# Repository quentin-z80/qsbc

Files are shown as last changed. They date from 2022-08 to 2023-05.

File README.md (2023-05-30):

# qsbc

## Specs

- i.MX8M Mini 4x 1.8GHz ARM Cortex-A53
- 4GB LPDDR4
- 4MB QSPI Flash
- 64GB eMMC
- M.2 2230 Slot
- MicroSD card slot
- 2x USB Type-C DRP
- USB Type-C Power in
- USB Type-C debug port
- 10/100/1000 Ethernet
- Displayport output





## Flashing u-boot

1. Get `u-boot`

    ```
    git clone https://gitlab.com/quentin-z80/u-boot.git
    ```

2. Build `TF-A`

    ```
    git clone https://git.trustedfirmware.org/TF-A/trusted-firmware-a.git
    cd trusted-firmware-a
    TF_LDFLAGS="--no-warn-rwx-segment" make plat=imx8mm bl31
    cp build/imx8mm/release/bl31.bin ../u-boot/
    ```

3. Get i.MX8MM DDR Firmware

    ```
    wget https://www.nxp.com/lgfiles/NMG/MAD/YOCTO/firmware-imx-8.9.bin
    chmod +x firmware-imx-8.9.bin
    ./firmware-imx-8.9.bin
    cp firmware-imx-8.9/firmware/ddr/synopsys/lpddr4*.bin u-boot/
    ```

4. Build `u-boot` for SD card boot

    ```
    cd u-boot
    export CROSS_COMPILE=aarch64-linux-gnu- ARCH=arm64
    make qsbc_imx8mm_defconfig
    make
    sudo dd if=flash.bin of=/dev/mmcblk0 bs=1024 seek=32 conv=notrunc
    ```

5. Flash and boot `u-boot` from sd card

    ```
    sudo dd if=flash.bin of=/dev/mmcblk0 bs=1024 seek=32 conv=notrunc
    sudo tio -b 115200 /dev/ttyACM0
    ```

6. Build `u-boot` for QSPI boot

    ```
    make qsbc_imx8mm_fspi_defconfig
    make
    ```

7. Flash `u-boot` to QSPI

    ```
    u-boot=> run dfuspi
    sudo dfu-util -D flash.bin
    ```

## TODO

- USB-UART ICs need to have VDDIO derived from USB VBUS so they do not reset
on board reset (or find a different ic)

- USB VBUS fault pins need to be connected to usb phy oc pads, not gpio pins

- UART1 TXO is connected to the wrong pad

- Test displayport out, waiting for better sn65dsi86 avalability

- optimize bom, replace 0201s with 0402s where there is space / no si limitations

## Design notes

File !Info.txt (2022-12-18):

/-----------------------------------------------------------------------------------------------------------------------------------\
|            |                  Single Ended                       |                        Differential                            |
|   Layer    |-----------------------------------------------------|----------------------------------------------------------------|
|            |  Width (mm)  |  Impedance (Ohms)  |    Ref Plane    |  Width (mm)  |  Space (mm)  |  Impedance (Ohms)  |  Ref Plane  |
|------------|--------------|--------------------|-----------------|--------------|--------------|--------------------|-------------|
|            |  0.11        |       50R          |     L2_IN1      |    0.08      |   0.15       |       100R         |   L2_IN1    |
|  L1_TOP    |              |                    |                 |    0.1       |   0.15       |        90R         |   L2_IN1    |
|            |              |                    |                 |    0.11      |   0.15       |        85R         |   L2_IN1    |
|------------|--------------|--------------------|-----------------|--------------|--------------|--------------------|-------------|
|  L3_IN2    |  0.08        |       50R          | L2_IN1 / L4_IN3 |              |              |                    |             |
|------------|--------------|--------------------|-----------------|--------------|--------------|--------------------|-------------|
|            |  0.11        |       50R          |     L7_IN6      |    0.08      |   0.15       |       100R         |   L7_IN6    |
|  L8_BOTTOM |              |                    |                 |    0.1       |   0.15       |        90R         |   L7_IN6    |
|            |              |                    |                 |    0.11      |   0.15       |        85R         |   L7_IN6    |
\-----------------------------------------------------------------------------------------------------------------------------------/

PCB Thickness - 1.2mm +/- 10%
Size: 80x80mm
Layers: 8
Min Trace Width / Space: 0.762mm
Min Via: 0.2mm drill, 0.4mm pad
Plating: ENIG
Soldermask: Green
Silkscreen: White, Top and Bottom

Stackup:

/--------------------------------------------------\
|         |            |        |           |      |
|  Layer  |  Material  |  Type  | Thickness |  Dk  |
|         |            |        |           |      |
|--------------------------------------------------|
|   L1    |   Copper   | Signal |  1oz      |      |
|---------|------------|--------|-----------|------|
| Prepreg |   370HR    |        |  0.07mm   | 4.04 |
|---------|------------|--------|-----------|------|
|   L2    |   Copper   |  GND   |  1oz      |      |
|---------|------------|--------|-----------|------|
|  Core   |   370HR    |        |  0.12mm   | 4.04 |
|---------|------------|--------|-----------|------|
|   L3    |   Copper   | Signal |  1oz      |      |
|---------|------------|--------|-----------|------|
| Prepreg |   370HR    |        |  0.16mm   | 4.04 |
|---------|------------|--------|-----------|------|
|   L4    |   Copper   |  GND   |  1oz      |      |
|---------|------------|--------|-----------|------|
|  Core   |   370HR    |        |  0.3mm    | 4.04 |
|---------|------------|--------|-----------|------|
|   L5    |   Copper   |  PWR   |  1oz      |      |
|---------|------------|--------|-----------|------|
| Prepreg |   370HR    |        |  0.16mm   | 4.04 |
|---------|------------|--------|-----------|------|
|   L6    |   Copper   |  PWR   |  1oz      |      |
|---------|------------|--------|-----------|------|
|  Core   |   370HR    |        |  0.12mm   | 4.04 |
|---------|------------|--------|-----------|------|
|   L7    |   Copper   |  GND   |  1oz      |      |
|---------|------------|--------|-----------|------|
| Prepreg |   370HR    |        |  0.07mm   | 4.04 |
|---------|------------|--------|-----------|------|
|   L8    |   Copper   | Signal |  1oz      |      |
\--------------------------------------------------/

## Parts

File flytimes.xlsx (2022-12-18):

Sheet: DDR_A
Group | Net | Vias | Layers | Track Length | Via Length | Total Length | Track Delay | Via Delay | Package Delay | Extra Delay | Total Delay | Notes
Clock | DRAM_CK_A_N | 2 | F.Cu, B.Cu | 19.58 | 2.4 | 21.98 | 109.55 | 31.84 | 41.2 | -2.81 | 179.78
Clock | DRAM_CK_A_P | 2 | F.Cu, B.Cu | 19.56 | 2.4 | 21.96 | 109.33 | 31.84 | 41.1 | -2.81 | 179.46
Byte Lane 1 – DQS | DRAM_DQS1_A_N | 2 | F.Cu, B.Cu | 11.87 | 2.4 | 14.27 | 66.39 | 31.84 | 47.2 | 0 | 145.43
Byte Lane 1 – DQS | DRAM_DQS1_A_P | 2 | F.Cu, B.Cu | 11.6 | 2.4 | 14 | 64.89 | 31.84 | 48.6 | 0 | 145.33
Byte Lane 1 | DRAM_D11_A | 0 | F.Cu | 17.59 | 0 | 17.59 | 98.22 | 0 | 47.2 | 0 | 145.42
Byte Lane 1 | DRAM_D12_A | 0 | F.Cu | 18.84 | 0 | 18.84 | 105.12 | 0 | 40.3 | 0 | 145.42
Byte Lane 1 | DRAM_DMI1_A | 0 | F.Cu | 15.53 | 0 | 15.53 | 86.75 | 0 | 58.6 | 0 | 145.35
Byte Lane 1 | DRAM_D15_A | 0 | F.Cu | 16.65 | 0 | 16.65 | 92.94 | 0 | 52.4 | 0 | 145.34
Byte Lane 1 | DRAM_D13_A | 0 | F.Cu | 17.28 | 0 | 17.28 | 96.54 | 0 | 48.8 | 0 | 145.34
Byte Lane 1 | DRAM_D08_A | 0 | F.Cu | 17.97 | 0 | 17.97 | 100.32 | 0 | 45 | 0 | 145.32
Byte Lane 1 | DRAM_D09_A | 0 | F.Cu | 17.05 | 0 | 17.05 | 95.19 | 0 | 50.1 | 0 | 145.29
Byte Lane 1 | DRAM_D10_A | 0 | F.Cu | 17.74 | 0 | 17.74 | 99.09 | 0 | 46.2 | 0 | 145.29
Byte Lane 1 | DRAM_D14_A | 0 | F.Cu | 15.55 | 0 | 15.55 | 86.87 | 0 | 58.4 | 0 | 145.27
Byte Lane 0 – DQS | DRAM_DQS0_A_P | 2 | F.Cu, B.Cu | 17.7 | 2.4 | 20.1 | 99.04 | 31.84 | 59 | 0 | 189.88
Byte Lane 0 – DQS | DRAM_DQS0_A_N | 2 | F.Cu, B.Cu | 17.7 | 2.4 | 20.1 | 98.94 | 31.84 | 58.9 | 0 | 189.68
Byte Lane 0 | DRAM_D03_A | 2 | F.Cu, In2.Cu | 20.48 | 0.4 | 20.88 | 134.13 | 4.01 | 51.7 | 0 | 189.84
Byte Lane 0 | DRAM_D07_A | 2 | F.Cu, In2.Cu | 20.76 | 0.4 | 21.16 | 134.4 | 4.01 | 51.4 | 0 | 189.81
Byte Lane 0 | DRAM_D05_A | 2 | F.Cu, In2.Cu | 19.49 | 0.4 | 19.89 | 127.69 | 4.01 | 58.1 | 0 | 189.8
Byte Lane 0 | DRAM_D04_A | 2 | F.Cu, In2.Cu | 19.15 | 0.4 | 19.55 | 125.88 | 4.01 | 59.9 | 0 | 189.79
Byte Lane 0 | DRAM_D02_A | 2 | F.Cu, In2.Cu | 20.02 | 0.4 | 20.42 | 131.15 | 4.01 | 54.6 | 0 | 189.76
Byte Lane 0 | DRAM_DMI0_A | 2 | F.Cu, In2.Cu | 19.49 | 0.4 | 19.89 | 128.39 | 4.01 | 57.2 | 0 | 189.6
Byte Lane 0 | DRAM_D00_A | 2 | F.Cu, In2.Cu | 21.85 | 0.4 | 22.25 | 143.01 | 4.01 | 42.7 | 0 | 189.72
Byte Lane 0 | DRAM_D01_A | 2 | F.Cu, In2.Cu | 22.23 | 0.4 | 22.63 | 142.7 | 4.01 | 43 | 0 | 189.71
Byte Lane 0 | DRAM_D06_A | 2 | F.Cu, In2.Cu | 18.73 | 0.4 | 19.13 | 121.06 | 4.01 | 64.6 | 0 | 189.67
Address, Command and Control | DRAM_CA3_A | 2 | F.Cu, In2.Cu | 18.49 | 0.4 | 18.89 | 122.87 | 4.01 | 59.7 | 0 | 186.58
Address, Command and Control | ~{DRAM_CS1_A} | 2 | F.Cu, In2.Cu | 20.79 | 0.4 | 21.19 | 138.35 | 4.01 | 44.2 | 0 | 186.56
Address, Command and Control | DRAM_CA1_A | 2 | F.Cu, In2.Cu | 23.05 | 0.4 | 23.45 | 153.43 | 4.01 | 29.1 | 0 | 186.54
Address, Command and Control | DRAM_CA4_A | 2 | F.Cu, In2.Cu | 22.35 | 0.4 | 22.75 | 148.72 | 4.01 | 33.8 | 0 | 186.53
Address, Command and Control | ~{DRAM_CS0_A} | 2 | F.Cu, In2.Cu | 22.03 | 0.4 | 22.43 | 146.6 | 4.01 | 35.9 | 0 | 186.51
Address, Command and Control | DRAM_CA2_A | 2 | F.Cu, In2.Cu | 19.2 | 0.4 | 19.6 | 127.66 | 4.01 | 54.8 | 0 | 186.47
Address, Command and Control | DRAM_CA5_A | 2 | F.Cu, In2.Cu | 22.59 | 0.4 | 22.99 | 150.45 | 4.01 | 32 | 0 | 186.46
Address, Command and Control | DRAM_CKE0_A | 2 | F.Cu, In2.Cu, B.Cu | 20.14 | 1.4 | 21.54 | 133.54 | 17.92 | 51.2 | -16.23 | 186.43
Address, Command and Control | DRAM_CA0_A | 2 | F.Cu, In2.Cu | 21.47 | 0.4 | 21.87 | 142.81 | 4.01 | 39.6 | 0 | 186.42
Address, Command and Control | DRAM_CKE1_A | 2 | F.Cu, In2.Cu, B.Cu | 21.82 | 1.4 | 23.22 | 144.79 | 17.92 | 39.9 | -16.23 | 186.38

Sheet: DDR_B
Group | Net | Vias | Layers | Track Length | Via Length | Total Length | Track Delay | Via Delay | Package Delay | Extra Delay | Total Delay | Notes
Clock | DRAM_CK_B_N | 2 | F.Cu, B.Cu | 19.43 | 2.4 | 21.83 | 108.71 | 31.84 | 42.2 | -2.81 | 179.94
Clock | DRAM_CK_B_P | 2 | F.Cu, B.Cu | 19.51 | 2.4 | 21.91 | 109.03 | 31.84 | 41.8 | -2.81 | 179.86
Byte Lane 1 – DQS | DRAM_DQS1_B_P | 2 | F.Cu, B.Cu | 18.75 | 2.4 | 21.15 | 104.86 | 31.84 | 55.5 | 0 | 192.2
Byte Lane 1 – DQS | DRAM_DQS1_B_N | 2 | F.Cu, B.Cu | 18.83 | 2.4 | 21.23 | 105.25 | 31.84 | 55 | 0 | 192.09
Byte Lane 1 | DRAM_D08_B | 2 | F.Cu, In2.Cu | 19.43 | 0.4 | 19.83 | 128.14 | 4.01 | 60.2 | 0 | 192.35
Byte Lane 1 | DRAM_D12_B | 2 | F.Cu, In2.Cu | 19.86 | 0.4 | 20.26 | 129.31 | 4.01 | 59.1 | 0 | 192.42
Byte Lane 1 | DRAM_D13_B | 2 | F.Cu, In2.Cu | 20.08 | 0.4 | 20.48 | 130.32 | 4.01 | 58.1 | 0 | 192.43
Byte Lane 1 | DRAM_D10_B | 2 | F.Cu, In2.Cu | 21.62 | 0.4 | 22.02 | 139.44 | 4.01 | 48.8 | 0 | 192.25
Byte Lane 1 | DRAM_D14_B | 2 | F.Cu, In2.Cu | 20.89 | 0.4 | 21.29 | 138.24 | 4.01 | 50 | 0 | 192.25
Byte Lane 1 | DRAM_D09_B | 2 | F.Cu, In2.Cu | 20.78 | 0.4 | 21.18 | 136.92 | 4.01 | 51.3 | 0 | 192.23
Byte Lane 1 | DRAM_D11_B | 2 | F.Cu, In2.Cu | 19.94 | 0.4 | 20.34 | 130.2 | 4.01 | 58 | 0 | 192.21
Byte Lane 1 | DRAM_DMI1_B | 2 | F.Cu, In2.Cu | 20.41 | 0.4 | 20.81 | 135.06 | 4.01 | 53.1 | 0 | 192.17
Byte Lane 1 | DRAM_D15_B | 2 | F.Cu, In2.Cu | 21.96 | 0.4 | 22.36 | 143.93 | 4.01 | 44.2 | 0 | 192.14
Byte Lane 0 – DQS | DRAM_DQS0_B_P | 2 | F.Cu, B.Cu | 10.73 | 2.4 | 13.13 | 60.01 | 31.84 | 48.6 | 0 | 140.45
Byte Lane 0 – DQS | DRAM_DQS0_B_N | 2 | F.Cu, B.Cu | 10.71 | 2.4 | 13.11 | 59.93 | 31.84 | 48.6 | 0 | 140.37
Byte Lane 0 | DRAM_D06_B | 0 | F.Cu | 15.35 | 0 | 15.35 | 85.72 | 0 | 54.7 | 0 | 140.42
Byte Lane 0 | DRAM_D05_B | 0 | F.Cu | 16.22 | 0 | 16.22 | 90.6 | 0 | 49.8 | 0 | 140.4
Byte Lane 0 | DRAM_D03_B | 0 | F.Cu | 17.63 | 0 | 17.63 | 98.4 | 0 | 42 | 0 | 140.4
Byte Lane 0 | DRAM_D04_B | 0 | F.Cu | 15.55 | 0 | 15.55 | 86.79 | 0 | 53.6 | 0 | 140.39
Byte Lane 0 | DRAM_D00_B | 0 | F.Cu | 15.92 | 0 | 15.92 | 88.85 | 0 | 51.5 | 0 | 140.35
Byte Lane 0 | DRAM_D02_B | 0 | F.Cu | 15.37 | 0 | 15.37 | 85.85 | 0 | 54.5 | 0 | 140.35
Byte Lane 0 | DRAM_D01_B | 0 | F.Cu | 16.2 | 0 | 16.2 | 90.44 | 0 | 49.9 | 0 | 140.34
Byte Lane 0 | DRAM_D07_B | 0 | F.Cu | 16.54 | 0 | 16.54 | 92.33 | 0 | 48 | 0 | 140.33
Byte Lane 0 | DRAM_DMI0_B | 0 | F.Cu | 15.66 | 0 | 15.66 | 87.47 | 0 | 52.8 | 0 | 140.27
Address, Command and Control | DRAM_CA2_B | 2 | F.Cu, In2.Cu | 17.71 | 0.4 | 18.11 | 117.61 | 4.01 | 59.5 | 0 | 181.12
Address, Command and Control | DRAM_CA3_B | 2 | F.Cu, In2.Cu | 18.16 | 0.4 | 18.56 | 120.61 | 4.01 | 56.5 | 0 | 181.12
Address, Command and Control | DRAM_CA0_B | 2 | F.Cu, In2.Cu | 21.82 | 0.4 | 22.22 | 145.15 | 4.01 | 31.9 | 0 | 181.06
Address, Command and Control | ~{DRAM_CS0_B} | 2 | F.Cu, In2.Cu | 20.6 | 0.4 | 21 | 137.04 | 4.01 | 40 | 0 | 181.05
Address, Command and Control | ~{DRAM_CS1_B} | 2 | F.Cu, In2.Cu | 19.46 | 0.4 | 19.86 | 129.33 | 4.01 | 47.7 | 0 | 181.04
Address, Command and Control | DRAM_CKE1_B | 2 | F.Cu, In2.Cu, B.Cu | 19.35 | 1.4 | 20.75 | 128.08 | 17.92 | 51.6 | -16.57 | 181.03
Address, Command and Control | DRAM_CA5_B | 2 | F.Cu, In2.Cu | 20.89 | 0.4 | 21.29 | 138.42 | 4.01 | 38.6 | 0 | 181.03
Address, Command and Control | DRAM_CKE0_B | 2 | F.Cu, In2.Cu, B.Cu | 19.35 | 1.4 | 20.75 | 128.08 | 17.92 | 51.6 | -16.57 | 181.03
Address, Command and Control | DRAM_CA1_B | 2 | F.Cu, In2.Cu | 21.44 | 0.4 | 21.84 | 142.61 | 4.01 | 34.4 | 0 | 181.02
Address, Command and Control | DRAM_CA4_B | 2 | F.Cu, In2.Cu | 21.45 | 0.4 | 21.85 | 142.71 | 4.01 | 34.3 | 0 | 181.02

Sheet: eMMC
Group | Net | Vias | Layers | Track Length | Via Length | Total Length | Track Delay | Via Delay | Package Delay | Extra Delay | Total Delay | Notes
eMMC | SD3_CMD | 0 | F.Cu | 27.49 | 0 | 27.49 | 153.61 | 0 | 0 | 0 | 153.61
eMMC | SD3_CLK | 0 | F.Cu | 23.96 | 0 | 23.96 | 133.66 | 0 | 0 | 19.98 | 153.64
eMMC | SD3_DATA3 | 0 | F.Cu | 26.32 | 0 | 26.32 | 147.01 | 0 | 0 | 0 | 147.01
eMMC | SD3_DATA7 | 0 | F.Cu | 27.4 | 0 | 27.4 | 153.19 | 0 | 0 | 0 | 153.19
eMMC | SD3_DATA1 | 0 | F.Cu | 27.28 | 0 | 27.28 | 152.53 | 0 | 0 | 0 | 152.53
eMMC | SD3_DATA4 | 0 | F.Cu | 27.28 | 0 | 27.28 | 152.5 | 0 | 0 | 0 | 152.5
eMMC | SD3_DATA0 | 0 | F.Cu | 27.18 | 0 | 27.18 | 151.92 | 0 | 0 | 0 | 151.92
eMMC | SD3_DATA6 | 0 | F.Cu | 27.05 | 0 | 27.05 | 151.21 | 0 | 0 | 0 | 151.21
eMMC | SD3_DATA2 | 0 | F.Cu | 27.03 | 0 | 27.03 | 151.12 | 0 | 0 | 0 | 151.12
eMMC | SD3_STROBE | 0 | F.Cu | 26.97 | 0 | 26.97 | 150.59 | 0 | 0 | 0 | 150.59
eMMC | SD3_DATA5 | 0 | F.Cu | 26.95 | 0 | 26.95 | 150.67 | 0 | 0 | 0 | 150.67

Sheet: ENET
Group | Net | Vias | Layers | Track Length | Via Length | Total Length | Track Delay | Via Delay | Package Delay | Extra Delay | Total Delay | Notes
RGMII – TX | ENET_TD3 | 2 | F.Cu, In2.Cu | 13.98 | 0.4 | 14.38 | 85.14 | 4.01 | 0 | 0 | 89.15
RGMII – TX | ENET_TXC | 2 | F.Cu, In2.Cu | 13 | 0.4 | 13.4 | 82.98 | 4.01 | 0 | 0 | 86.99
RGMII – TX | ENET_TD2 | 2 | F.Cu, In2.Cu | 13.37 | 0.4 | 13.77 | 83.73 | 4.01 | 0 | 0 | 87.74
RGMII – TX | ENET_TD0 | 2 | F.Cu, In2.Cu | 13.37 | 0.4 | 13.77 | 81.97 | 4.01 | 0 | 0 | 85.98
RGMII – TX | ENET_TD1 | 2 | F.Cu, In2.Cu | 13.48 | 0.4 | 13.88 | 81.55 | 4.01 | 0 | 0 | 85.56
RGMII – TX | ENET_TX_CTL | 2 | F.Cu, In2.Cu | 13.07 | 0.4 | 13.47 | 82.35 | 4.01 | 0 | 0 | 86.36
RGMII – RX | ENET_RX_CTL | 0 | F.Cu | 15.35 | 0 | 15.35 | 85.86 | 0 | 0 | 0 | 85.86
RGMII – RX | ENET_RXC | 2 | F.Cu, B.Cu | 13.5 | 2.4 | 15.9 | 75.54 | 31.84 | 0 | 0 | 107.38
RGMII – RX | ENET_RD3 | 0 | F.Cu | 16.41 | 0 | 16.41 | 91.7 | 0 | 0 | 0 | 91.7
RGMII – RX | ENET_RD2 | 0 | F.Cu | 15 | 0 | 15 | 83.79 | 0 | 0 | 0 | 83.79
RGMII – RX | ENET_RD0 | 0 | F.Cu | 14.94 | 0 | 14.94 | 83.57 | 0 | 0 | 0 | 83.57
RGMII – RX | ENET_RD1 | 2 | F.Cu, In2.Cu | 15.91 | 0.4 | 16.31 | 93.45 | 4.01 | 0 | 0 | 97.46
MDI3 | TRD3_P | 2 | F.Cu, B.Cu | 23.04 | 2.4 | 25.44 | 126.64 | 31.84 | 0 | 0 | 158.48
MDI3 | TRD3_N | 2 | F.Cu, B.Cu | 23.04 | 2.4 | 25.44 | 126.64 | 31.84 | 0 | 0 | 158.48
MDI2 | TRD2_P | 2 | F.Cu, B.Cu | 22.55 | 2.4 | 24.95 | 123.92 | 31.84 | 0 | 0 | 155.76
MDI2 | TRD2_N | 2 | F.Cu, B.Cu | 22.55 | 2.4 | 24.95 | 123.92 | 31.84 | 0 | 0 | 155.76
MDI1 | TRD1_P | 2 | F.Cu, B.Cu | 22.65 | 2.4 | 25.05 | 124.48 | 31.84 | 0 | 0 | 156.32
MDI1 | TRD1_N | 2 | F.Cu, B.Cu | 22.65 | 2.4 | 25.05 | 124.48 | 31.84 | 0 | 0 | 156.32
MDI0 | TRD0_P | 0 | F.Cu | 21.22 | 0 | 21.22 | 116.61 | 0 | 0 | 0 | 116.61
MDI0 | TRD0_N | 0 | F.Cu | 21.22 | 0 | 21.22 | 116.61 | 0 | 0 | 0 | 116.61

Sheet: SD
!# | Net | Vias | Layers | Track Length | Via Length | Total Length | Track Delay | Via Delay | Package Delay | Extra Delay | Total Delay | Notes
SD | SD2_CLK | 1 | F.Cu, B.Cu | 63.3 | 1.2 | 64.5 | 354.08 | 15.92 | 0 | 28.83 | 398.83
SD | SD2_CMD | 2 | F.Cu, B.Cu | 65.73 | 2.4 | 68.13 | 367.7 | 31.84 | 0 | 0 | 399.54
SD | SD2_DATA0 | 2 | F.Cu, B.Cu | 65.79 | 2.4 | 68.19 | 368 | 31.84 | 0 | 0 | 399.84
SD | SD2_DATA1 | 2 | F.Cu, B.Cu | 65.6 | 2.4 | 68 | 366.95 | 31.84 | 0 | 0 | 398.79
SD | SD2_DATA3 | 2 | F.Cu, B.Cu | 65.45 | 2.4 | 67.85 | 366.1 | 31.84 | 0 | 0 | 397.94
SD | SD2_DATA2 | 2 | F.Cu, B.Cu | 65.33 | 2.4 | 67.73 | 365.46 | 31.84 | 0 | 0 | 397.3

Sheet: QSPI
Group | Net | Vias | Layers | Track Length | Via Length | Total Length | Track Delay | Via Delay | Package Delay | Extra Delay | Total Delay | Notes
QSPI | ~{QSPI_CS0} | 2 | F.Cu, In2.Cu | 44.52 | 0.4 | 44.92 | 282.35 | 4.01 | 0 | 0 | 286.36
QSPI | QSPI_CLK | 2 | F.Cu, In2.Cu | 42.34 | 0.4 | 42.74 | 282.11 | 4.01 | 0 | 0 | 286.12
QSPI | QSPI_DATA0 | 2 | F.Cu, In2.Cu | 42.48 | 0.4 | 42.88 | 283.05 | 4.01 | 0 | 0 | 287.06
QSPI | QSPI_DATA1 | 2 | F.Cu, In2.Cu | 42.48 | 0.4 | 42.88 | 280.82 | 4.01 | 0 | 0 | 284.83
QSPI | QSPI_DATA2 | 2 | F.Cu, In2.Cu | 42.55 | 0.4 | 42.95 | 283.62 | 4.01 | 0 | 0 | 287.63
QSPI | QSPI_DATA3 | 2 | F.Cu, In2.Cu | 43.08 | 0.4 | 43.48 | 287.08 | 4.01 | 0 | 0 | 291.09

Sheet: USB
Group | Net | Vias | Layers | Track Length | Via Length | Total Length | Track Delay | Via Delay | Package Delay | Extra Delay | Total Delay | Notes
USB1 | USB1_DN | 2 | F.Cu, B.Cu | 96.57 | 2.4 | 98.97 | 537.15 | 31.84 | 0 | -16.36 | 552.63
USB1 | USB1_DP | 2 | F.Cu, B.Cu | 95.68 | 2.4 | 98.08 | 532.17 | 31.84 | 0 | -10.92 | 553.09
USB2 | USB2_DN | 2 | F.Cu, B.Cu | 81.17 | 2.4 | 83.57 | 451.5 | 31.84 | 0 | -16.36 | 466.98
USB2 | USB2_DP | 2 | F.Cu, B.Cu | 80.3 | 2.4 | 82.7 | 446.58 | 31.84 | 0 | -10.92 | 467.5
USB3 | USB3_DN | 0 | F.Cu, B.Cu | 17.55 | 0 | 17.55 | 97.62 | 0 | 0 | -20.04 | 77.58
USB3 | USB3_DP | 0 | F.Cu | 14.39 | 0 | 14.39 | 80.03 | 0 | 0 | -2.5 | 77.53
USB4 | USB4_DN | 2 | F.Cu, B.Cu | 42.03 | 2.4 | 44.43 | 233.8 | 31.84 | 0 | -15.58 | 250.06
USB4 | USB4_DP | 0 | F.Cu | 45.78 | 0 | 45.78 | 254.67 | 0 | 0 | -10.92 | 243.75

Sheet: Display
Group | Net | Vias | Layers | Track Length | Via Length | Total Length | Track Delay | Via Delay | Package Delay | Extra Delay | Total Delay | Notes
ML0 | ML0_N | 0 | F.Cu | 5.62 | 0 | 5.62 | 30.89 | 0 | 0 | 0 | 30.89
ML0 | ML0_P | 0 | F.Cu | 5.62 | 0 | 5.62 | 30.89 | 0 | 0 | 0 | 30.89
ML1 | ML1_N | 0 | F.Cu | 4.94 | 0 | 4.94 | 27.13 | 0 | 0 | 0 | 27.13
ML1 | ML1_P | 0 | F.Cu | 4.94 | 0 | 4.94 | 27.13 | 0 | 0 | 0 | 27.13
ML2 | ML2_N | 0 | F.Cu | 4.8 | 0 | 4.8 | 26.36 | 0 | 0 | 0 | 26.36
ML2 | ML2_P | 0 | F.Cu | 4.8 | 0 | 4.8 | 26.36 | 0 | 0 | 0 | 26.36
ML3 | ML3_N | 0 | F.Cu | 4.67 | 0 | 4.67 | 25.65 | 0 | 0 | 0 | 25.65
ML3 | ML3_P | 0 | F.Cu | 4.67 | 0 | 4.67 | 25.65 | 0 | 0 | 0 | 25.65
DSI0 | DSI_D0_N | 0 | F.Cu | 17.16 | 0 | 17.16 | 94.24 | 0 | 0 | 0 | 94.24
DSI0 | DSI_D0_P | 0 | F.Cu | 17.16 | 0 | 17.16 | 94.24 | 0 | 0 | 0 | 94.24
DSI1 | DSI_D1_N | 0 | F.Cu | 18.22 | 0 | 18.22 | 100.09 | 0 | 0 | 0 | 100.09
DSI1 | DSI_D1_P | 0 | F.Cu | 18.22 | 0 | 18.22 | 100.09 | 0 | 0 | 0 | 100.09
DSI2 | DSI_D2_N | 0 | F.Cu | 21.19 | 0 | 21.19 | 116.35 | 0 | 0 | 0 | 116.35
DSI2 | DSI_D2_P | 0 | F.Cu | 21.19 | 0 | 21.19 | 116.35 | 0 | 0 | 0 | 116.35
DSI3 | DSI_D3_N | 0 | F.Cu | 22.87 | 0 | 22.87 | 125.61 | 0 | 0 | 0 | 125.61
DSI3 | DSI_D3_P | 0 | F.Cu | 22.87 | 0 | 22.87 | 125.61 | 0 | 0 | 0 | 125.61
DSI_CK | DSI_CLK_N | 0 | F.Cu | 19.82 | 0 | 19.82 | 108.87 | 0 | 0 | 0 | 108.87
DSI_CK | DSI_CLK_P | 0 | F.Cu | 19.77 | 0 | 19.77 | 108.58 | 0 | 0 | 0 | 108.58

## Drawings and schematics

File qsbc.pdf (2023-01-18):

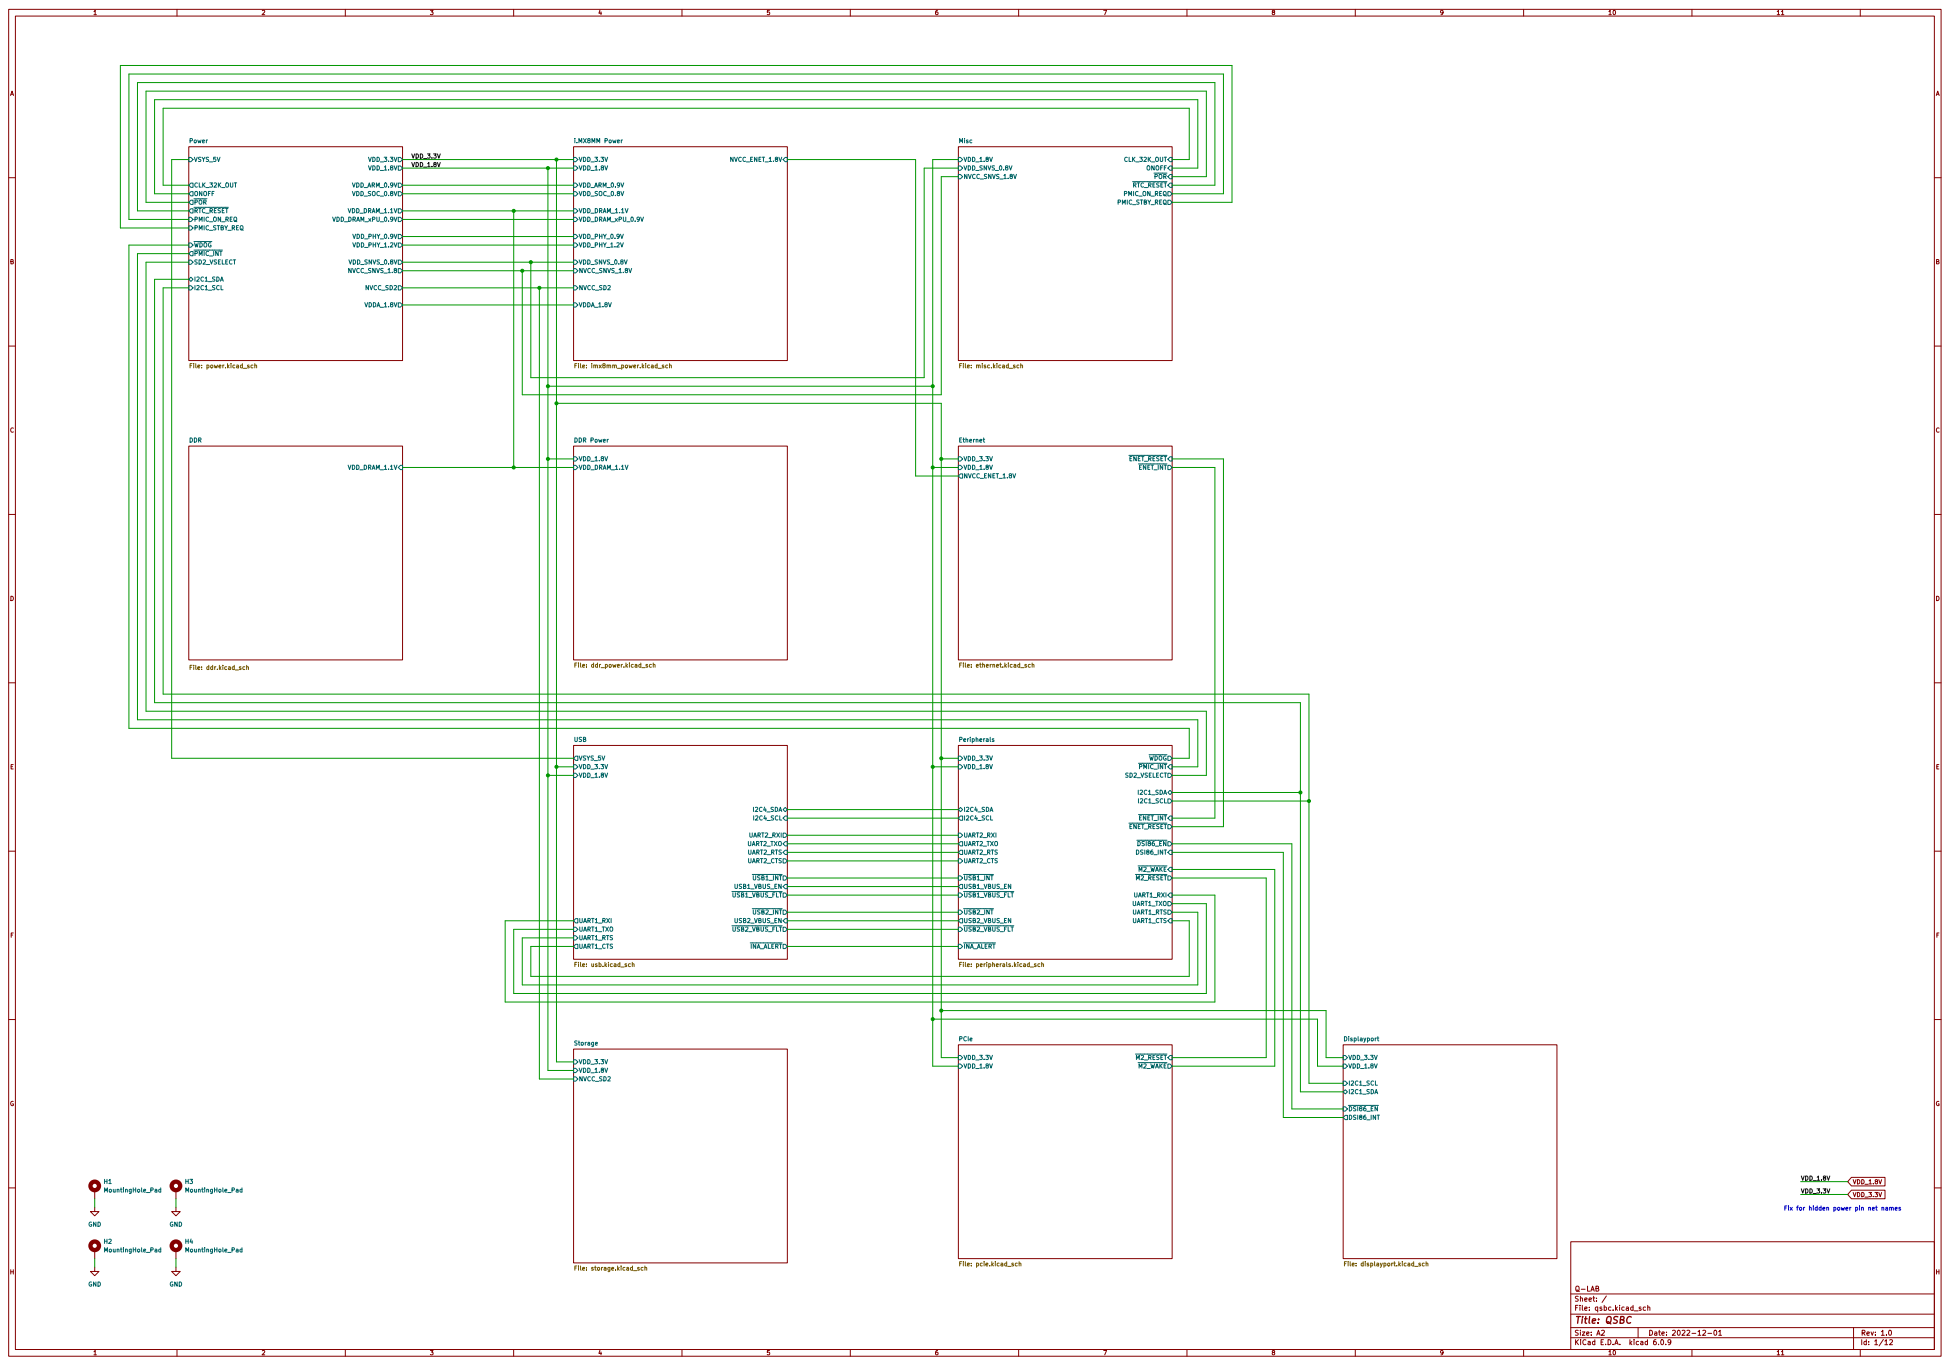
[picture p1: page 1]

~{POR} ~{RTC_RESET} ONOFF PMIC_STBY_REQ Misc File: misc.kicad_sch VDD_PHY_1.2V

Fix for hidden power pin net names

File: qsbc.kicad_sch Sheet: / Q-LAB

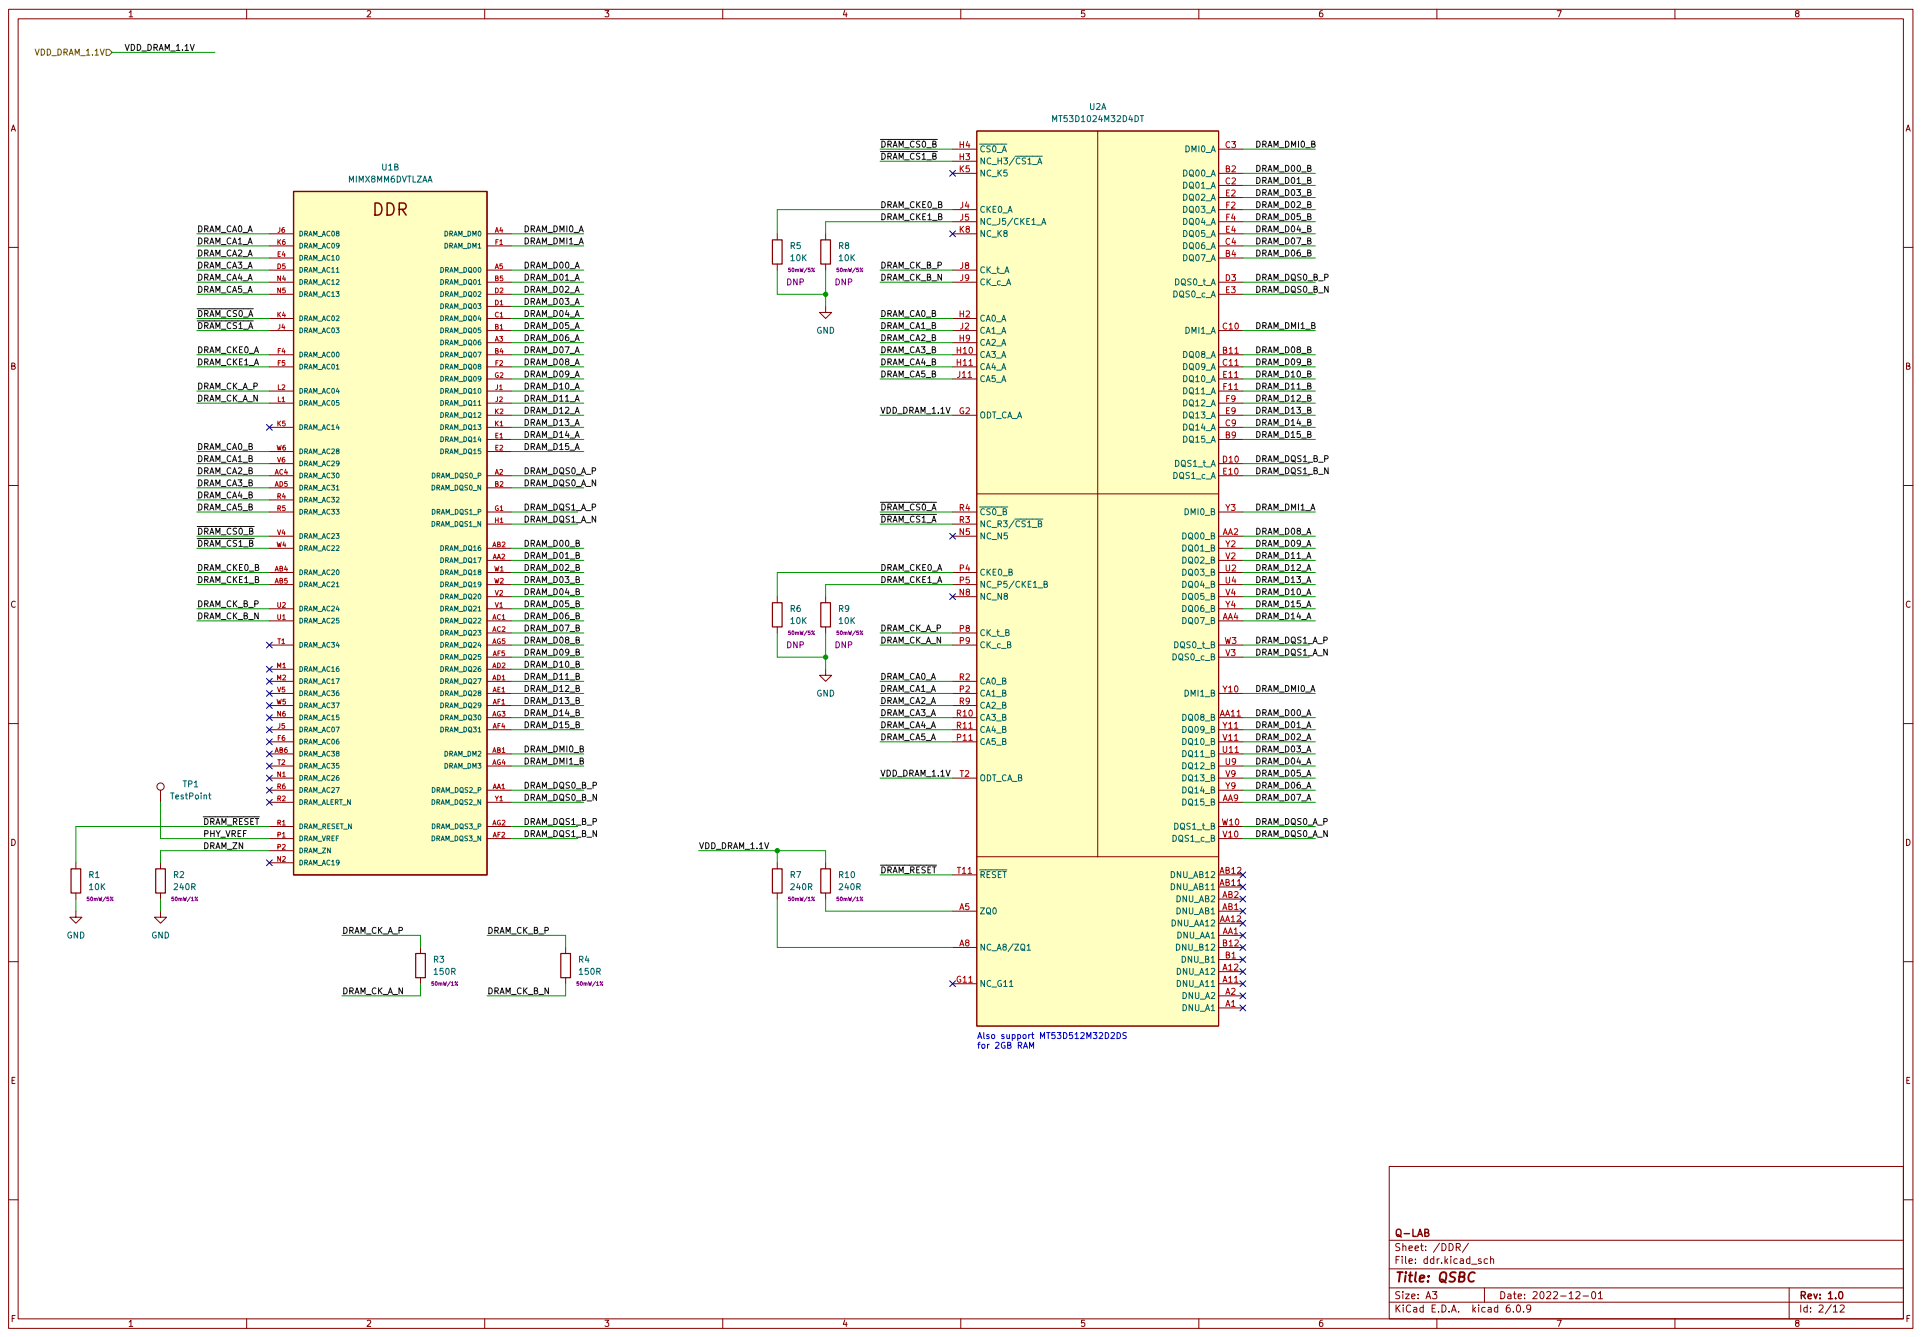
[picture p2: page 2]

File: ddr.kicad_sch Sheet: /DDR/ Q-LAB

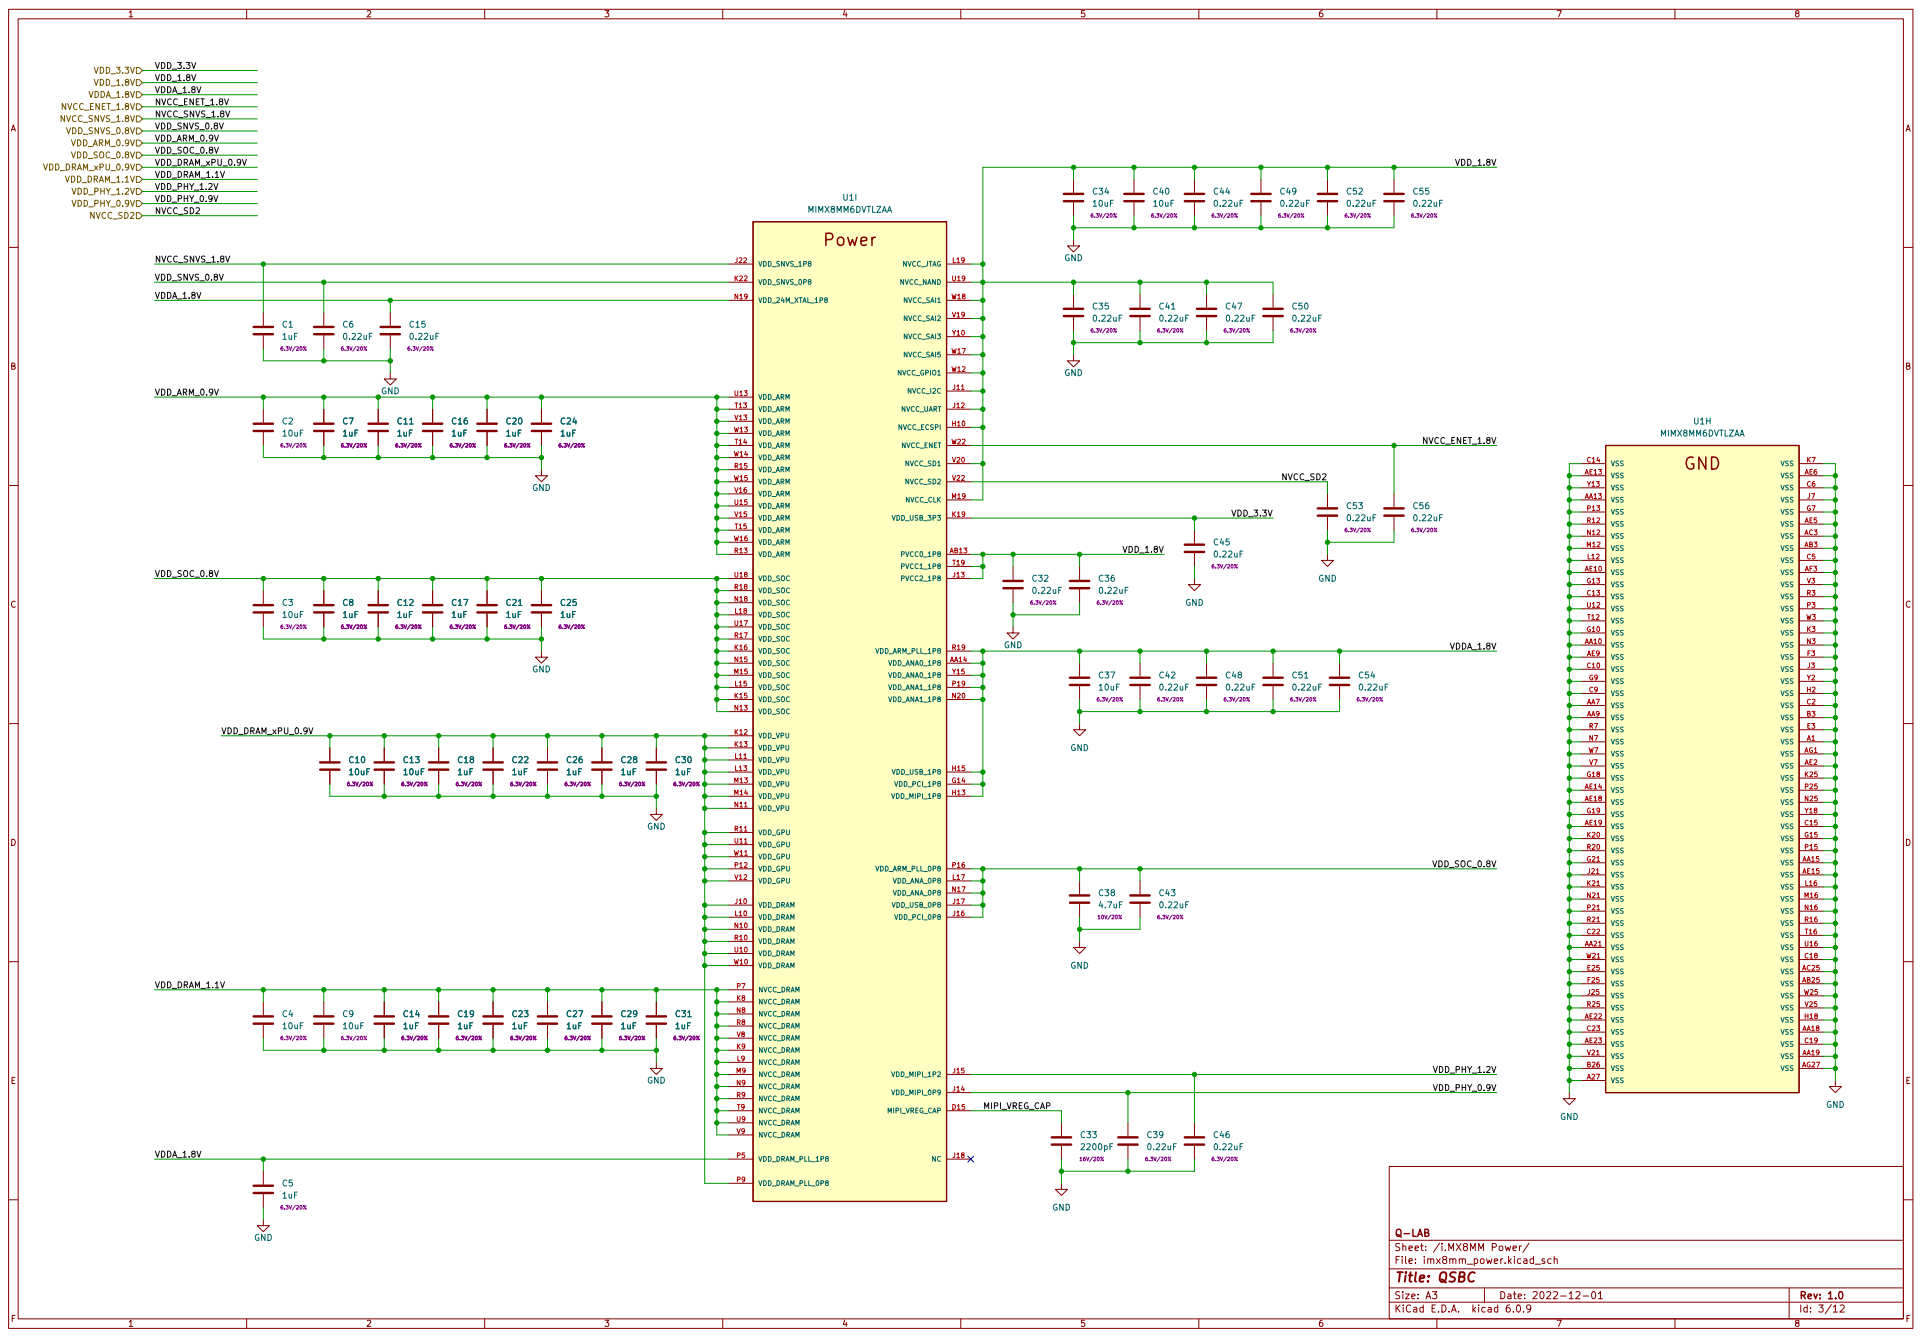
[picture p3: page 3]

NVCC_DRAM V8 NVCC_DRAM V9 VDD_DRAM W10 VDD_GPU W11
NVCC_DRAM U9 VDD_GPU V12

File: imx8mm_power.kicad_sch Sheet: /i.MX8MM Power/ Q-LAB

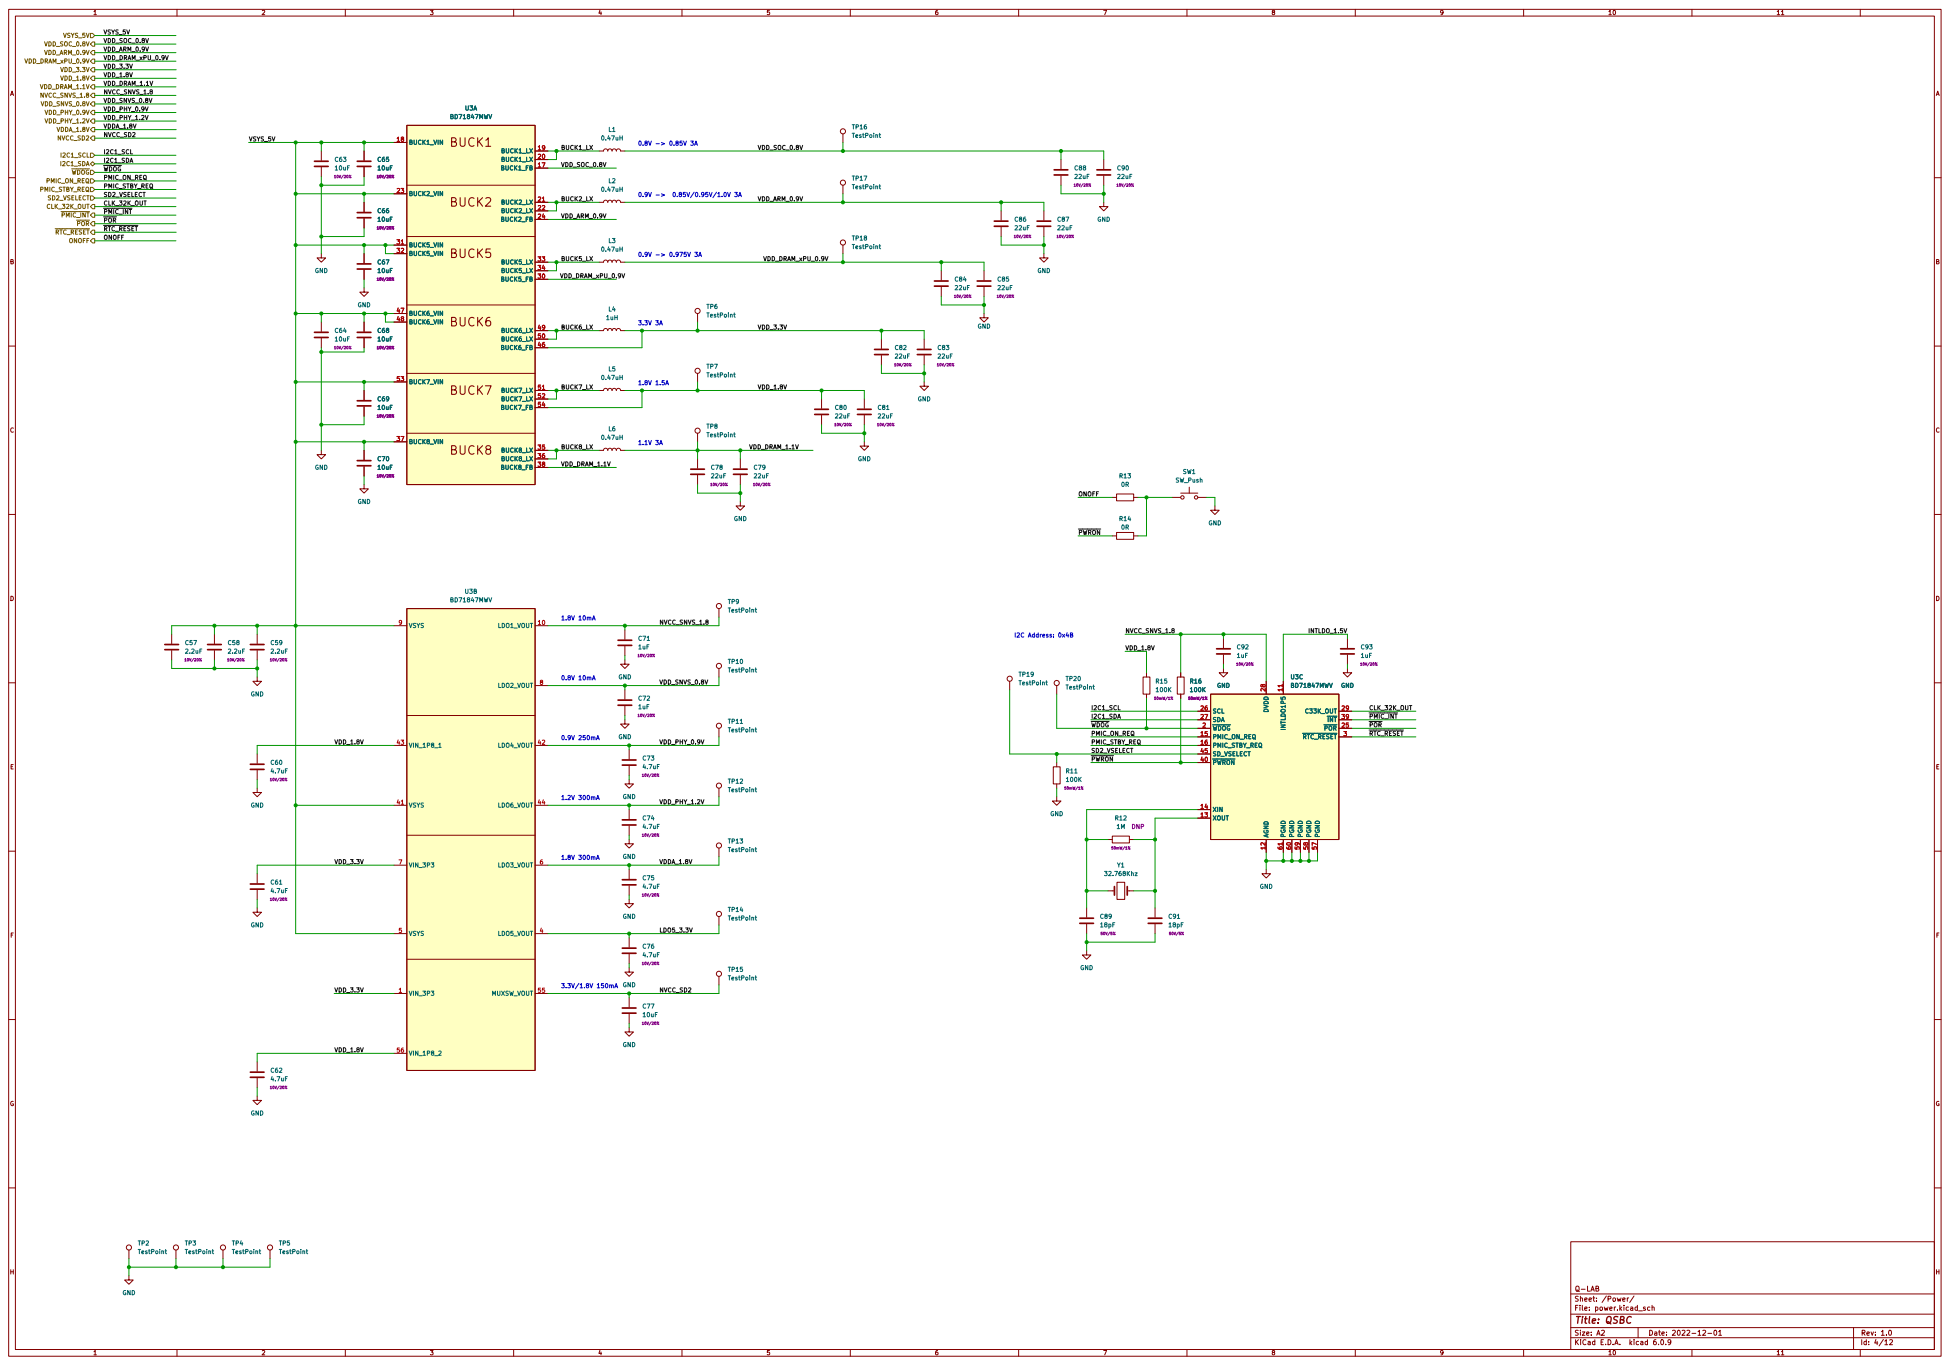
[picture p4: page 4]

VDD_ARM_0.9V CLK_32K_OUT PMIC_STBY_REQ
~{POR} ONOFF VDD_DRAM_xPU_0.9V
TP18 TestPoint TP16 TestPoint TP17 TestPoint GND

File: power.kicad_sch Sheet: /Power/ Q-LAB

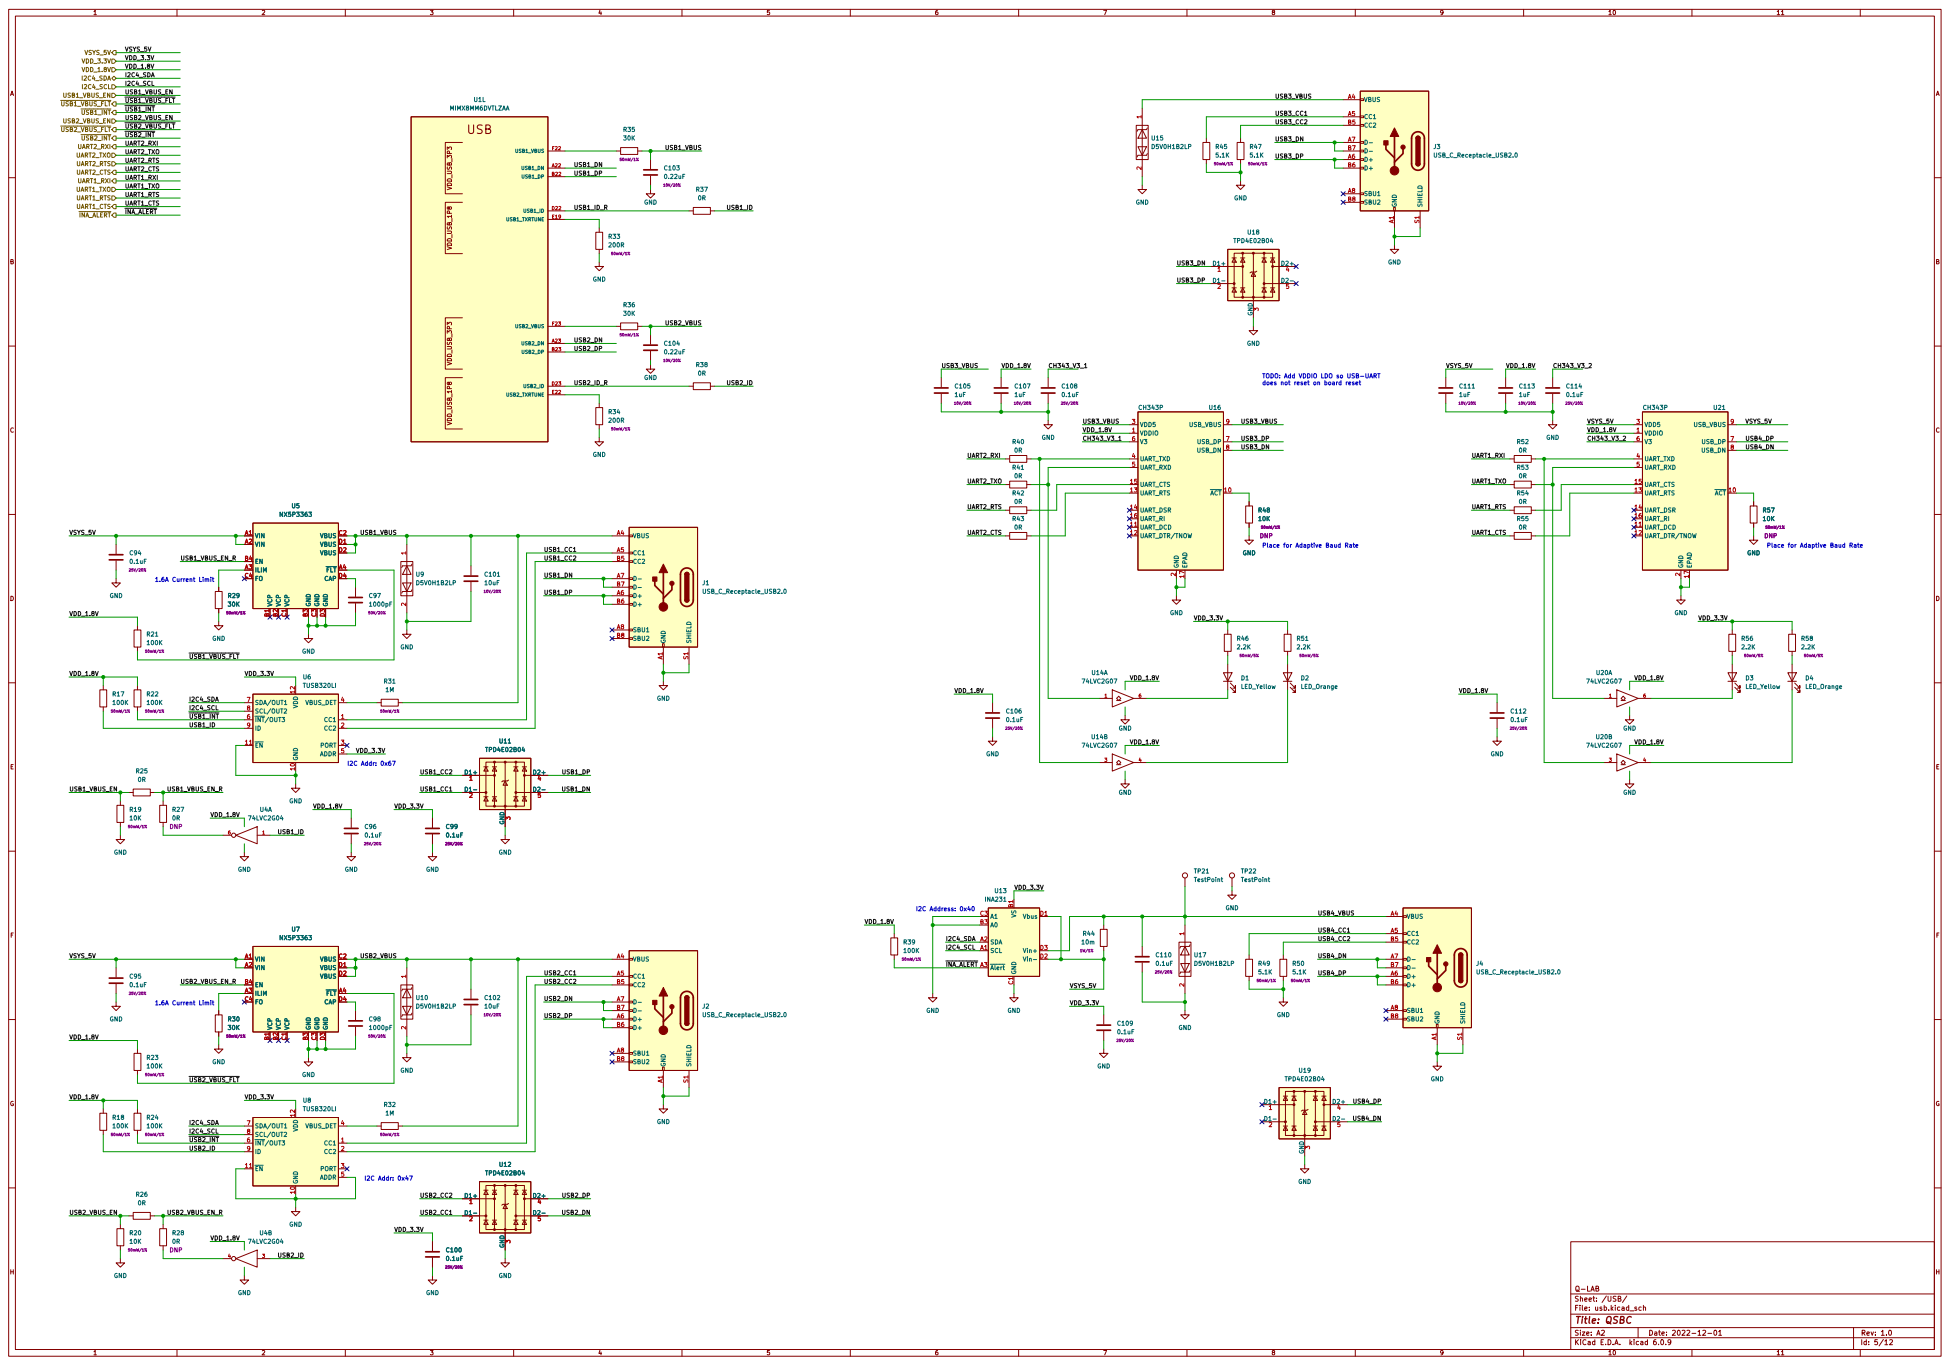
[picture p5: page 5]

does not reset on board reset

File: usb.kicad_sch Sheet: /USB/ Q-LAB

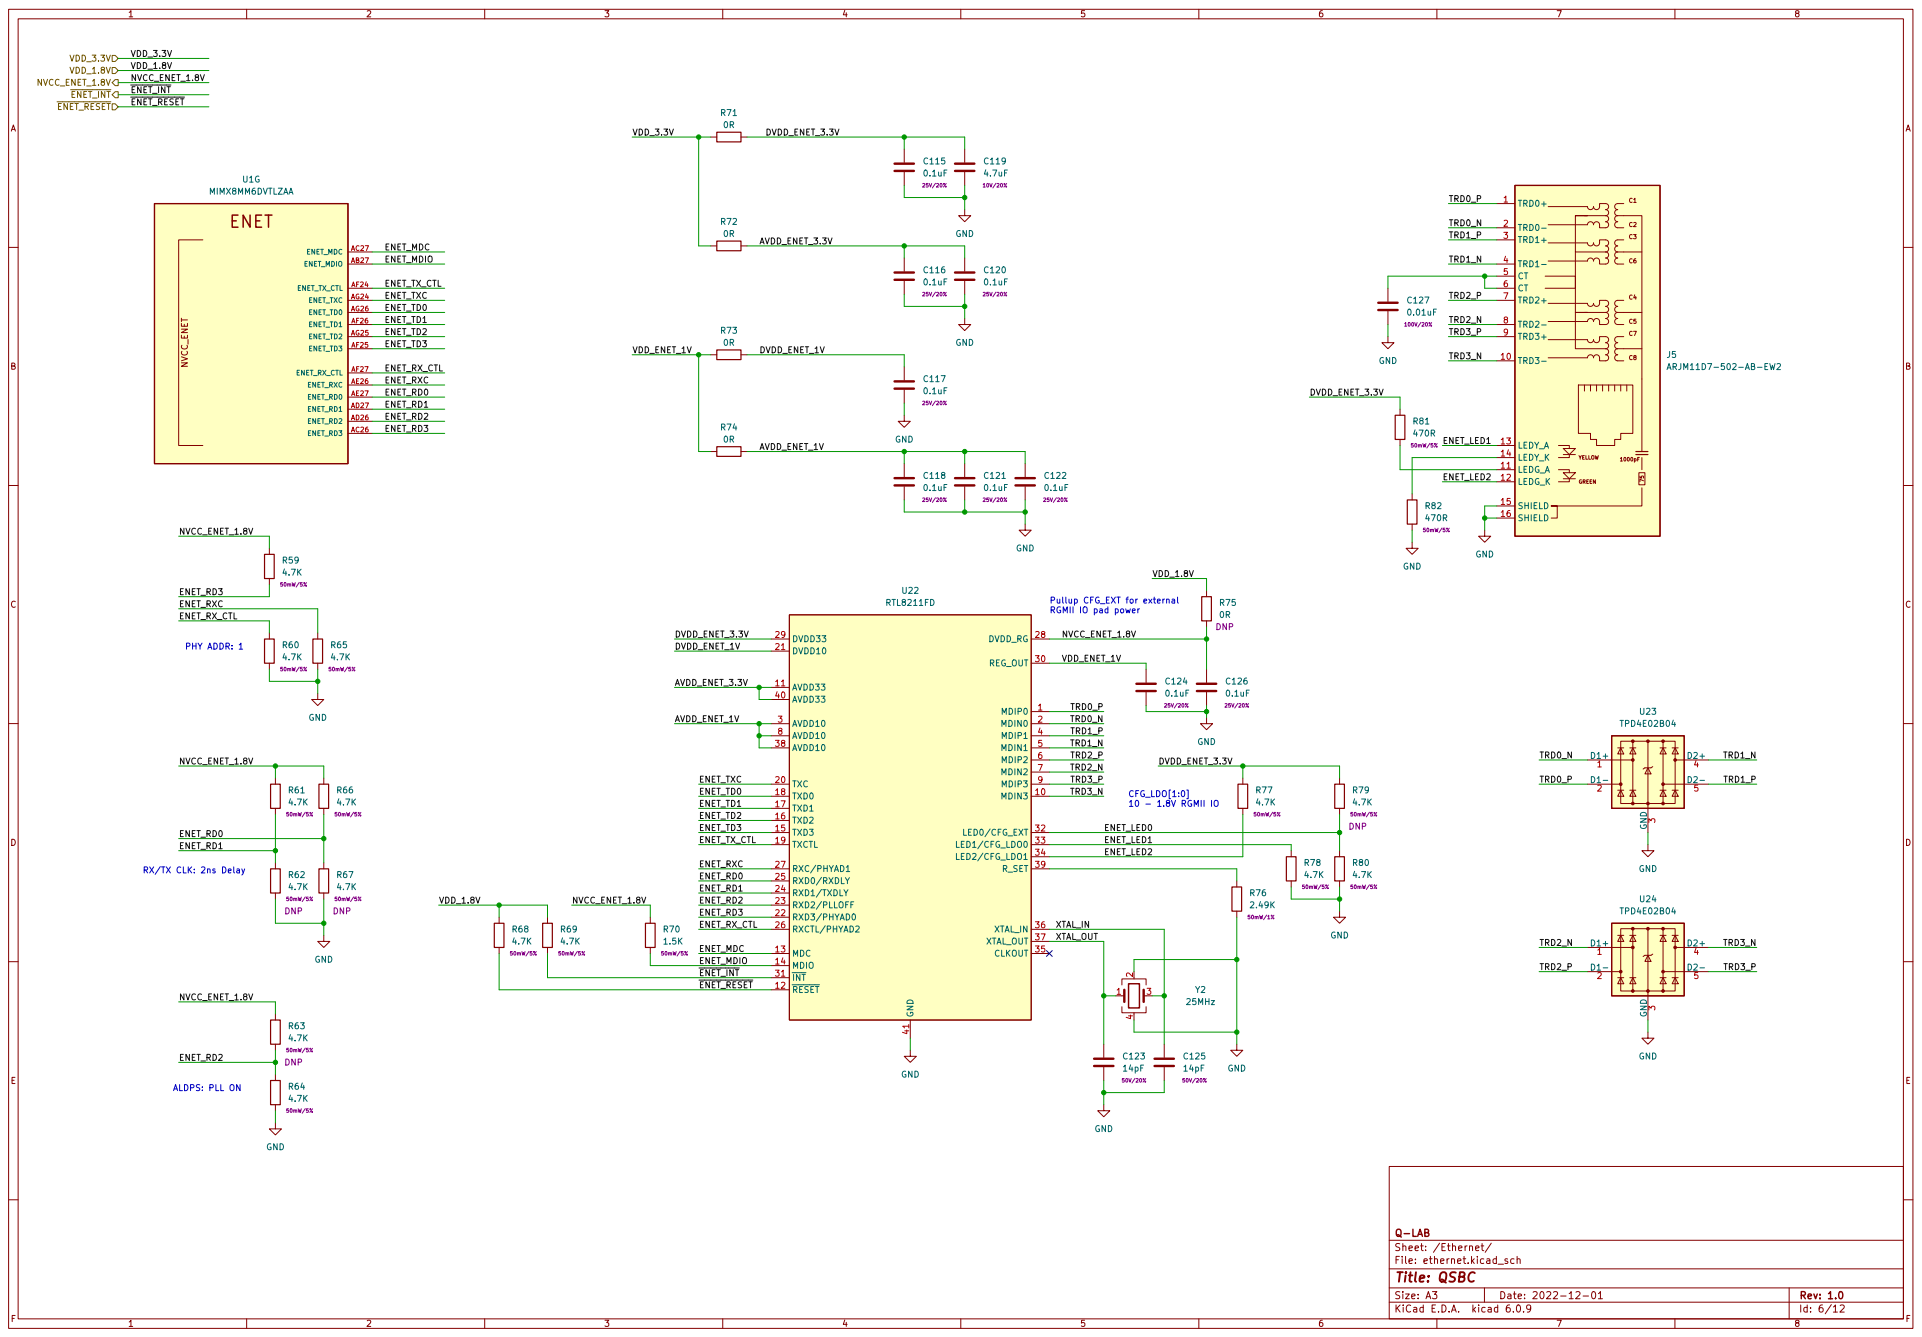
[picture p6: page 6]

File: ethernet.kicad_sch Sheet: /Ethernet/ Q-LAB

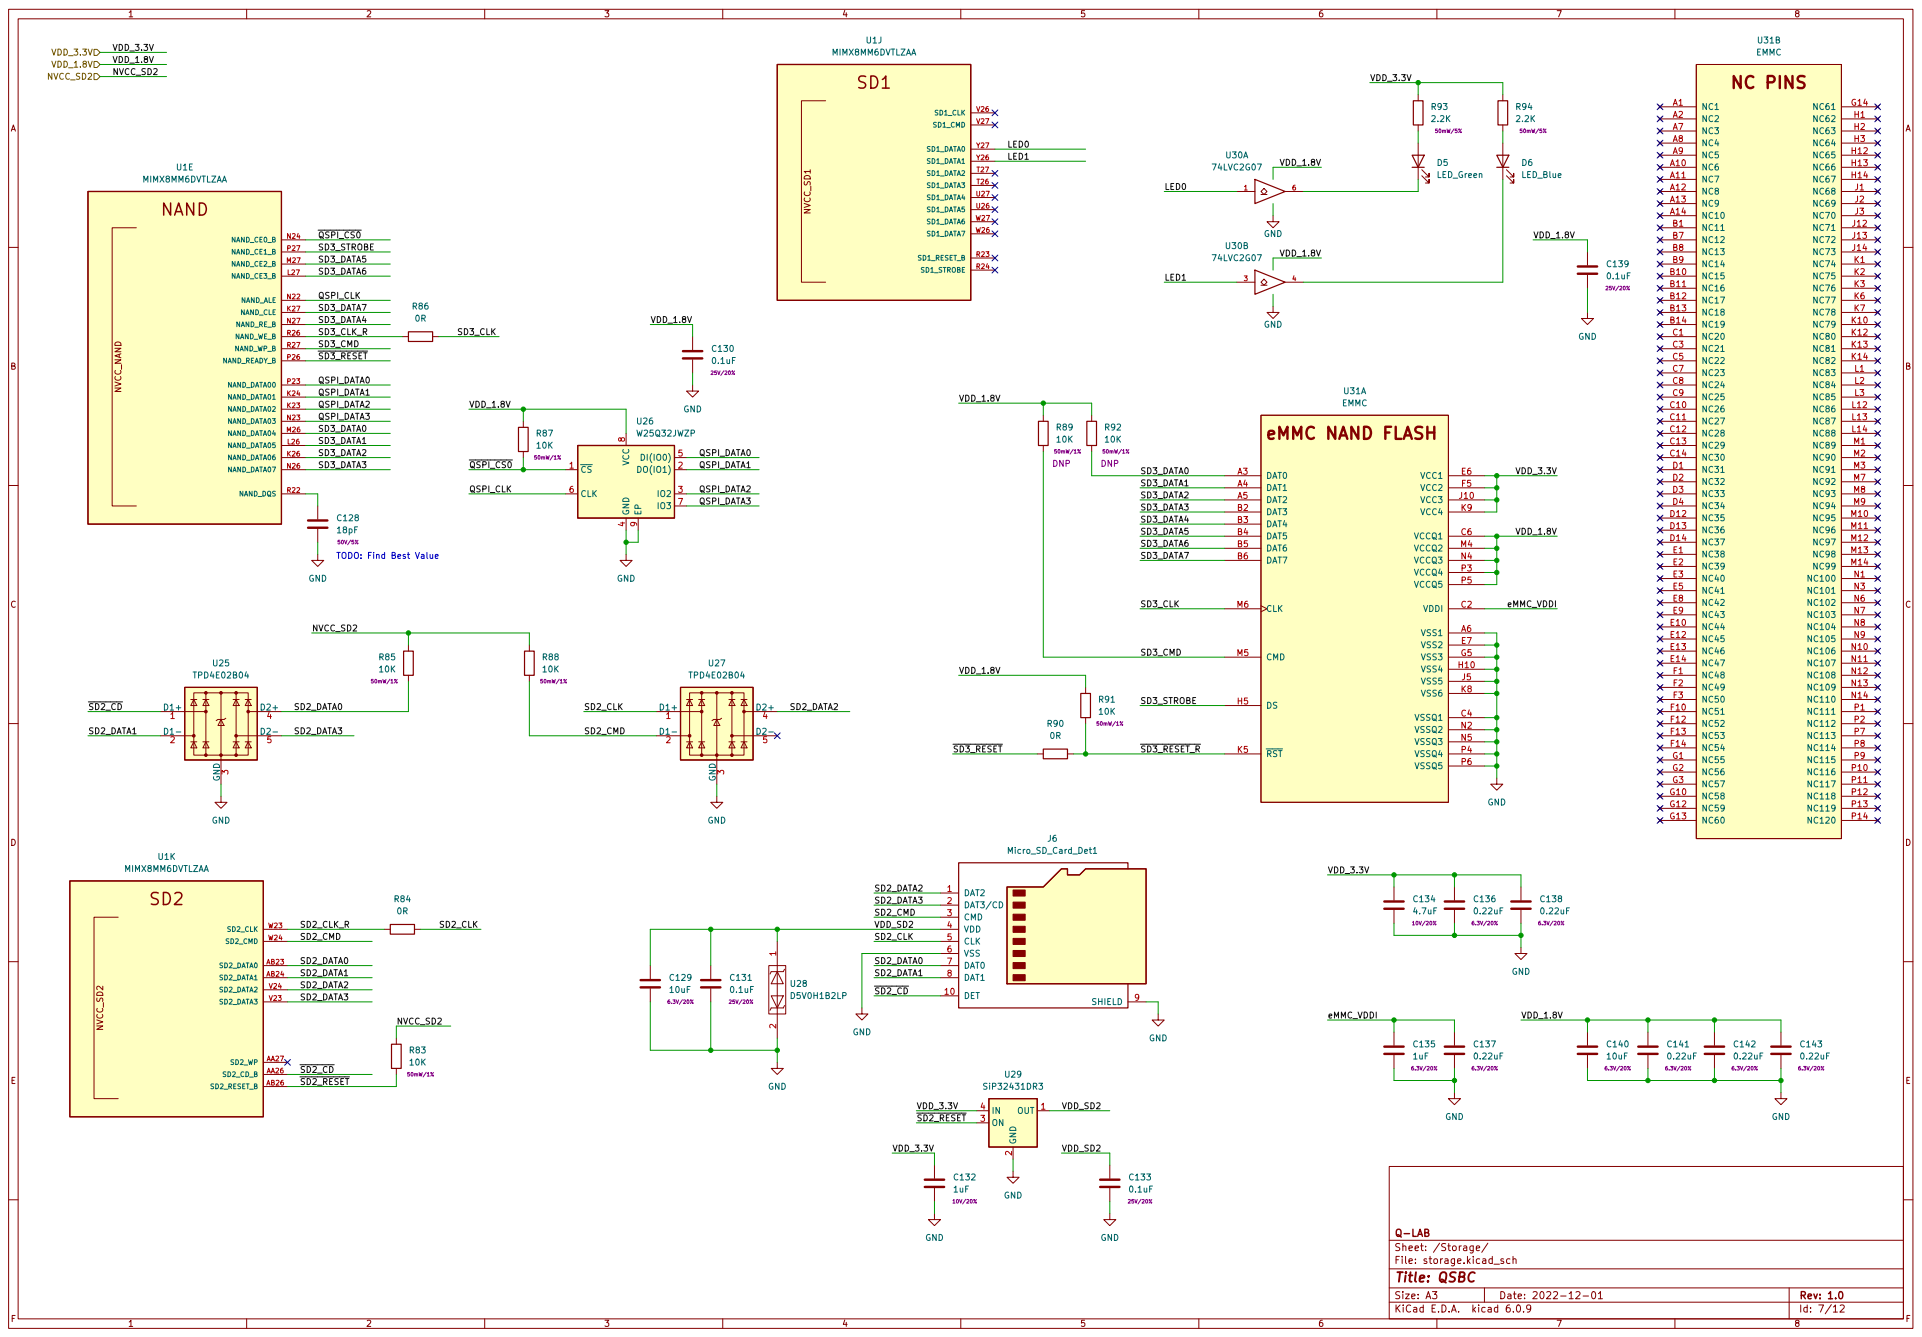
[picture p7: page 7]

File: storage.kicad_sch Sheet: /Storage/ Q-LAB

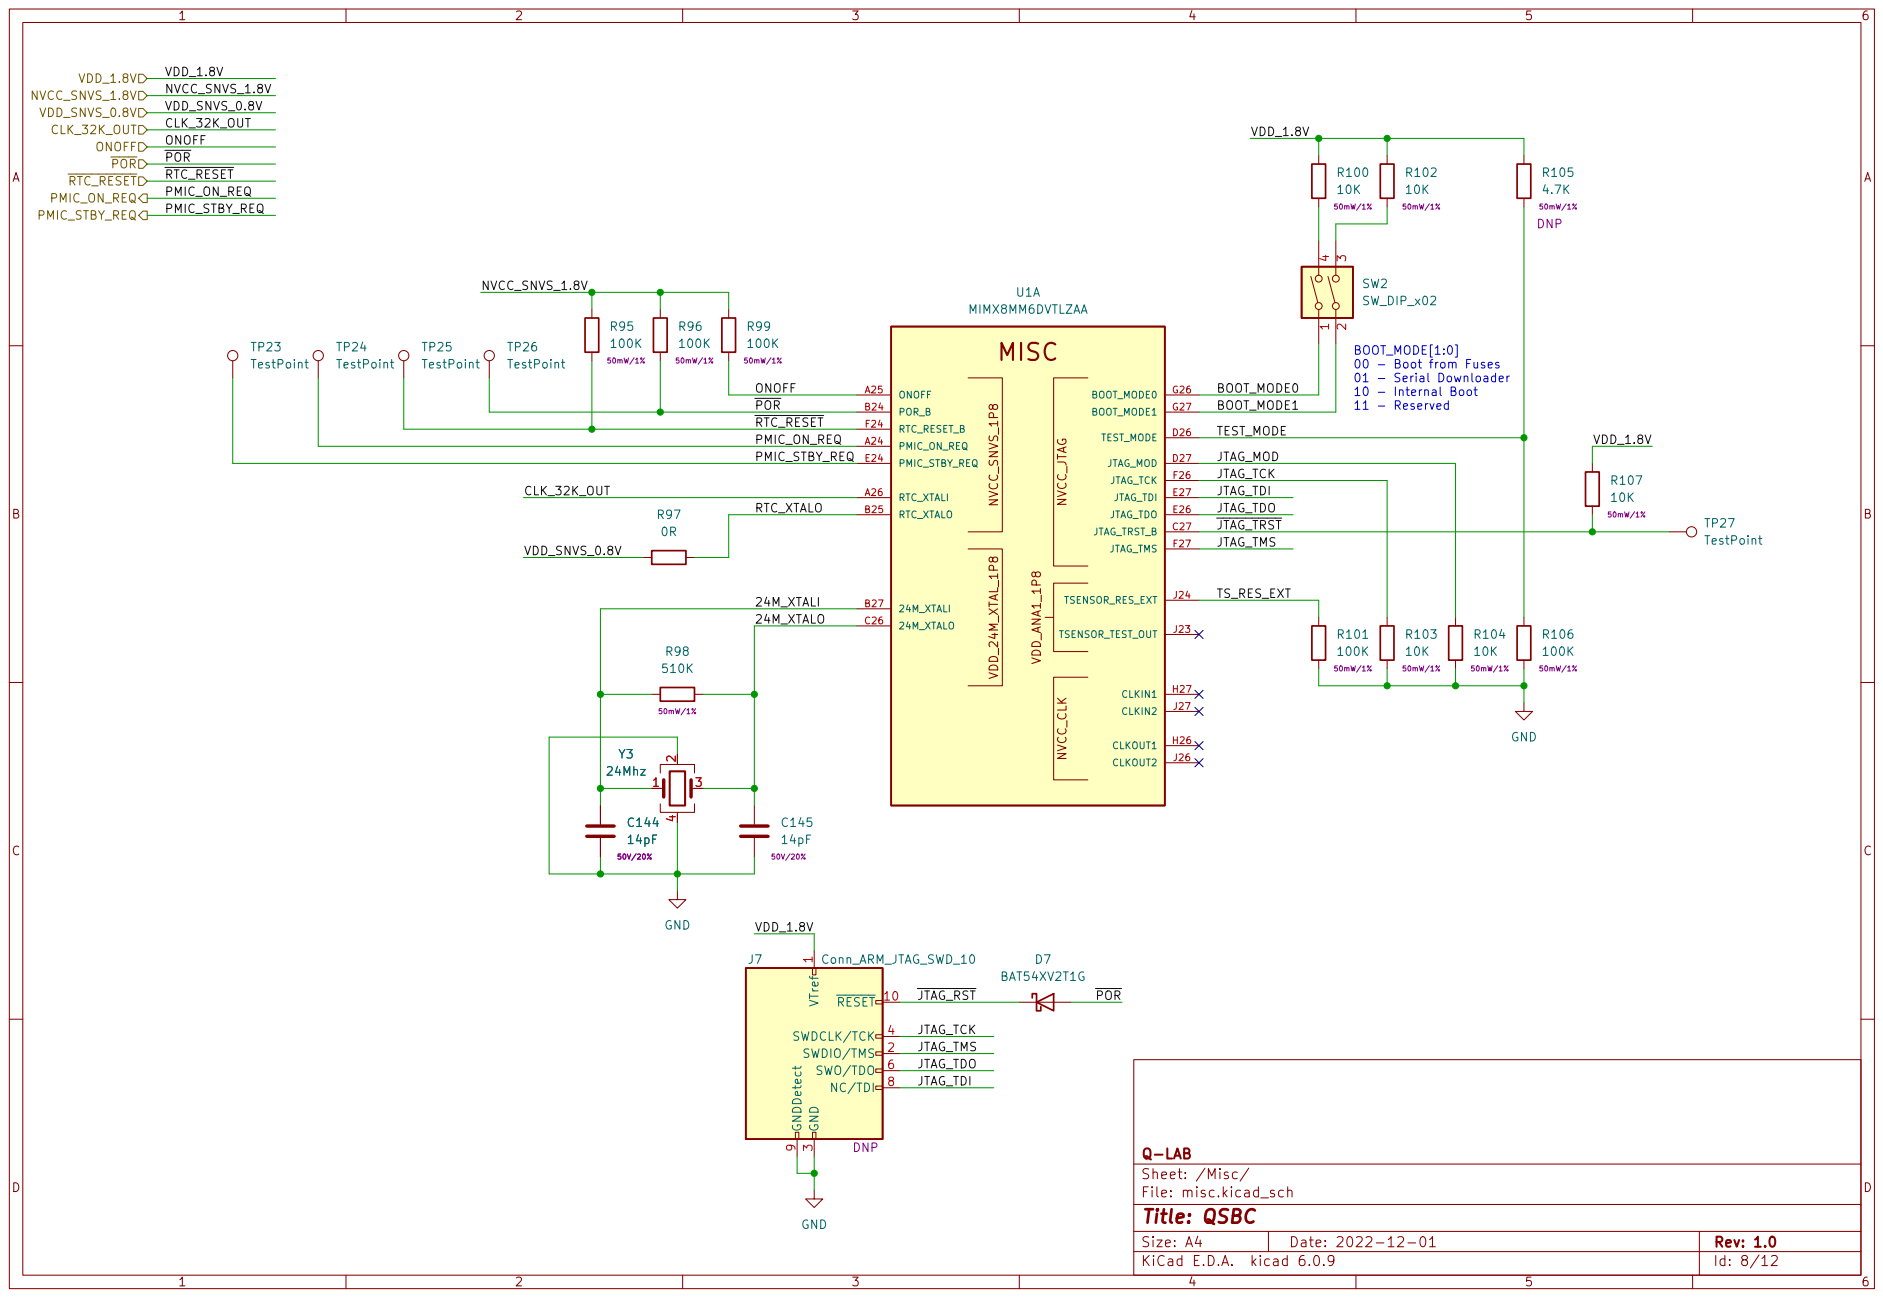
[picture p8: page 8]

BOOT_MODE[1:0] 00 - Boot from Fuses 01 - Serial Downloader 10 - Internal Boot 11 - Reserved C144

3 SWDCLK/TCK 4 SWO/TDO 6 NC/TDI 8 GNDDetect 9

File: misc.kicad_sch Sheet: /Misc/ Q-LAB

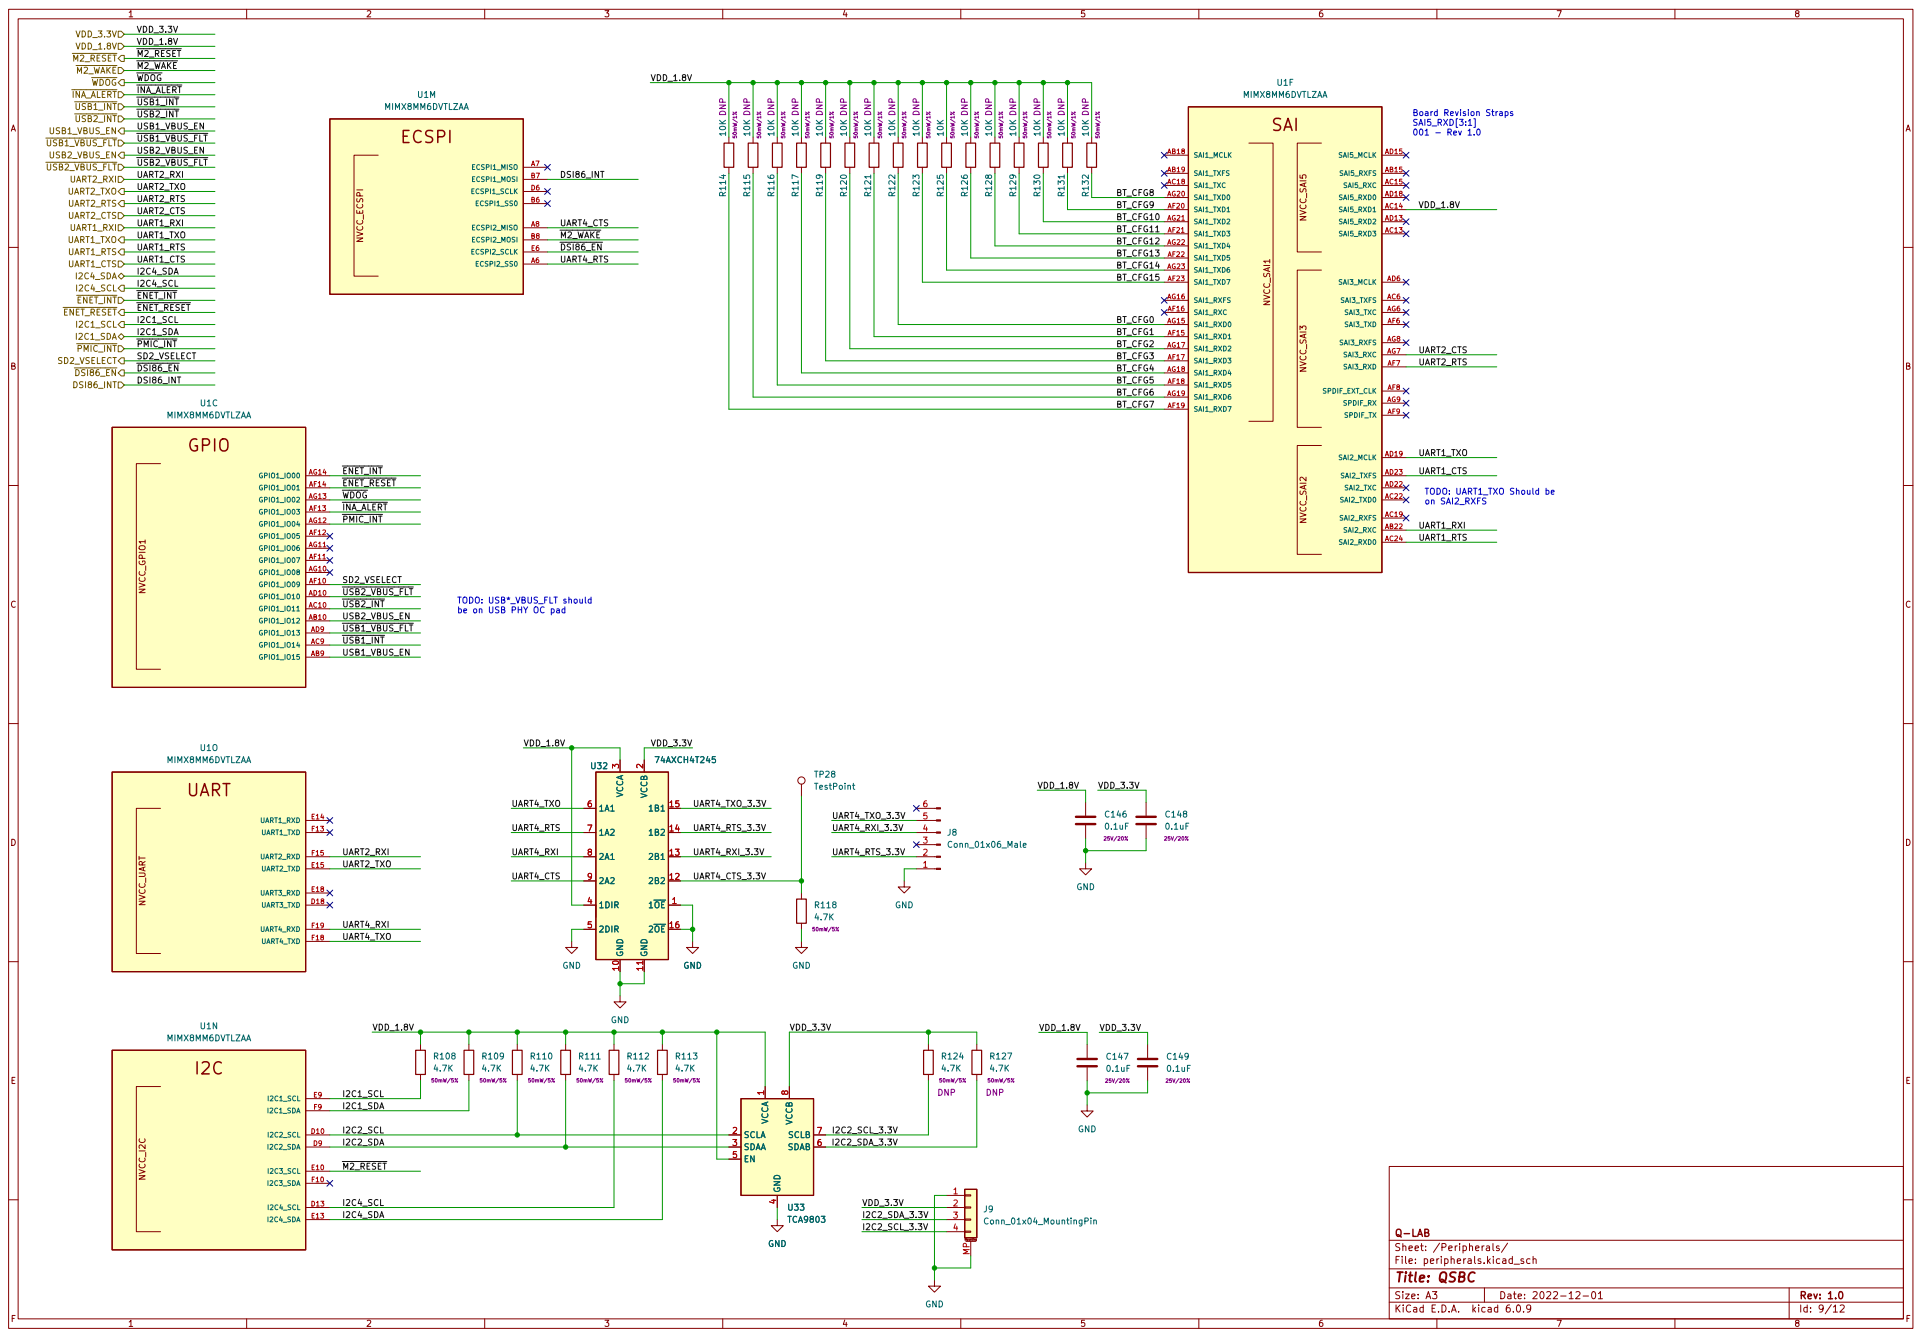
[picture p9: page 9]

Board Revision Straps SAI5_RXD[3:1] 001 - Rev 1.0 TODO: USB*_VBUS_FLT should

File: peripherals.kicad_sch Sheet: /Peripherals/ Q-LAB

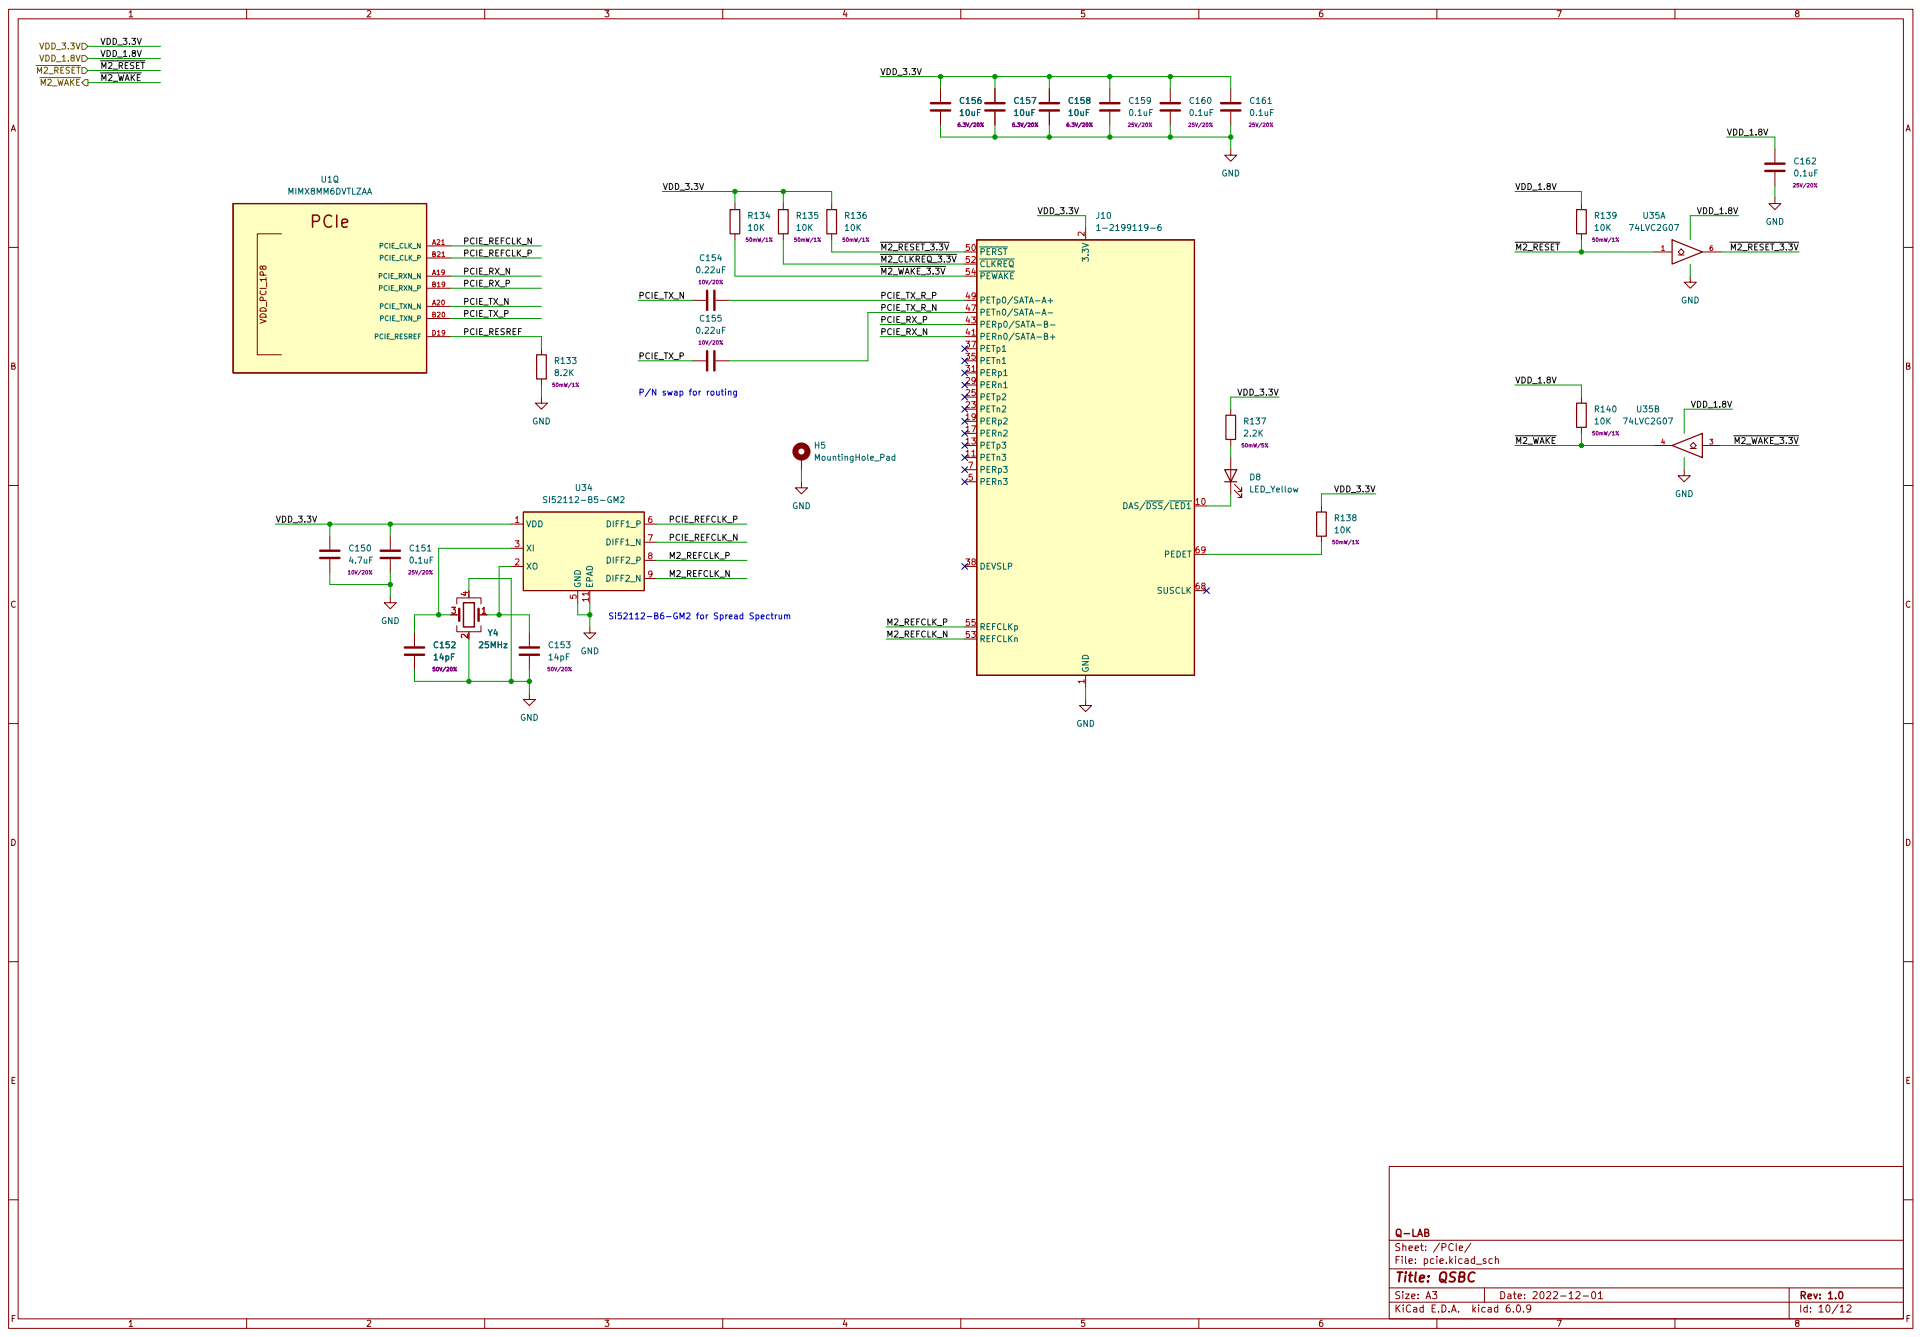
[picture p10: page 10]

2 PETn2 23 PETp2 25 PERn1 29 PERp1 31 PETn1 35 PETp1 37 DEVSLP 38 PERn0/SATA-B+ 41 PERp0/SATA-B- 43 PETn0/SATA-A- 47 PETp0/SATA-A+ 49 PERn3 5 ~{PERST} 50 ~{CLKREQ} 52 REFCLKn 53

P/N swap for routing Si52112-B6-GM2 for Spread Spectrum

File: pcie.kicad_sch Sheet: /PCIe/ Q-LAB

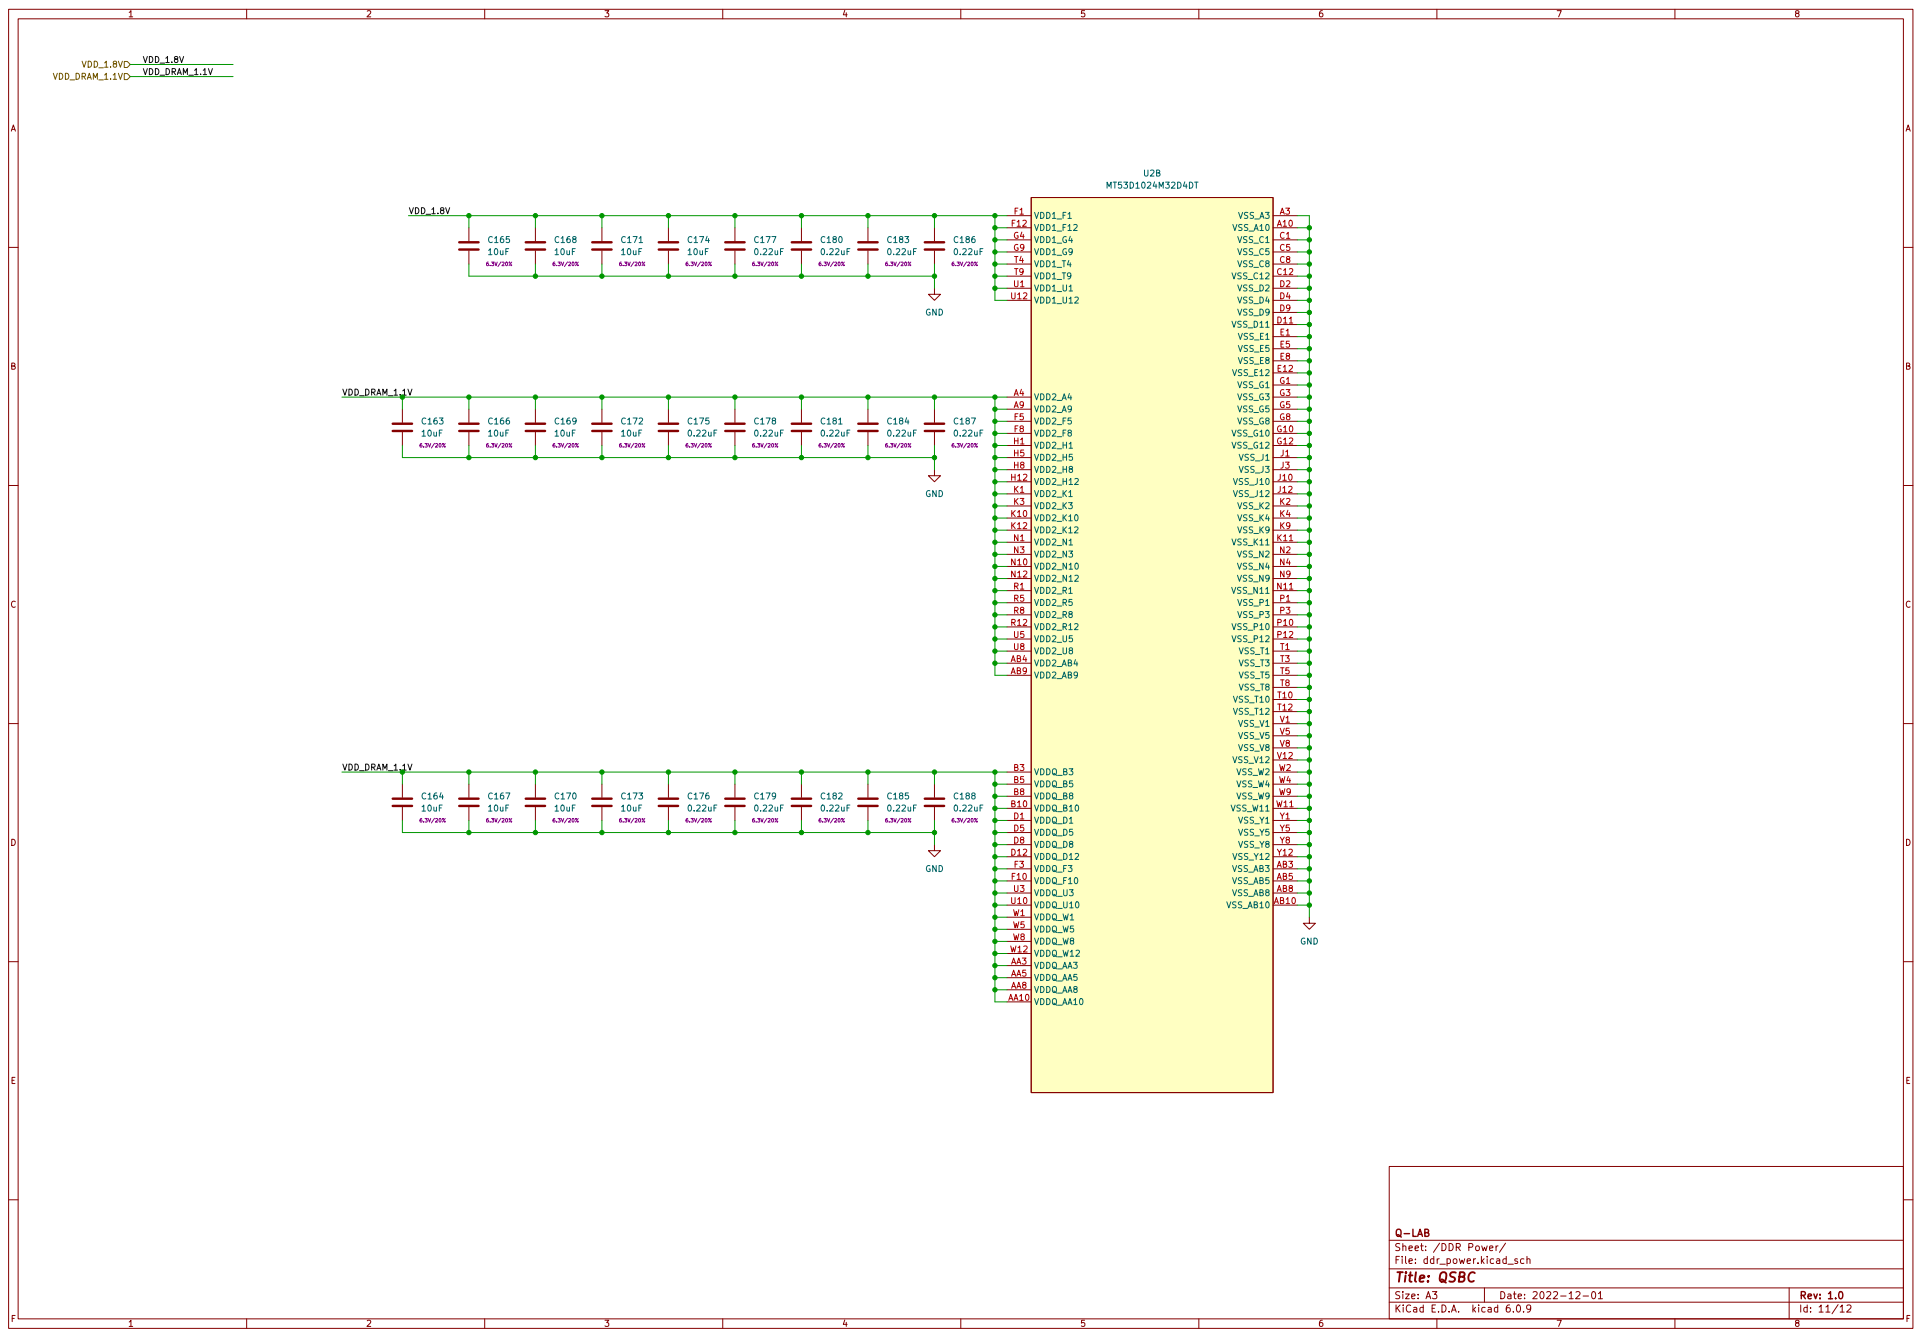
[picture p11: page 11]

File: ddr_power.kicad_sch Sheet: /DDR Power/ Q-LAB

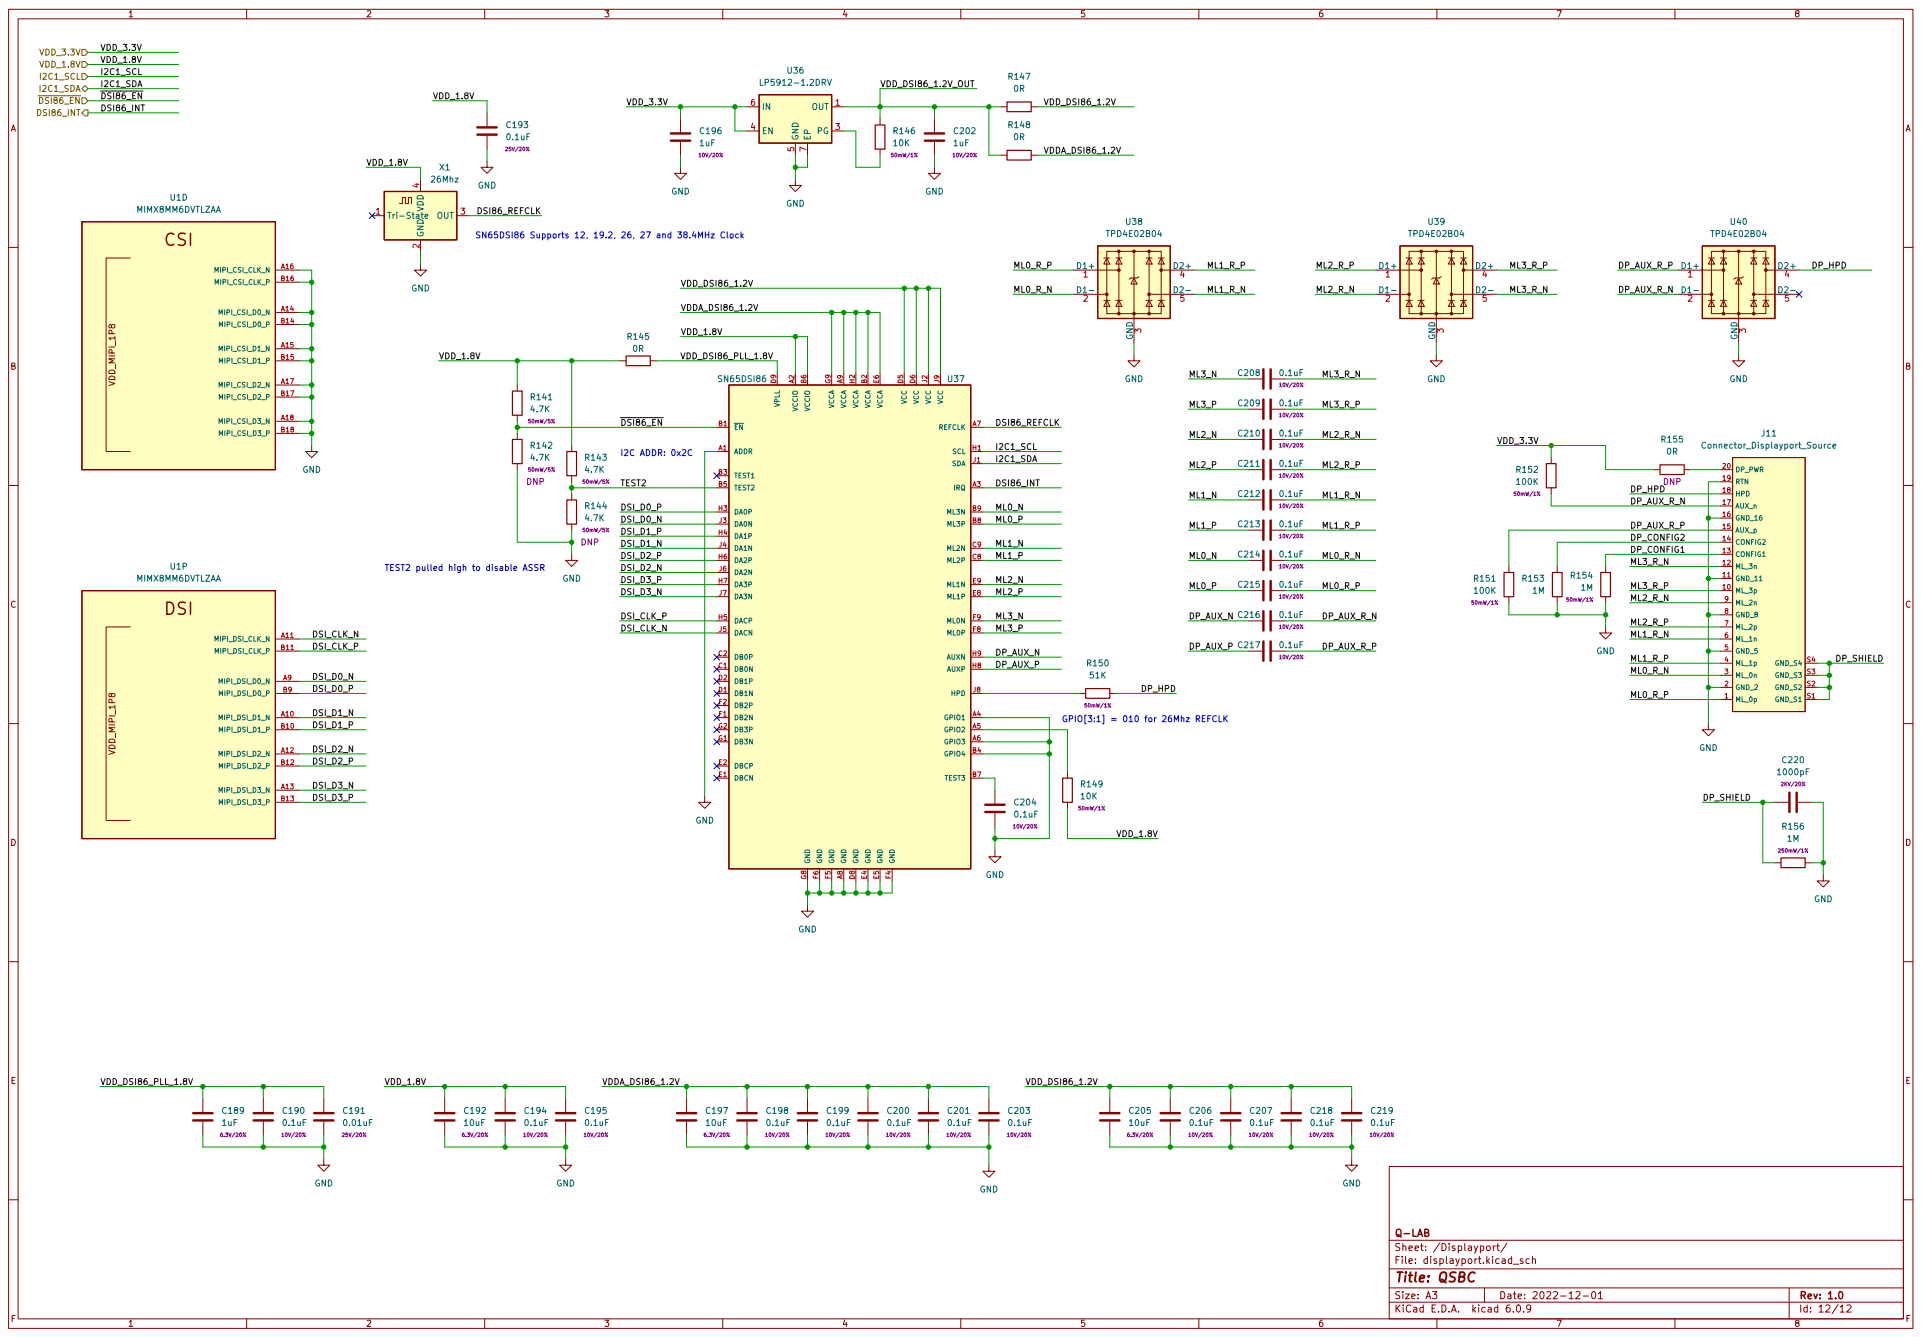
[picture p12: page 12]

TEST2 pulled high to disable ASSR

File: displayport.kicad_sch Sheet: /Displayport/ Q-LAB

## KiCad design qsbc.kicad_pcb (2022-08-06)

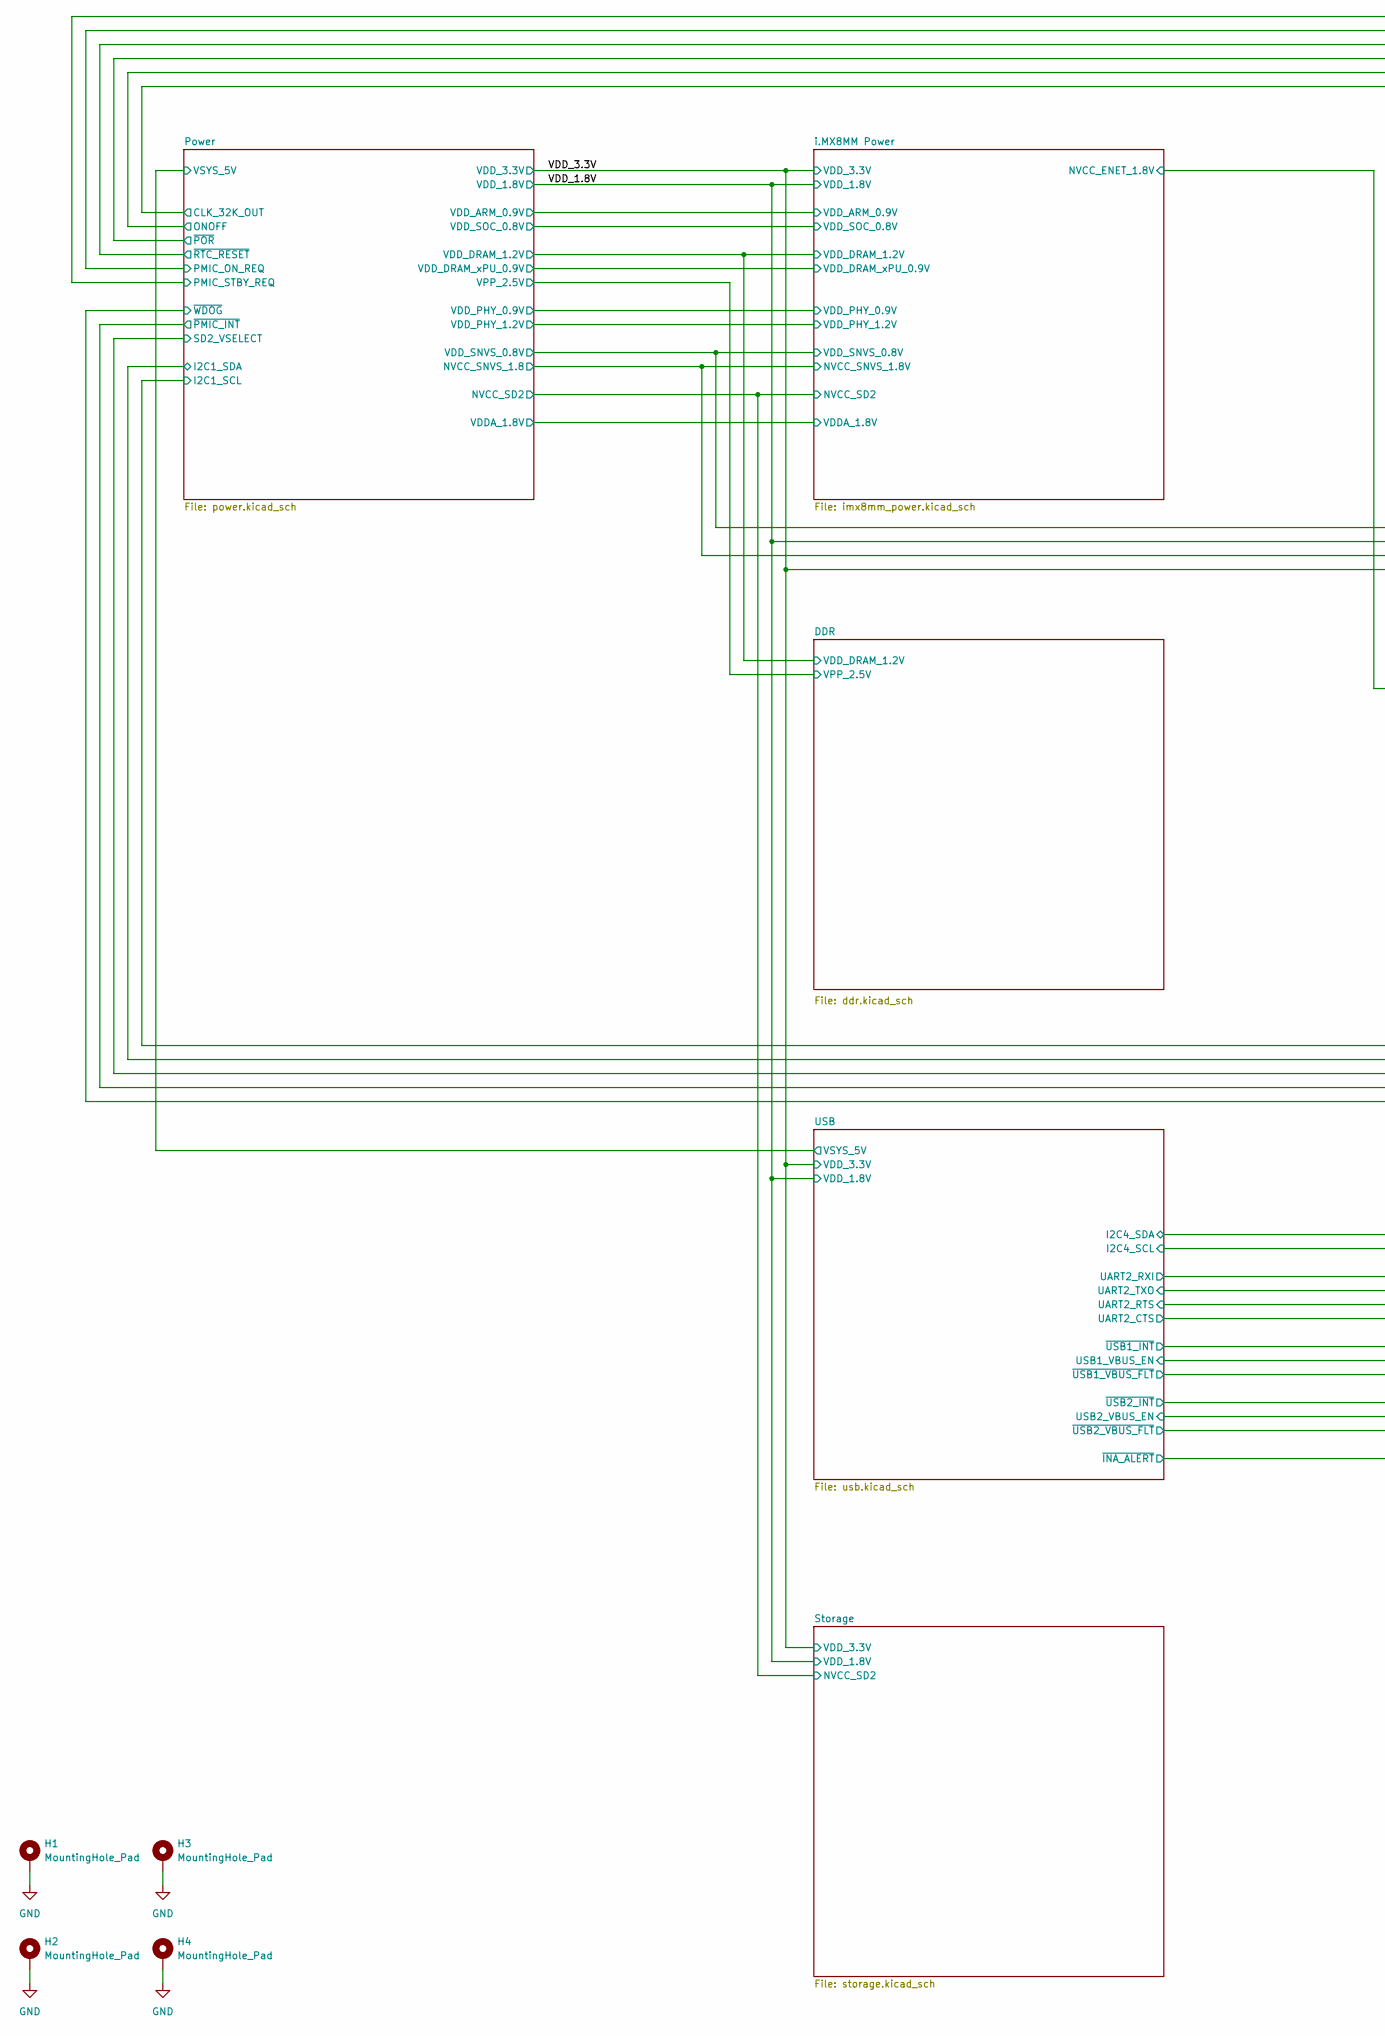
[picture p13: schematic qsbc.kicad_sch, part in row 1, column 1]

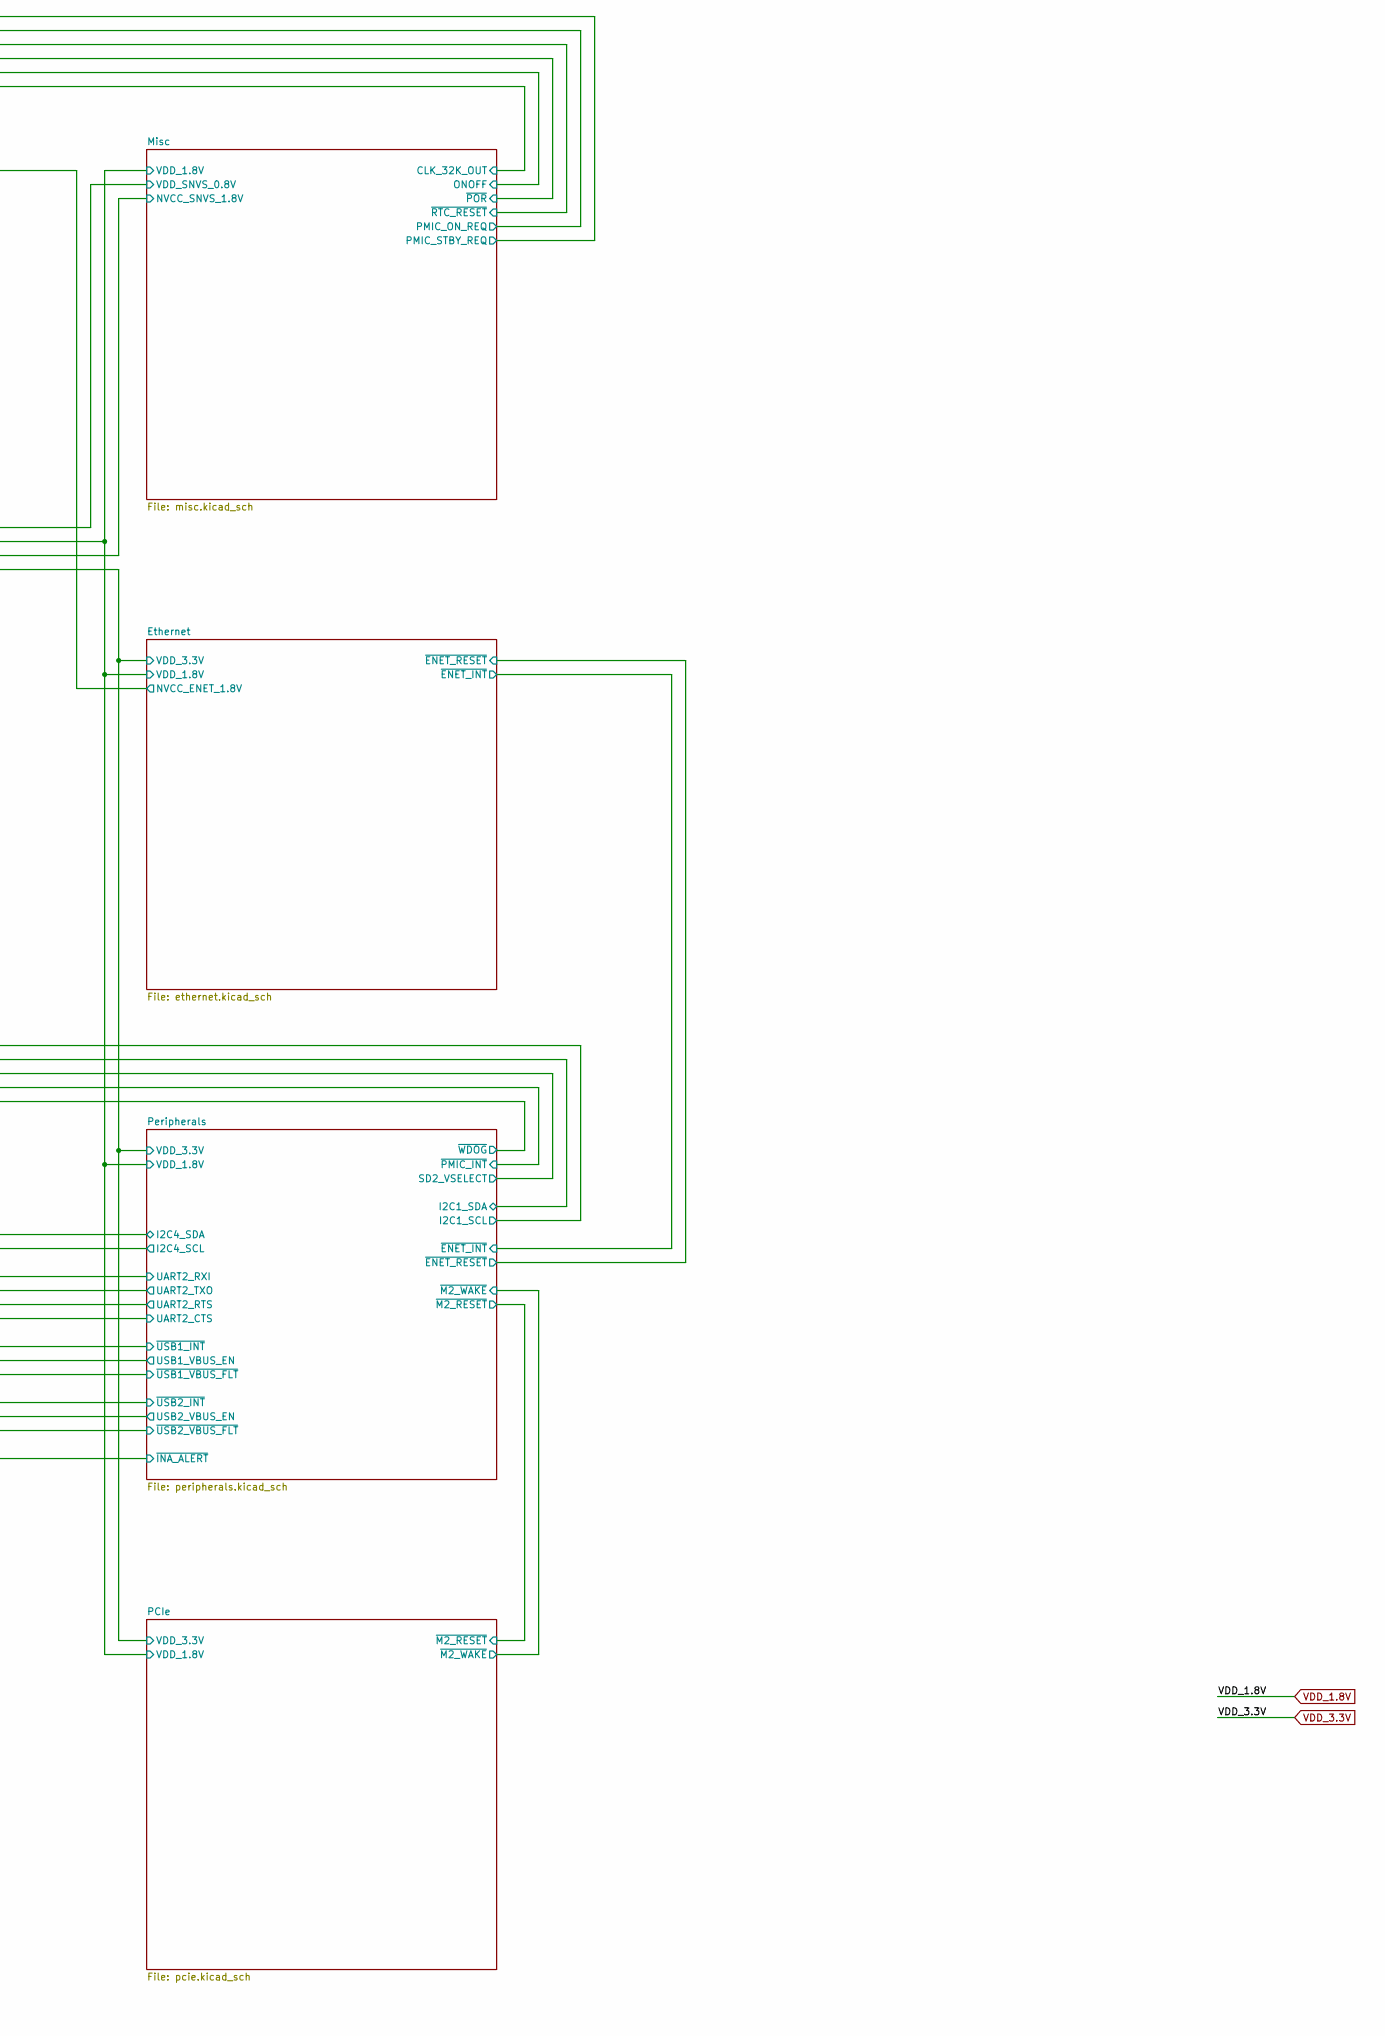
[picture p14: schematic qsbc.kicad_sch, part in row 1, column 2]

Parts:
H1, H2, H3, H4: MountingHole_Pad; MountingHole_3.2mm_M3_Pad_Via

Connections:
GND: H1.1, H2.1, H3.1, H4.1; also elsewhere on the board

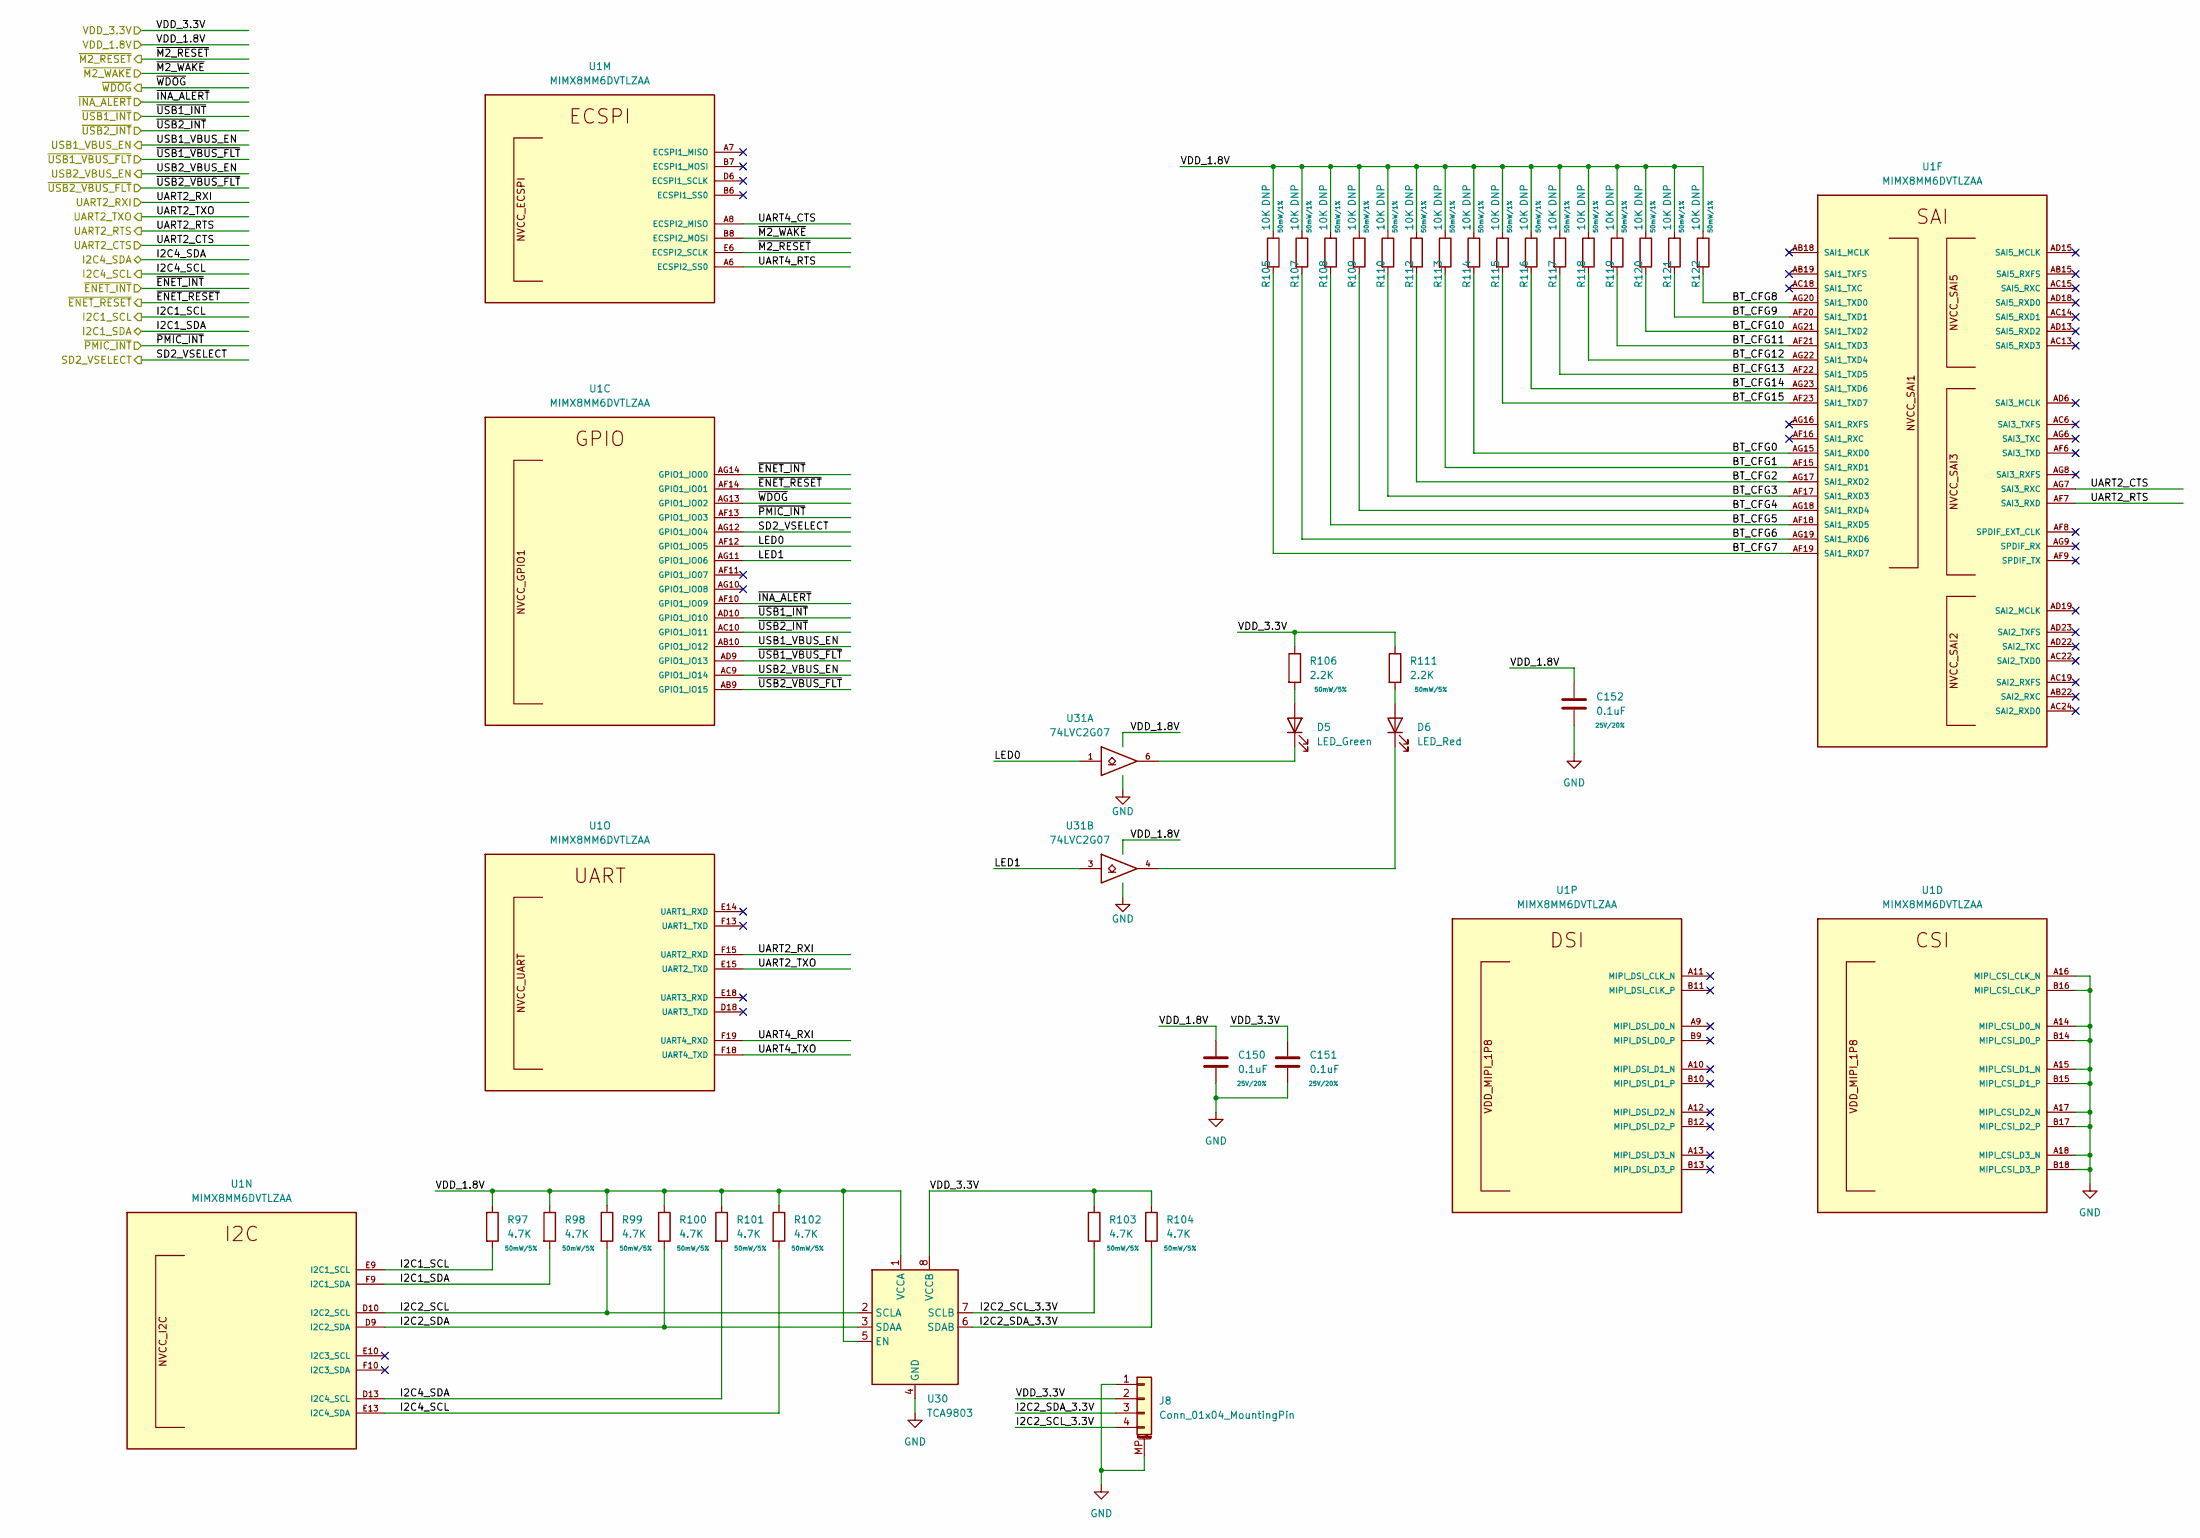
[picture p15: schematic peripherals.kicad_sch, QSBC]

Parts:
C150, C151, C152: 0.1uF; C_0402_1005Metric; Rating 25V/20%
D5: LED_Green; LED_0603_1608Metric
D6: LED_Red; LED_0603_1608Metric
J8: Conn_01x04_MountingPin; JST_SH_SM04B-SRSS-TB_1x04-1MP_P1.00mm_Horizontal
R97, R98, R99, R100, R101, R102, R103, R104: 4.7K; R_0402_1005Metric; Rating 50mW/5%
R105, R107, R108, R109, R110, R112, R113, R114, R115, R116, R117, R118, R119, R120, R121, R122: 10K; R_0402_1005Metric; Rating 50mW/1%; MPN RC0402JR-0710KL; DigiKey_PN 311-10KJRCT-ND
R106, R111: 2.2K; R_0402_1005Metric; Rating 50mW/5%
U1: MIMX8MM6DVTLZAA; SOT1967-1
U30: TCA9803; VSSOP-8_3.0x3.0mm_P0.65mm
U31: 74LVC2G07; SOT-886

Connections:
/Ethernet/~ENET_INT: U1.AG14 (GPIO1_IO00); also elsewhere on the board
/Ethernet/~ENET_RESET: U1.AF14 (GPIO1_IO01); also elsewhere on the board
/PCIe/~M2_RESET: U1.E6 (ECSPI2_SCLK); also elsewhere on the board
/PCIe/~M2_WAKE: U1.B8 (ECSPI2_MOSI); also elsewhere on the board
/Peripherals/BT_CFG0: R114.2, U1.AG15 (SAI1_RXD0)
/Peripherals/BT_CFG1: R113.2, U1.AF15 (SAI1_RXD1)
/Peripherals/BT_CFG2: R112.2, U1.AG17 (SAI1_RXD2)
/Peripherals/BT_CFG3: R110.2, U1.AF17 (SAI1_RXD3)
/Peripherals/BT_CFG4: R109.2, U1.AG18 (SAI1_RXD4)
/Peripherals/BT_CFG5: R108.2, U1.AF18 (SAI1_RXD5)
/Peripherals/BT_CFG6: R107.2, U1.AG19 (SAI1_RXD6)
/Peripherals/BT_CFG7: R105.2, U1.AF19 (SAI1_RXD7)
/Peripherals/BT_CFG8: R122.2, U1.AG20 (SAI1_TXD0)
/Peripherals/BT_CFG9: R121.2, U1.AF20 (SAI1_TXD1)
/Peripherals/BT_CFG10: R120.2, U1.AG21 (SAI1_TXD2)
/Peripherals/BT_CFG11: R119.2, U1.AF21 (SAI1_TXD3)
/Peripherals/BT_CFG12: R118.2, U1.AG22 (SAI1_TXD4)
/Peripherals/BT_CFG13: R117.2, U1.AF22 (SAI1_TXD5)
/Peripherals/BT_CFG14: R116.2, U1.AG23 (SAI1_TXD6)
/Peripherals/BT_CFG15: R115.2, U1.AF23 (SAI1_TXD7)
/Peripherals/I2C1_SCL: R97.2, U1.E9 (I2C1_SCL); also elsewhere on the board
/Peripherals/I2C1_SDA: R98.2, U1.F9 (I2C1_SDA); also elsewhere on the board
/Peripherals/I2C2_SCL: R99.2, U1.D10 (I2C2_SCL), U30.2 (SCLA)
/Peripherals/I2C2_SCL_3.3V: J8.4, R103.2, U30.7 (SCLB)
/Peripherals/I2C2_SDA: R100.2, U1.D9 (I2C2_SDA), U30.3 (SDAA)
/Peripherals/I2C2_SDA_3.3V: J8.3, R104.2, U30.6 (SDAB)
/Peripherals/I2C4_SCL: R102.2, U1.E13 (I2C4_SDA); also elsewhere on the board
/Peripherals/I2C4_SDA: R101.2, U1.D13 (I2C4_SCL); also elsewhere on the board
/Peripherals/LED0: U1.AF12 (GPIO1_IO05), U31.1
/Peripherals/LED1: U1.AG11 (GPIO1_IO06), U31.3
/Peripherals/SD2_VSELECT: U1.AG12 (GPIO1_IO04); also elsewhere on the board
/Peripherals/UART2_CTS: U1.AG7 (SAI3_RXC); also elsewhere on the board
/Peripherals/UART2_RTS: U1.AF7 (SAI3_RXD); also elsewhere on the board
/Peripherals/UART2_RXI: U1.F15 (UART2_RXD); also elsewhere on the board
/Peripherals/UART2_TXO: U1.E15 (UART2_TXD); also elsewhere on the board
/Peripherals/UART4_CTS: U1.A8 (ECSPI2_MISO)
/Peripherals/UART4_RTS: U1.A6 (ECSPI2_SS0)
/Peripherals/UART4_RXI: U1.F19 (UART4_RXD)
/Peripherals/UART4_TXO: U1.F18 (UART4_TXD)
/Peripherals/USB1_VBUS_EN: U1.AB10 (GPIO1_IO12); also elsewhere on the board
/Peripherals/USB2_VBUS_EN: U1.AC9 (GPIO1_IO14); also elsewhere on the board
/Peripherals/~INA_ALERT: U1.AF10 (GPIO1_IO09); also elsewhere on the board
/Peripherals/~PMIC_INT: U1.AF13 (GPIO1_IO03); also elsewhere on the board
/Peripherals/~USB1_INT: U1.AD10 (GPIO1_IO10); also elsewhere on the board
/Peripherals/~USB1_VBUS_FLT: U1.AD9 (GPIO1_IO13); also elsewhere on the board
/Peripherals/~USB2_INT: U1.AC10 (GPIO1_IO11); also elsewhere on the board
/Peripherals/~USB2_VBUS_FLT: U1.AB9 (GPIO1_IO15); also elsewhere on the board
/Peripherals/~WDOG: U1.AG13 (GPIO1_IO02)
GND: C150.2, C151.2, C152.2, J8.1, J8.MP (MountPin), U1.A14 (MIPI_CSI_D0_N), U1.A15 (MIPI_CSI_D1_N), U1.A16 (MIPI_CSI_CLK_N), U1.A17 (MIPI_CSI_D2_N), U1.A18 (MIPI_CSI_D3_N), U1.B14 (MIPI_CSI_D0_P), U1.B15 (MIPI_CSI_D1_P), U1.B16 (MIPI_CSI_CLK_P), U1.B17 (MIPI_CSI_D2_P), U1.B18 (MIPI_CSI_D3_P), U30.4 (GND), U31.2 (GND); also elsewhere on the board
unnamed: D5.1 (K), U31.6
unnamed: D5.2 (A), R106.2
unnamed: D6.1 (K), U31.4
unnamed: D6.2 (A), R111.2
VDD_1.8V: C150.1, C152.1, R97.1, R98.1, R99.1, R100.1, R101.1, R102.1, R105.1, R107.1, R108.1, R109.1, R110.1, R112.1, R113.1, R114.1, R115.1, R116.1, R117.1, R118.1, R119.1, R120.1, R121.1, R122.1, U30.1 (VCCA), U30.5 (EN), U31.5 (VCC); also elsewhere on the board
VDD_3.3V: C151.1, J8.2, R103.1, R104.1, R106.1, R111.1, U30.8 (VCCB); also elsewhere on the board

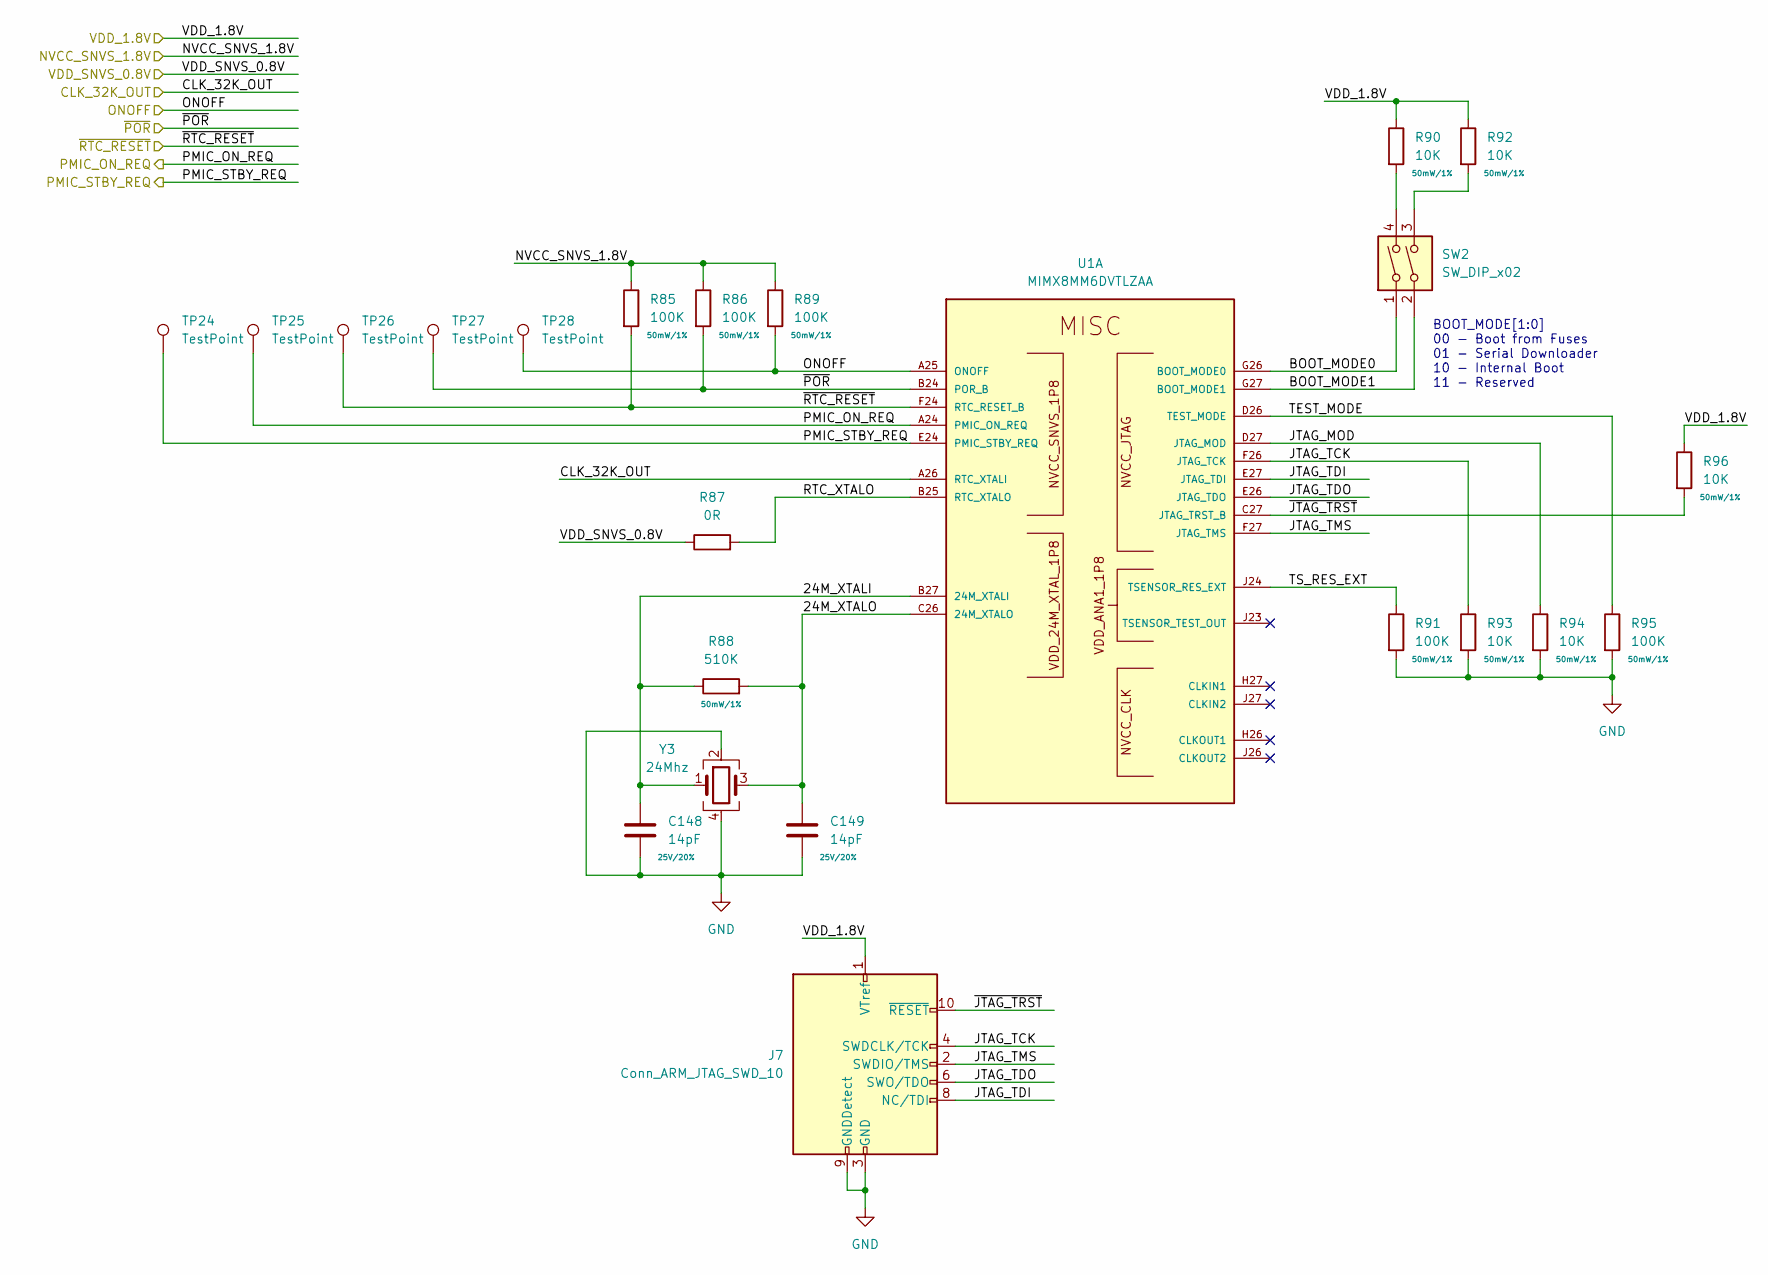
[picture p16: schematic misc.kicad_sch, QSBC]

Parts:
C148, C149: 14pF; C_0402_1005Metric; Rating 25V/20%
J7: Conn_ARM_JTAG_SWD_10; PinHeader_2x05_P1.27mm_Vertical
R85, R86, R89, R91, R95: 100K; R_0402_1005Metric; Rating 50mW/1%
R87: 0R; R_0402_1005Metric
R88: 510K; R_0402_1005Metric; Rating 50mW/1%
R90, R92, R93, R94, R96: 10K; R_0402_1005Metric; Rating 50mW/1%
SW2: SW_DIP_x02; DHN-02
TP24, TP25, TP26, TP27, TP28: TestPoint; TestPoint_Pad_D1.0mm
U1: MIMX8MM6DVTLZAA; SOT1967-1
Y3: 24Mhz; Crystal_SMD_3225-4Pin_3.2x2.5mm; MPN ECS-240-10-33B-7KM-TR

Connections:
/Misc/24M_XTALI: C148.1, R88.1, U1.B27 (24M_XTALI), Y3.1
/Misc/24M_XTALO: C149.1, R88.2, U1.C26 (24M_XTALO), Y3.3
/Misc/BOOT_MODE0: SW2.1, U1.G26 (BOOT_MODE0)
/Misc/BOOT_MODE1: SW2.2, U1.G27 (BOOT_MODE1)
/Misc/CLK_32K_OUT: U1.A26 (RTC_XTALI); also elsewhere on the board
/Misc/JTAG_MOD: R94.1, U1.D27 (JTAG_MOD)
/Misc/JTAG_TCK: J7.4 (SWDCLK/TCK), R93.1, U1.F26 (JTAG_TCK)
/Misc/JTAG_TDI: J7.8 (NC/TDI), U1.E27 (JTAG_TDI)
/Misc/JTAG_TDO: J7.6 (SWO/TDO), U1.E26 (JTAG_TDO)
/Misc/JTAG_TMS: J7.2 (SWDIO/TMS), U1.F27 (JTAG_TMS)
/Misc/NVCC_SNVS_1.8V: R85.1, R86.1, R89.1; also elsewhere on the board
/Misc/ONOFF: R89.2, TP28.1, U1.A25 (ONOFF); also elsewhere on the board
/Misc/PMIC_ON_REQ: TP25.1, U1.A24 (PMIC_ON_REQ); also elsewhere on the board
/Misc/PMIC_STBY_REQ: TP24.1, U1.E24 (PMIC_STBY_REQ); also elsewhere on the board
/Misc/RTC_XTALO: R87.2, U1.B25 (RTC_XTALO)
/Misc/TEST_MODE: R95.1, U1.D26 (TEST_MODE)
/Misc/TS_RES_EXT: R91.1, U1.J24 (TSENSOR_RES_EXT)
/Misc/VDD_SNVS_0.8V: R87.1; also elsewhere on the board
/Misc/~JTAG_TRST: J7.10 (~RESET), R96.2, U1.C27 (JTAG_TRST_B)
/Misc/~POR: R86.2, TP27.1, U1.B24 (POR_B); also elsewhere on the board
/Misc/~RTC_RESET: R85.2, TP26.1, U1.F24 (RTC_RESET_B); also elsewhere on the board
GND: C148.2, C149.2, J7.3 (GND), J7.5 (GND), J7.9 (GNDDetect), R91.2, R93.2, R94.2, R95.2, Y3.2, Y3.4; also elsewhere on the board
unnamed: R90.2, SW2.4
unnamed: R92.2, SW2.3
VDD_1.8V: J7.1 (VTref), R90.1, R92.1, R96.1; also elsewhere on the board

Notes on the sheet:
BOOT_MODE[1:0] 00 - Boot from Fuses 01 - Serial Downloader 10 - Internal Boot 11 - Reserved

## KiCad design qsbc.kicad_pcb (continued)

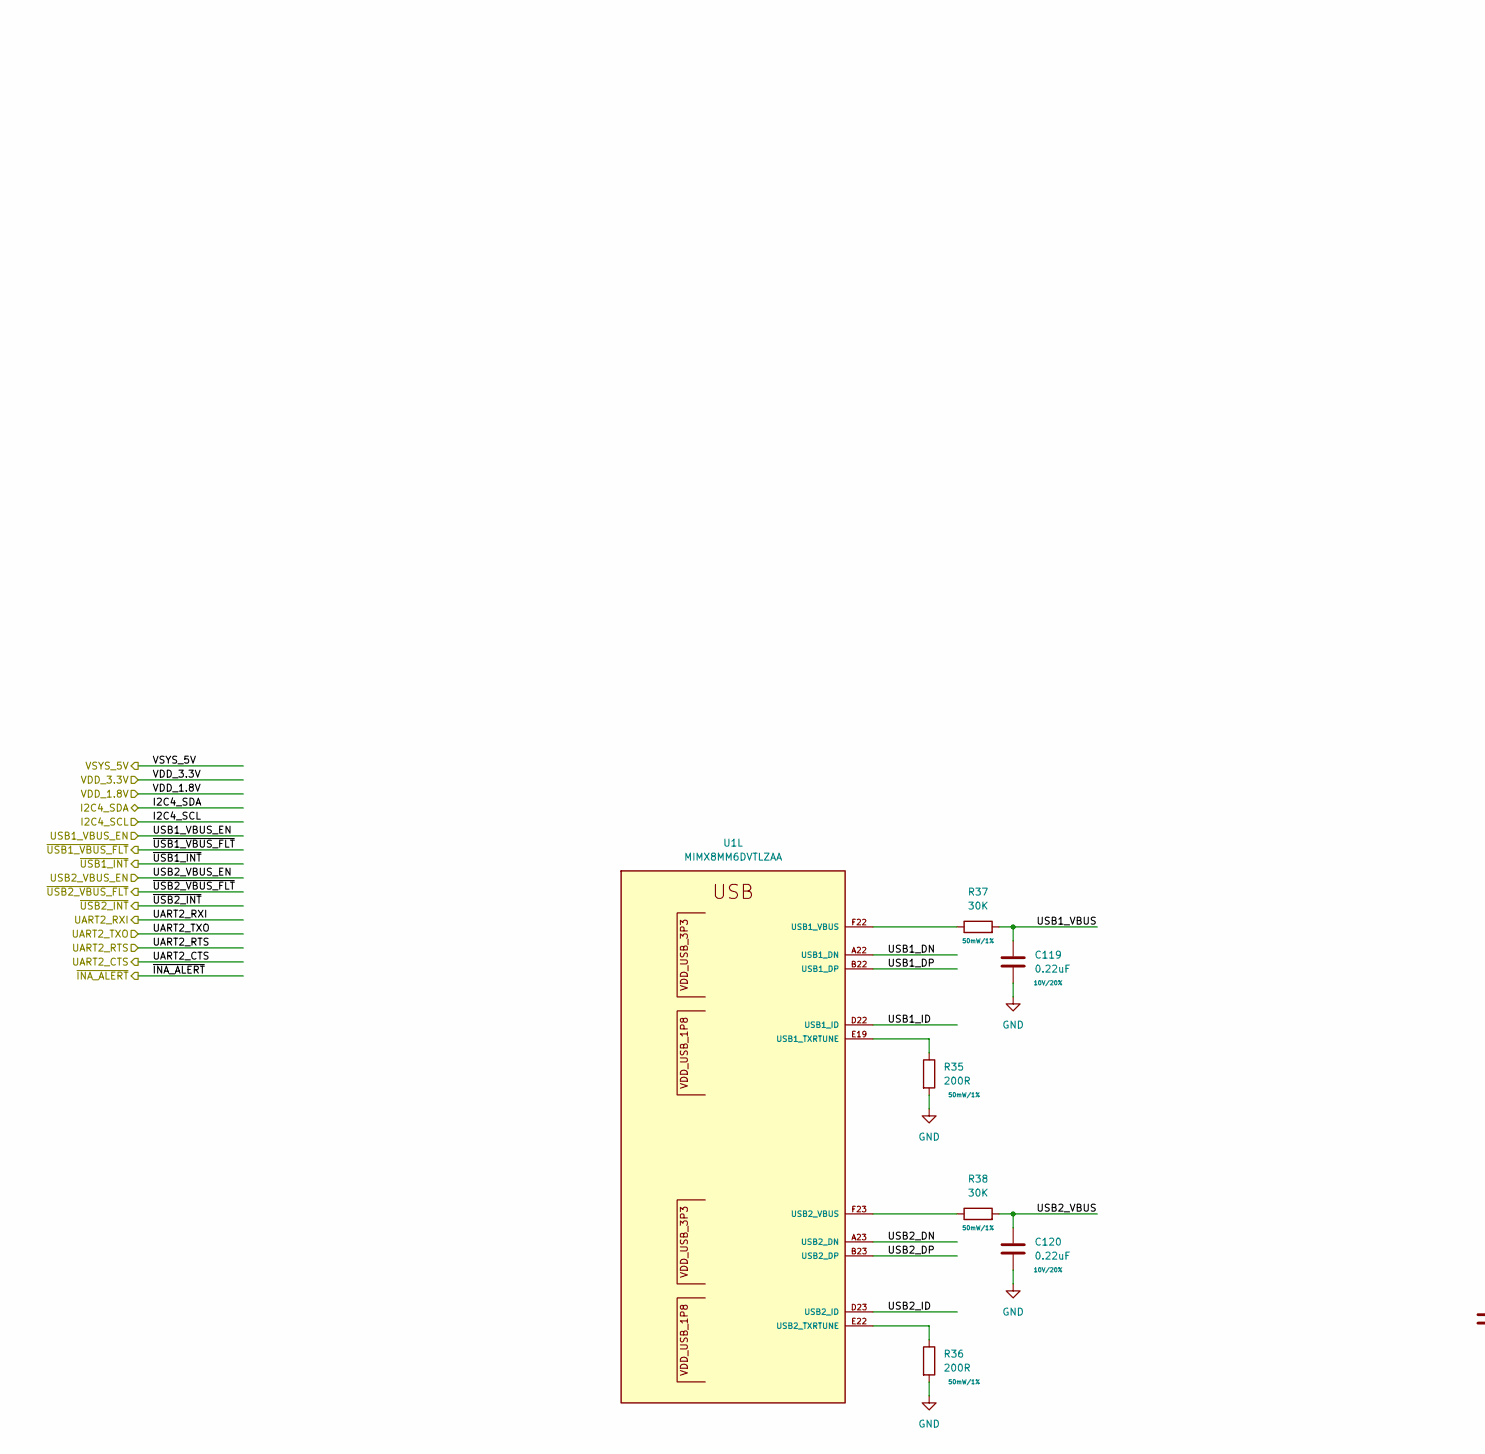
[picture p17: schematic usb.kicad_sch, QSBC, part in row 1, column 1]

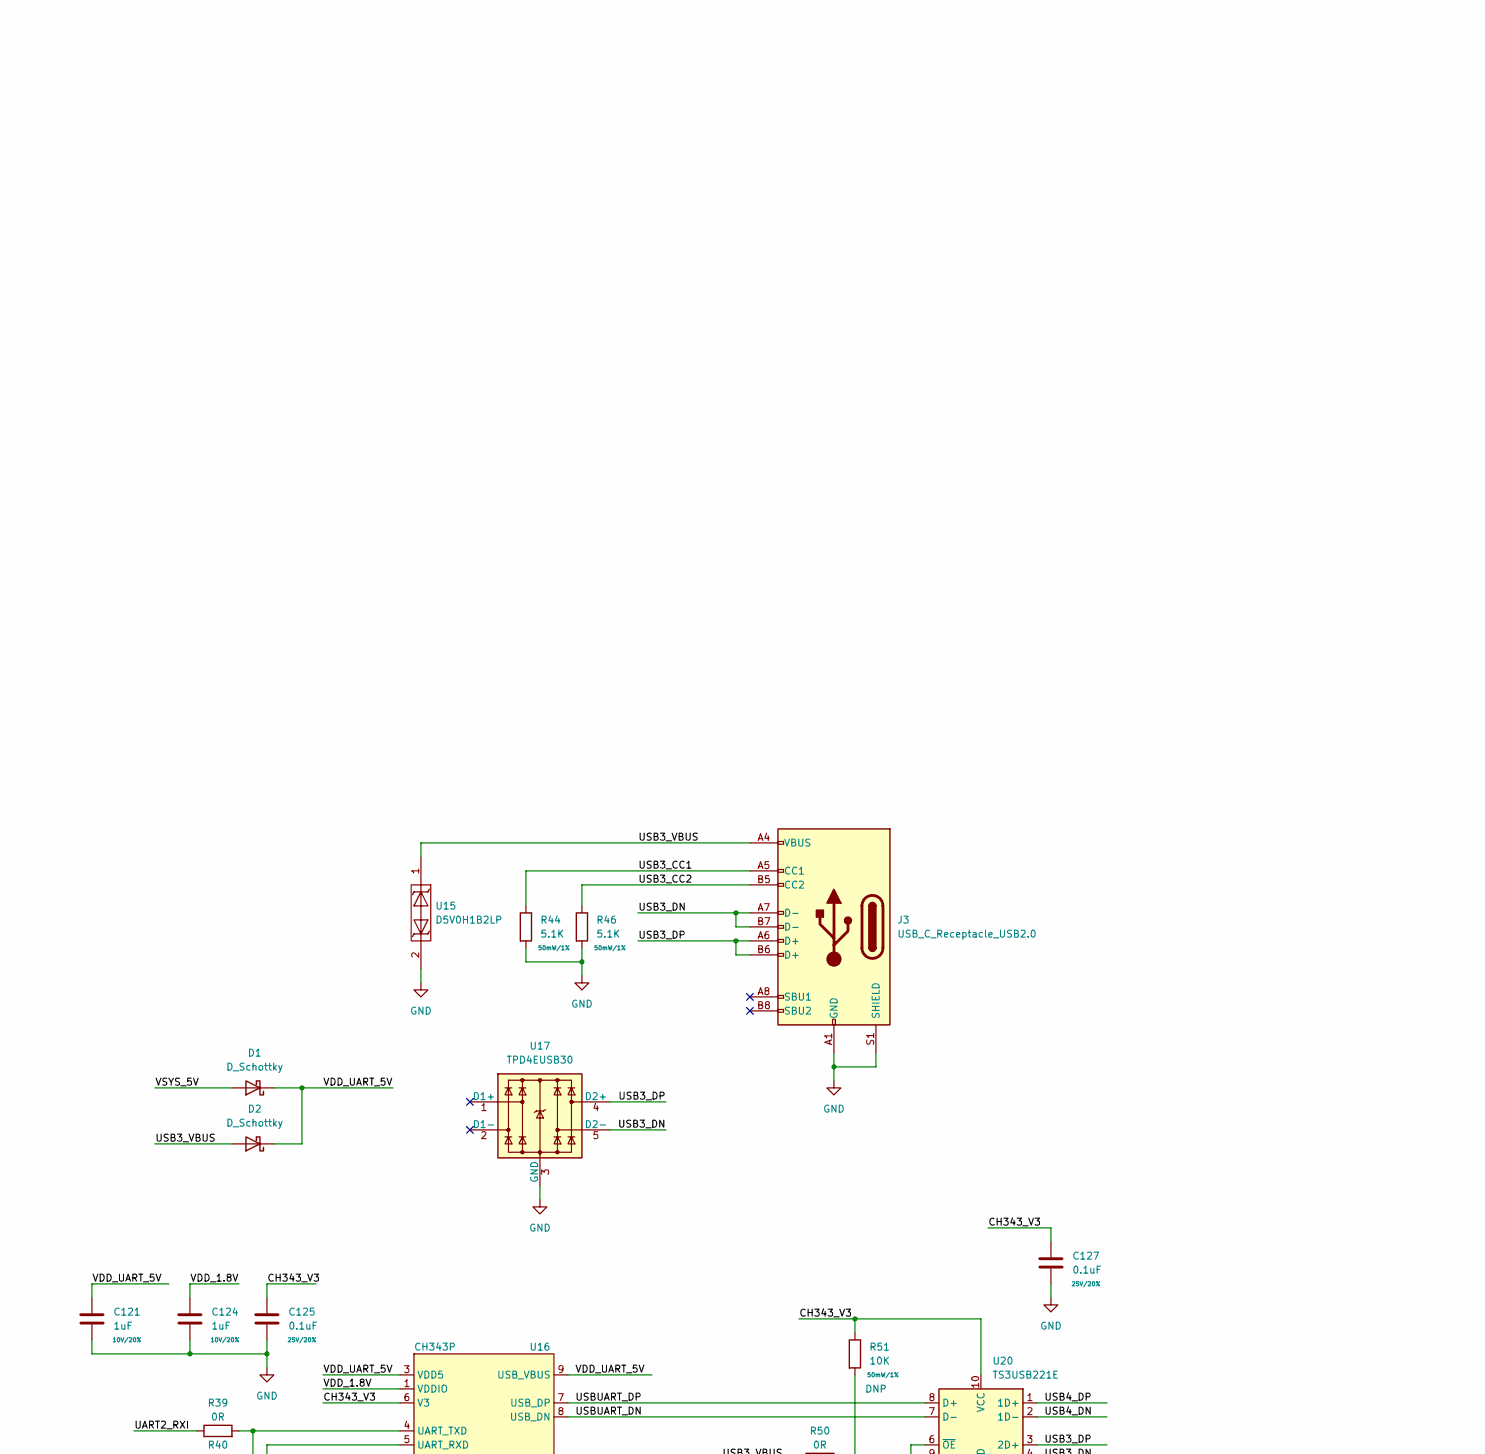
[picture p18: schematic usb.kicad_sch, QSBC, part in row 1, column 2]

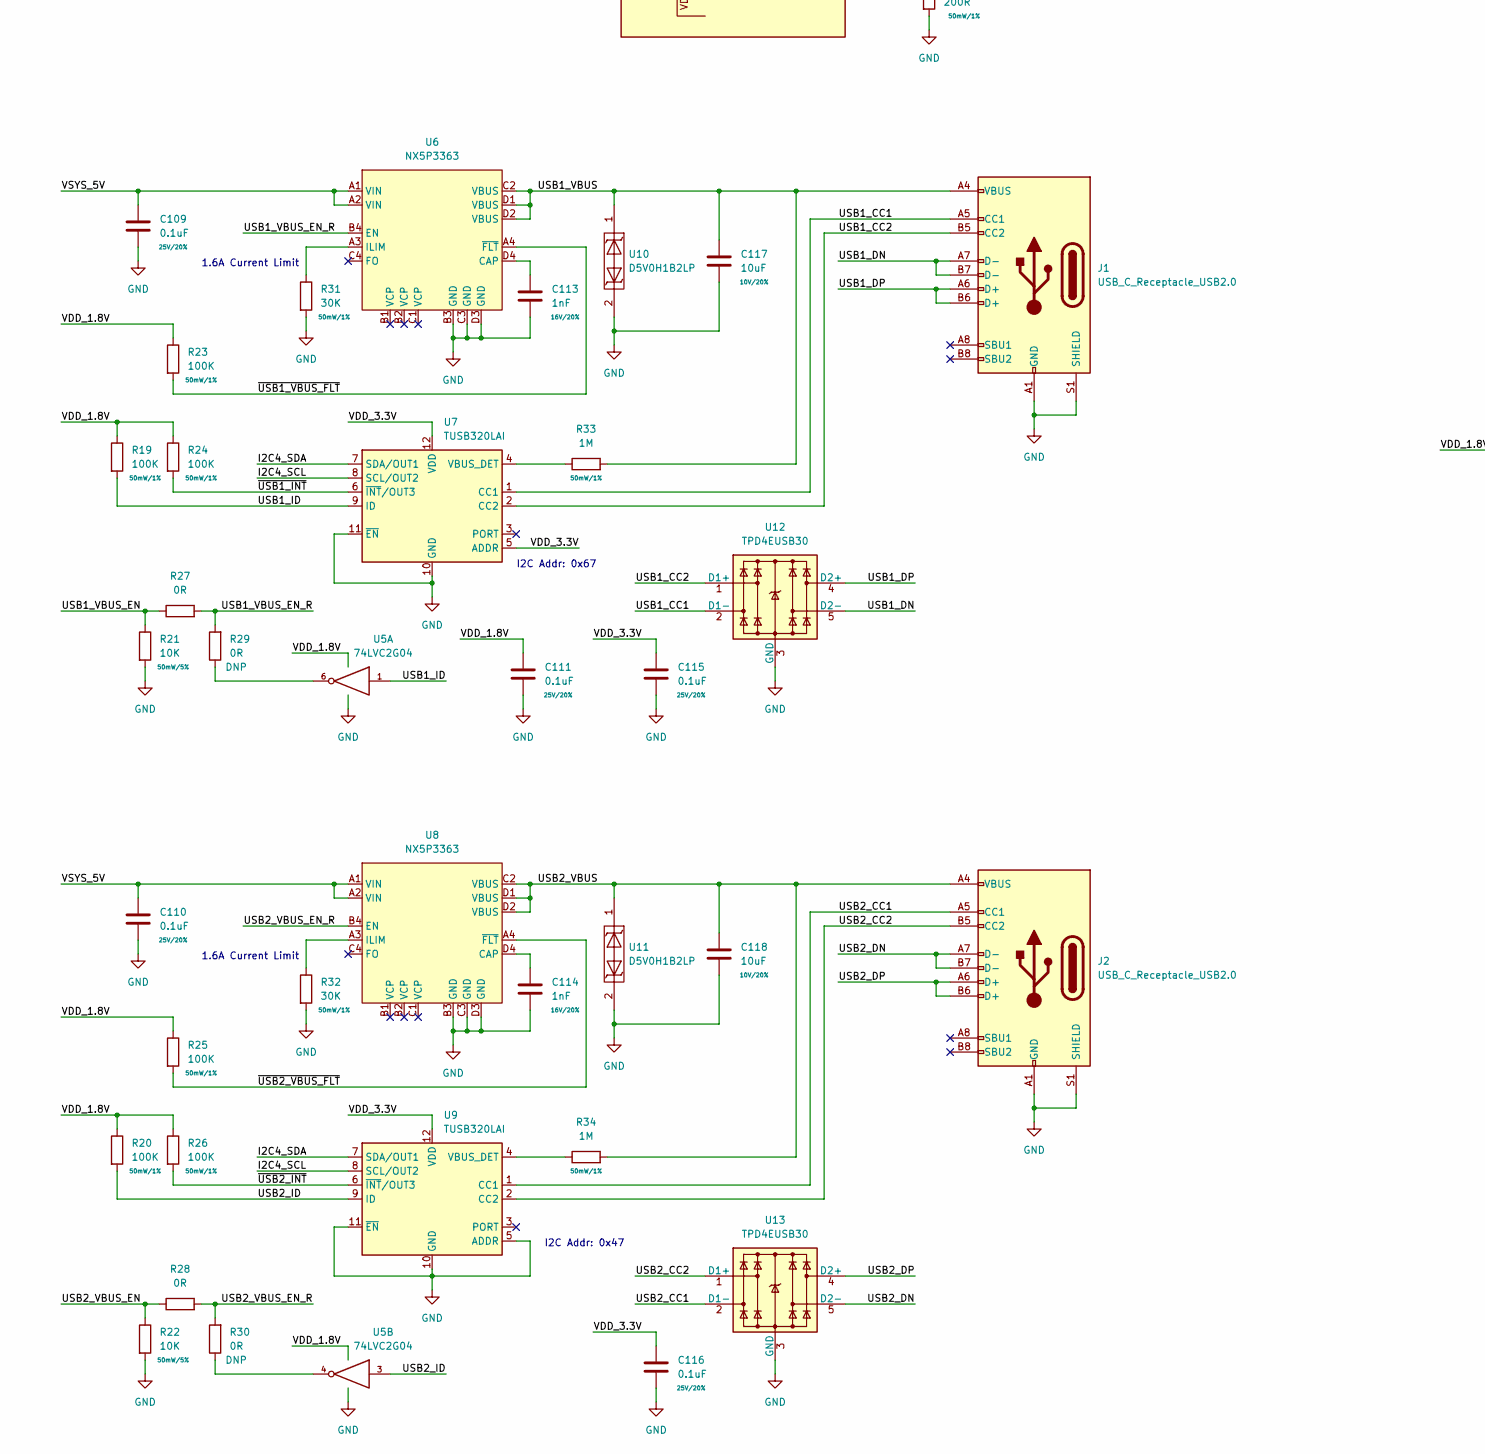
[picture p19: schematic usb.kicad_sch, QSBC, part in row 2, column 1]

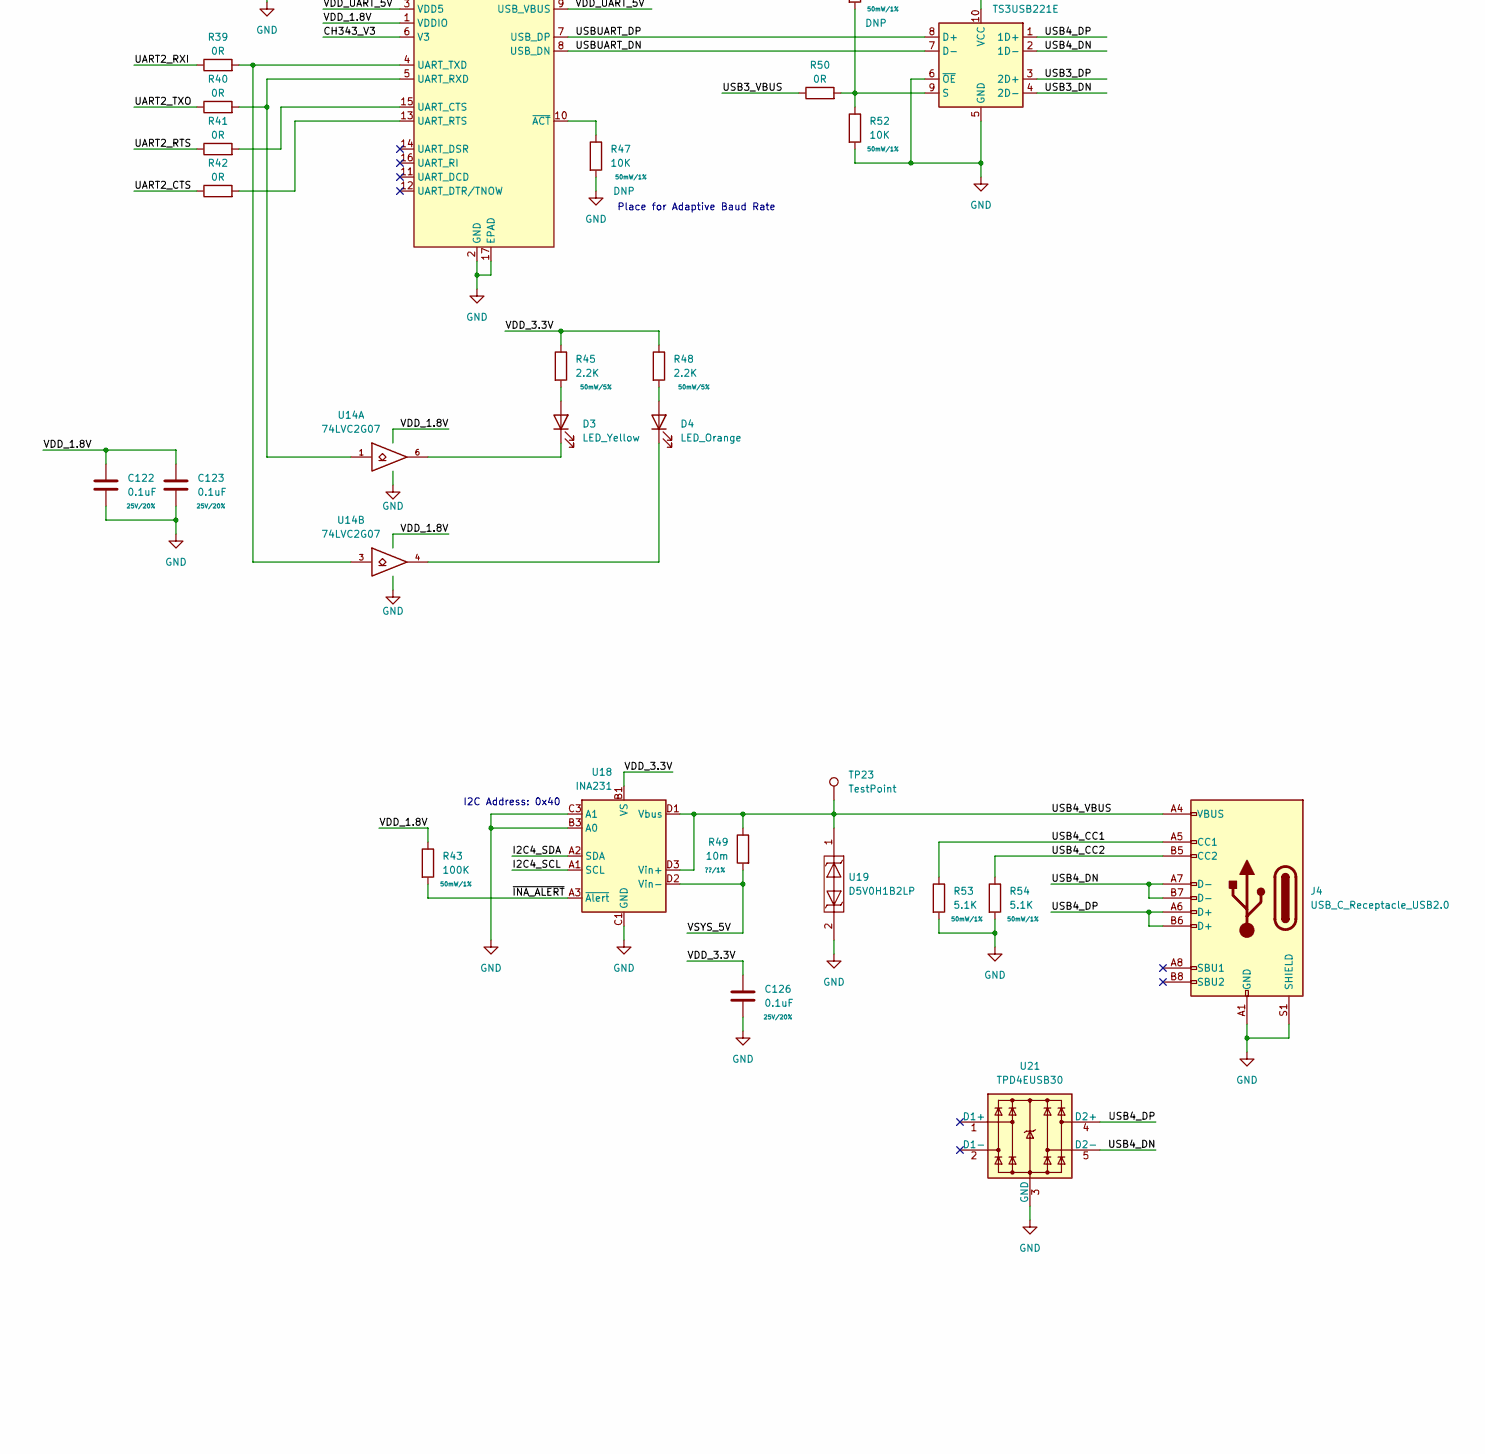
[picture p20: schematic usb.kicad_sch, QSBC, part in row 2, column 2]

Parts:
C109, C110, C111, C115, C116, C122, C123, C125, C126, C127: 0.1uF; C_0402_1005Metric; Rating 25V/20%
C113, C114: 1nF; C_0402_1005Metric; Rating 16V/20%
C117, C118: 10uF; C_0603_1608Metric; Rating 10V/20%
C119, C120: 0.22uF; C_0201_0603Metric; Rating 10V/20%
C121, C124: 1uF; C_0402_1005Metric; Rating 10V/20%
D1, D2: D_Schottky; D_SOD-523
D3: LED_Yellow; LED_0603_1608Metric
D4: LED_Orange; LED_0603_1608Metric
J1, J2, J3, J4: USB_C_Receptacle_USB2.0; USB_C_Receptacle_HRO_TYPE-C-31-M-12
R19, R20, R23, R24, R25, R26, R43: 100K; R_0402_1005Metric; Rating 50mW/1%
R21, R22: 10K; R_0402_1005Metric; Rating 50mW/5%
R27, R28, R29, R30, R39, R40, R41, R42, R50: 0R; R_0402_1005Metric
R31, R32, R37, R38: 30K; R_0201_0603Metric; Rating 50mW/1%
R33, R34: 1M; R_0402_1005Metric; Rating 50mW/1%
R35: 200R; R_0201_0603Metric; Rating 50mW/1%
R36: 200R; R_0402_1005Metric; Rating 50mW/1%
R44, R46, R53, R54: 5.1K; R_0402_1005Metric; Rating 50mW/1%
R45, R48: 2.2K; R_0402_1005Metric; Rating 50mW/5%
R47, R51, R52: 10K; R_0402_1005Metric; Rating 50mW/1%
R49: 10m; R_1206_3216Metric; Rating ??/1%
TP23: TestPoint; TestPoint_Pad_D1.0mm
U1: MIMX8MM6DVTLZAA; SOT1967-1
U5: 74LVC2G04; SOT-886
U6, U8: NX5P3363; WLCSP-16_2.225x2.17mm_P0.5mm
U7, U9: TUSB320LAI; Texas_X2QFN-12_1.6x1.6mm_P0.4mm
U10, U11, U15, U19: D5V0H1B2LP; DFN100X60X45-2N
U12, U13, U17, U21: TPD4EUSB30; USON-10_2.5x1.0mm_P0.5mm
U14: 74LVC2G07; SOT-886
U16: CH343P; QFN-16-1EP_3x3mm_P0.5mm_EP1.45x1.45mm_ThermalVias
U18: INA231; DSBGA-12
U20: TS3USB221E; Texas_R-PUQFN-N10

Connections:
/Peripherals/I2C4_SCL: U7.8 (SCL/OUT2), U9.8 (SCL/OUT2), U18.A1 (SCL); also elsewhere on the board
/Peripherals/I2C4_SDA: U7.7 (SDA/OUT1), U9.7 (SDA/OUT1), U18.A2 (SDA); also elsewhere on the board
/Peripherals/UART2_CTS: R42.1; also elsewhere on the board
/Peripherals/UART2_RTS: R41.1; also elsewhere on the board
/Peripherals/UART2_RXI: R39.1; also elsewhere on the board
/Peripherals/UART2_TXO: R40.1; also elsewhere on the board
/Peripherals/USB1_VBUS_EN: R21.1, R27.1; also elsewhere on the board
/Peripherals/USB2_VBUS_EN: R22.1, R28.1; also elsewhere on the board
/Peripherals/~INA_ALERT: R43.2, U18.A3 (~Alert); also elsewhere on the board
/Peripherals/~USB1_INT: R24.2, U7.6 (~INT/OUT3); also elsewhere on the board
/Peripherals/~USB1_VBUS_FLT: R23.2, U6.A4 (~FLT); also elsewhere on the board
/Peripherals/~USB2_INT: R26.2, U9.6 (~INT/OUT3); also elsewhere on the board
/Peripherals/~USB2_VBUS_FLT: R25.2, U8.A4 (~FLT); also elsewhere on the board
/Power/VSYS_5V: C109.1, C110.1, D1.2 (A), R49.2, U6.A1 (VIN), U6.A2 (VIN), U8.A1 (VIN), U8.A2 (VIN), U18.D2 (Vin-); also elsewhere on the board
/USB/CH343_V3: C125.1, C127.1, R51.1, U16.6 (V3), U20.10 (VCC)
/USB/USB1_CC1: J1.A5 (CC1), U7.1 (CC1), U12.2 (D1-), U12.9
/USB/USB1_CC2: J1.B5 (CC2), U7.2 (CC2), U12.1 (D1+), U12.10
/USB/USB1_DN: J1.A7 (D-), J1.B7 (D-), U1.A22 (USB1_DN), U12.5 (D2-), U12.6
/USB/USB1_DP: J1.A6 (D+), J1.B6 (D+), U1.B22 (USB1_DP), U12.4 (D2+), U12.7
/USB/USB1_ID: R19.2, U1.D22 (USB1_ID), U5.1, U7.9 (ID)
/USB/USB1_VBUS: C117.1, C119.1, J1.A4 (VBUS), J1.A9 (VBUS), J1.B4 (VBUS), J1.B9 (VBUS), R33.2, R37.2, U6.C2 (VBUS), U6.D1 (VBUS), U6.D2 (VBUS), U10.1
/USB/USB1_VBUS_EN_R: R27.2, R29.2, U6.B4 (EN)
/USB/USB2_CC1: J2.A5 (CC1), U9.1 (CC1), U13.2 (D1-), U13.9
/USB/USB2_CC2: J2.B5 (CC2), U9.2 (CC2), U13.1 (D1+), U13.10
/USB/USB2_DN: J2.A7 (D-), J2.B7 (D-), U1.A23 (USB2_DN), U13.5 (D2-), U13.6
/USB/USB2_DP: J2.A6 (D+), J2.B6 (D+), U1.B23 (USB2_DP), U13.4 (D2+), U13.7
/USB/USB2_ID: R20.2, U1.D23 (USB2_ID), U5.3, U9.9 (ID)
/USB/USB2_VBUS: C118.1, C120.1, J2.A4 (VBUS), J2.A9 (VBUS), J2.B4 (VBUS), J2.B9 (VBUS), R34.2, R38.2, U8.C2 (VBUS), U8.D1 (VBUS), U8.D2 (VBUS), U11.1
/USB/USB2_VBUS_EN_R: R28.2, R30.2, U8.B4 (EN)
/USB/USB3_CC1: J3.A5 (CC1), R44.1
/USB/USB3_CC2: J3.B5 (CC2), R46.1
/USB/USB3_DN: J3.A7 (D-), J3.B7 (D-), U17.5 (D2-), U17.6, U20.4 (2D-)
/USB/USB3_DP: J3.A6 (D+), J3.B6 (D+), U17.4 (D2+), U17.7, U20.3 (2D+)
/USB/USB3_VBUS: D2.2 (A), J3.A4 (VBUS), J3.A9 (VBUS), J3.B4 (VBUS), J3.B9 (VBUS), R50.1, U15.1
/USB/USB4_CC1: J4.A5 (CC1), R53.1
/USB/USB4_CC2: J4.B5 (CC2), R54.1
/USB/USB4_DN: J4.A7 (D-), J4.B7 (D-), U20.2 (1D-), U21.5 (D2-), U21.6
/USB/USB4_DP: J4.A6 (D+), J4.B6 (D+), U20.1 (1D+), U21.4 (D2+), U21.7
/USB/USB4_VBUS: J4.A4 (VBUS), J4.A9 (VBUS), J4.B4 (VBUS), J4.B9 (VBUS), R49.1, TP23.1, U18.D1 (Vbus), U18.D3 (Vin+), U19.1
/USB/USBUART_DN: U16.8 (USB_DN), U20.7 (D-)
/USB/USBUART_DP: U16.7 (USB_DP), U20.8 (D+)
/USB/VDD_UART_5V: C121.1, D1.1 (K), D2.1 (K), U16.3 (VDD5), U16.9 (USB_VBUS)
GND: C109.2, C110.2, C111.2, C113.2, C114.2, C115.2, C116.2, C117.2, C118.2, C119.2, C120.2, C121.2, C122.2, C123.2, C124.2, C125.2, C126.2, C127.2, J1.A1 (GND), J1.A12 (GND), J1.B1 (GND), J1.B12 (GND), J1.S1 (SHIELD), J2.A1 (GND), J2.A12 (GND), J2.B1 (GND), J2.B12 (GND), J2.S1 (SHIELD), J3.A1 (GND), J3.A12 (GND), J3.B1 (GND), J3.B12 (GND), J3.S1 (SHIELD), J4.A1 (GND), J4.A12 (GND), J4.B1 (GND), J4.B12 (GND), J4.S1 (SHIELD), R21.2, R22.2, R31.2, R32.2, R35.2, R36.2, R44.2, R46.2, R47.2, R52.2, R53.2, R54.2, U5.2 (GND), U6.B3 (GND), U6.C3 (GND), U6.D3 (GND), U7.10 (GND), U7.11 (~EN), U8.B3 (GND), U8.C3 (GND), U8.D3 (GND), U9.5 (ADDR), U9.10 (GND), U9.11 (~EN), U10.2, U11.2, U12.3 (GND), U12.8 (GND), U13.3 (GND), U13.8 (GND), U14.2 (GND), U15.2, U16.2 (GND), U16.17 (EPAD), U17.3 (GND), U17.8 (GND), U18.B3 (A0), U18.C1 (GND), U18.C3 (A1), U19.2, U20.5 (GND), U20.6 (~OE), U21.3 (GND), U21.8 (GND); also elsewhere on the board
unnamed: C113.1, U6.D4 (CAP)
unnamed: C114.1, U8.D4 (CAP)
unnamed: D3.1 (K), U14.6
unnamed: D3.2 (A), R45.2
unnamed: D4.1 (K), U14.4
unnamed: D4.2 (A), R48.2
unnamed: R29.1, U5.6
unnamed: R30.1, U5.4
unnamed: R31.1, U6.A3 (ILIM)
unnamed: R32.1, U8.A3 (ILIM)
unnamed: R33.1, U7.4 (VBUS_DET)
unnamed: R34.1, U9.4 (VBUS_DET)
unnamed: R35.1, U1.E19 (USB1_TXRTUNE)
unnamed: R36.1, U1.E22 (USB2_TXRTUNE)
unnamed: R37.1, U1.F22 (USB1_VBUS)
unnamed: R38.1, U1.F23 (USB2_VBUS)
unnamed: R39.2, U14.3, U16.4 (UART_TXD)
unnamed: R40.2, U14.1, U16.5 (UART_RXD)
unnamed: R41.2, U16.15 (UART_CTS)
unnamed: R42.2, U16.13 (UART_RTS)
unnamed: R47.1, U16.10 (~ACT)
unnamed: R50.2, R51.2, R52.1, U20.9 (S)
VDD_1.8V: C111.1, C122.1, C123.1, C124.1, R19.1, R20.1, R23.1, R24.1, R25.1, R26.1, R43.1, U5.5 (VCC), U14.5 (VCC), U16.1 (VDDIO); also elsewhere on the board
VDD_3.3V: C115.1, C116.1, C126.1, R45.1, R48.1, U7.5 (ADDR), U7.12 (VDD), U9.12 (VDD), U18.B1 (VS); also elsewhere on the board

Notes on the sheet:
Place for Adaptive Baud Rate
I2C Addr: 0x67
I2C Addr: 0x47
1.6A Current Limit
I2C Address: 0x40

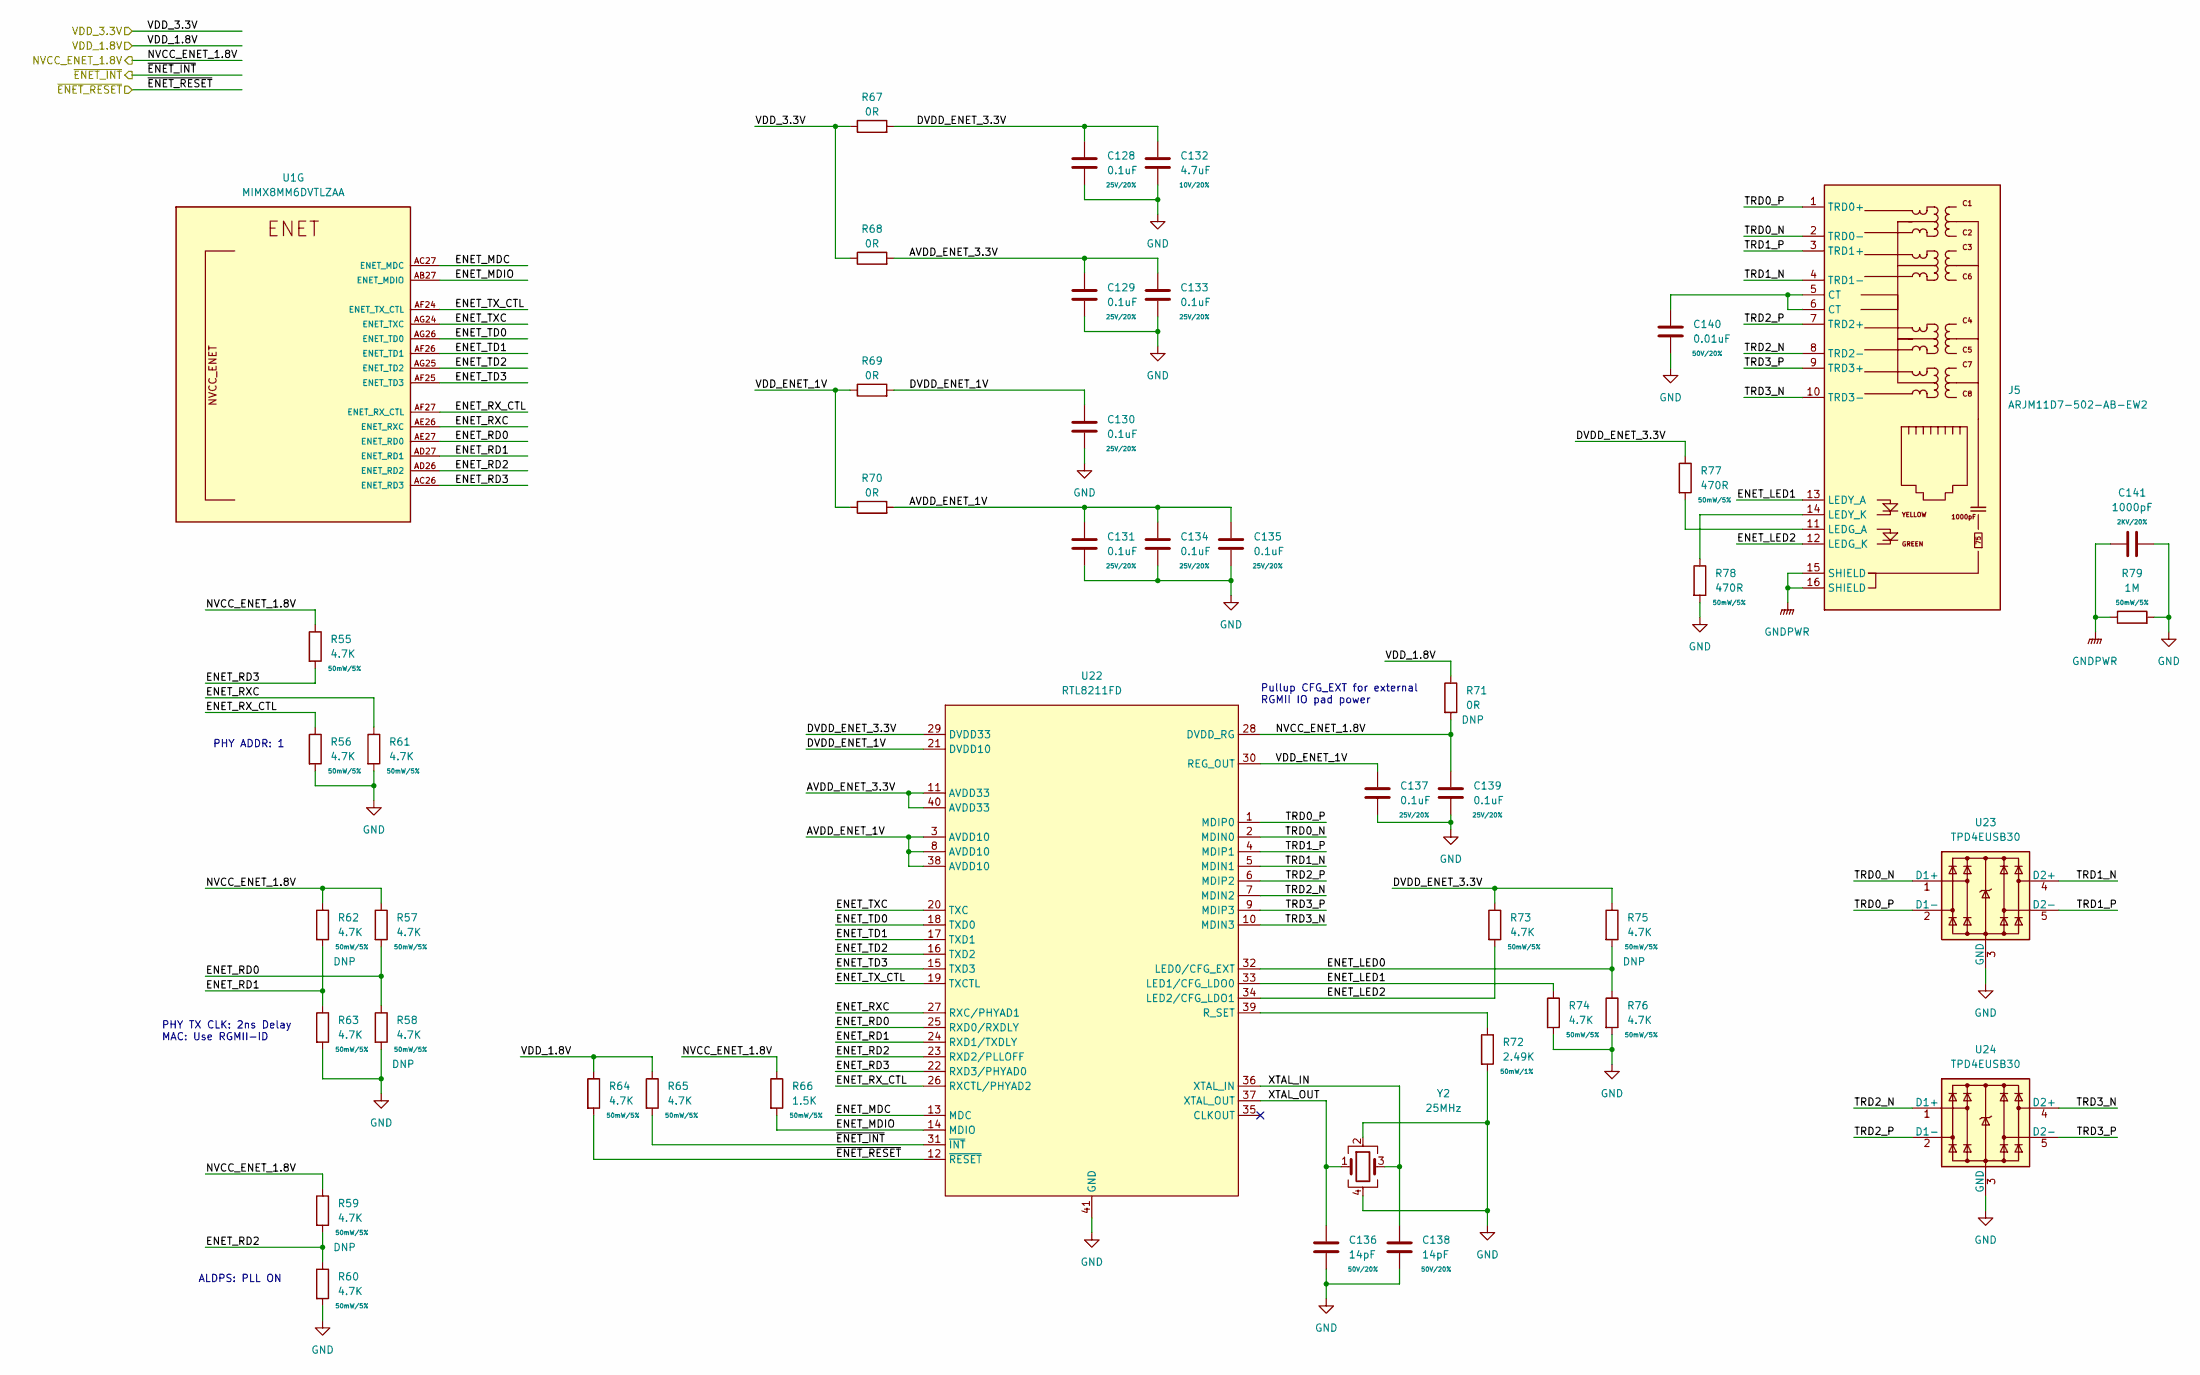
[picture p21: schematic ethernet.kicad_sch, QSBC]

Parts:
C128, C129, C130, C131, C133, C134, C135, C137, C139: 0.1uF; C_0402_1005Metric; Rating 25V/20%
C132: 4.7uF; C_0402_1005Metric; Rating 10V/20%
C136, C138: 14pF; C_0402_1005Metric; Rating 50V/20%
C140: 0.01uF; C_0603_1608Metric; Rating 50V/20%
C141: 1000pF; C_1210_3225Metric; Rating 2KV/20%
J5: ARJM11D7-502-AB-EW2
R55, R56, R57, R58, R59, R60, R61, R62, R63, R64, R65, R73, R74, R75, R76: 4.7K; R_0402_1005Metric; Rating 50mW/5%
R66: 1.5K; R_0402_1005Metric; Rating 50mW/5%
R67, R68, R69, R70, R71: 0R; R_0402_1005Metric
R72: 2.49K; R_0402_1005Metric; Rating 50mW/1%
R77, R78: 470R; R_0402_1005Metric; Rating 50mW/5%
R79: 1M; R_1206_3216Metric; Rating 50mW/5%
U1: MIMX8MM6DVTLZAA; SOT1967-1
U22: RTL8211FD; QFN-40-1EP_5x5mm_P0.4mm_EP3.6x3.6mm_ThermalVias
U23, U24: TPD4EUSB30; USON-10_2.5x1.0mm_P0.5mm
Y2: 25MHz; Crystal_SMD_3225-4Pin_3.2x2.5mm; MPN ECS-250-10-33B-CWN-TR

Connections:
/Ethernet/AVDD_ENET_1V: C131.1, C134.1, C135.1, R70.2, U22.3 (AVDD10), U22.8 (AVDD10), U22.38 (AVDD10)
/Ethernet/AVDD_ENET_3.3V: C129.1, C133.1, R68.2, U22.11 (AVDD33), U22.40 (AVDD33)
/Ethernet/DVDD_ENET_1V: C130.1, R69.2, U22.21 (DVDD10)
/Ethernet/DVDD_ENET_3.3V: C128.1, C132.1, R67.2, R73.1, R75.1, R77.1, U22.29 (DVDD33)
/Ethernet/ENET_LED0: R75.2, R76.1, U22.32 (LED0/CFG_EXT)
/Ethernet/ENET_LED1: J5.13 (LEDY_A), R74.1, U22.33 (LED1/CFG_LDO0)
/Ethernet/ENET_LED2: J5.12 (LEDG_K), R73.2, U22.34 (LED2/CFG_LDO1)
/Ethernet/ENET_MDC: U1.AC27 (ENET_MDC), U22.13 (MDC)
/Ethernet/ENET_MDIO: R66.2, U1.AB27 (ENET_MDIO), U22.14 (MDIO)
/Ethernet/ENET_RD0: R57.2, R58.1, U1.AE27 (ENET_RD0), U22.25 (RXD0/RXDLY)
/Ethernet/ENET_RD1: R62.2, R63.1, U1.AD27 (ENET_RD1), U22.24 (RXD1/TXDLY)
/Ethernet/ENET_RD2: R59.2, R60.1, U1.AD26 (ENET_RD2), U22.23 (RXD2/PLLOFF)
/Ethernet/ENET_RD3: R55.2, U1.AC26 (ENET_RD3), U22.22 (RXD3/PHYAD0)
/Ethernet/ENET_RXC: R61.1, U1.AE26 (ENET_RXC), U22.27 (RXC/PHYAD1)
/Ethernet/ENET_RX_CTL: R56.1, U1.AF27 (ENET_RX_CTL), U22.26 (RXCTL/PHYAD2)
/Ethernet/ENET_TD0: U1.AG26 (ENET_TD0), U22.18 (TXD0)
/Ethernet/ENET_TD1: U1.AF26 (ENET_TD1), U22.17 (TXD1)
/Ethernet/ENET_TD2: U1.AG25 (ENET_TD2), U22.16 (TXD2)
/Ethernet/ENET_TD3: U1.AF25 (ENET_TD3), U22.15 (TXD3)
/Ethernet/ENET_TXC: U1.AG24 (ENET_TXC), U22.20 (TXC)
/Ethernet/ENET_TX_CTL: U1.AF24 (ENET_TX_CTL), U22.19 (TXCTL)
/Ethernet/NVCC_ENET_1.8V: C139.1, R55.1, R57.1, R59.1, R62.1, R66.1, R71.2, U22.28 (DVDD_RG); also elsewhere on the board
/Ethernet/TRD0_N: J5.2 (TRD0-), U22.2 (MDIN0), U23.1 (D1+), U23.10
/Ethernet/TRD0_P: J5.1 (TRD0+), U22.1 (MDIP0), U23.2 (D1-), U23.9
/Ethernet/TRD1_N: J5.4 (TRD1-), U22.5 (MDIN1), U23.4 (D2+), U23.7
/Ethernet/TRD1_P: J5.3 (TRD1+), U22.4 (MDIP1), U23.5 (D2-), U23.6
/Ethernet/TRD2_N: J5.8 (TRD2-), U22.7 (MDIN2), U24.1 (D1+), U24.10
/Ethernet/TRD2_P: J5.7 (TRD2+), U22.6 (MDIP2), U24.2 (D1-), U24.9
/Ethernet/TRD3_N: J5.10 (TRD3-), U22.10 (MDIN3), U24.4 (D2+), U24.7
/Ethernet/TRD3_P: J5.9 (TRD3+), U22.9 (MDIP3), U24.5 (D2-), U24.6
/Ethernet/VDD_ENET_1V: C137.1, R69.1, R70.1, U22.30 (REG_OUT)
/Ethernet/XTAL_IN: C138.1, U22.36 (XTAL_IN), Y2.3
/Ethernet/XTAL_OUT: C136.1, U22.37 (XTAL_OUT), Y2.1
/Ethernet/~ENET_INT: R65.2, U22.31 (~INT); also elsewhere on the board
/Ethernet/~ENET_RESET: R64.2, U22.12 (~RESET); also elsewhere on the board
GND: C128.2, C129.2, C130.2, C131.2, C132.2, C133.2, C134.2, C135.2, C136.2, C137.2, C138.2, C139.2, C140.2, C141.2, R56.2, R58.2, R60.2, R61.2, R63.2, R72.2, R74.2, R76.2, R78.2, R79.2, U22.41 (GND), U23.3 (GND), U23.8 (GND), U24.3 (GND), U24.8 (GND), Y2.2, Y2.4; also elsewhere on the board
GNDPWR: C141.1, J5.15 (SHIELD), J5.16 (SHIELD), R79.1
unnamed: C140.1, J5.5 (CT), J5.6 (CT)
unnamed: J5.11 (LEDG_A), R77.2
unnamed: J5.14 (LEDY_K), R78.1
unnamed: R72.1, U22.39 (R_SET)
VDD_1.8V: R64.1, R65.1, R71.1; also elsewhere on the board
VDD_3.3V: R67.1, R68.1; also elsewhere on the board

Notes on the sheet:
ALDPS: PLL ON
PHY ADDR: 1
Pullup CFG_EXT for external RGMII IO pad power
PHY TX CLK: 2ns Delay MAC: Use RGMII-ID

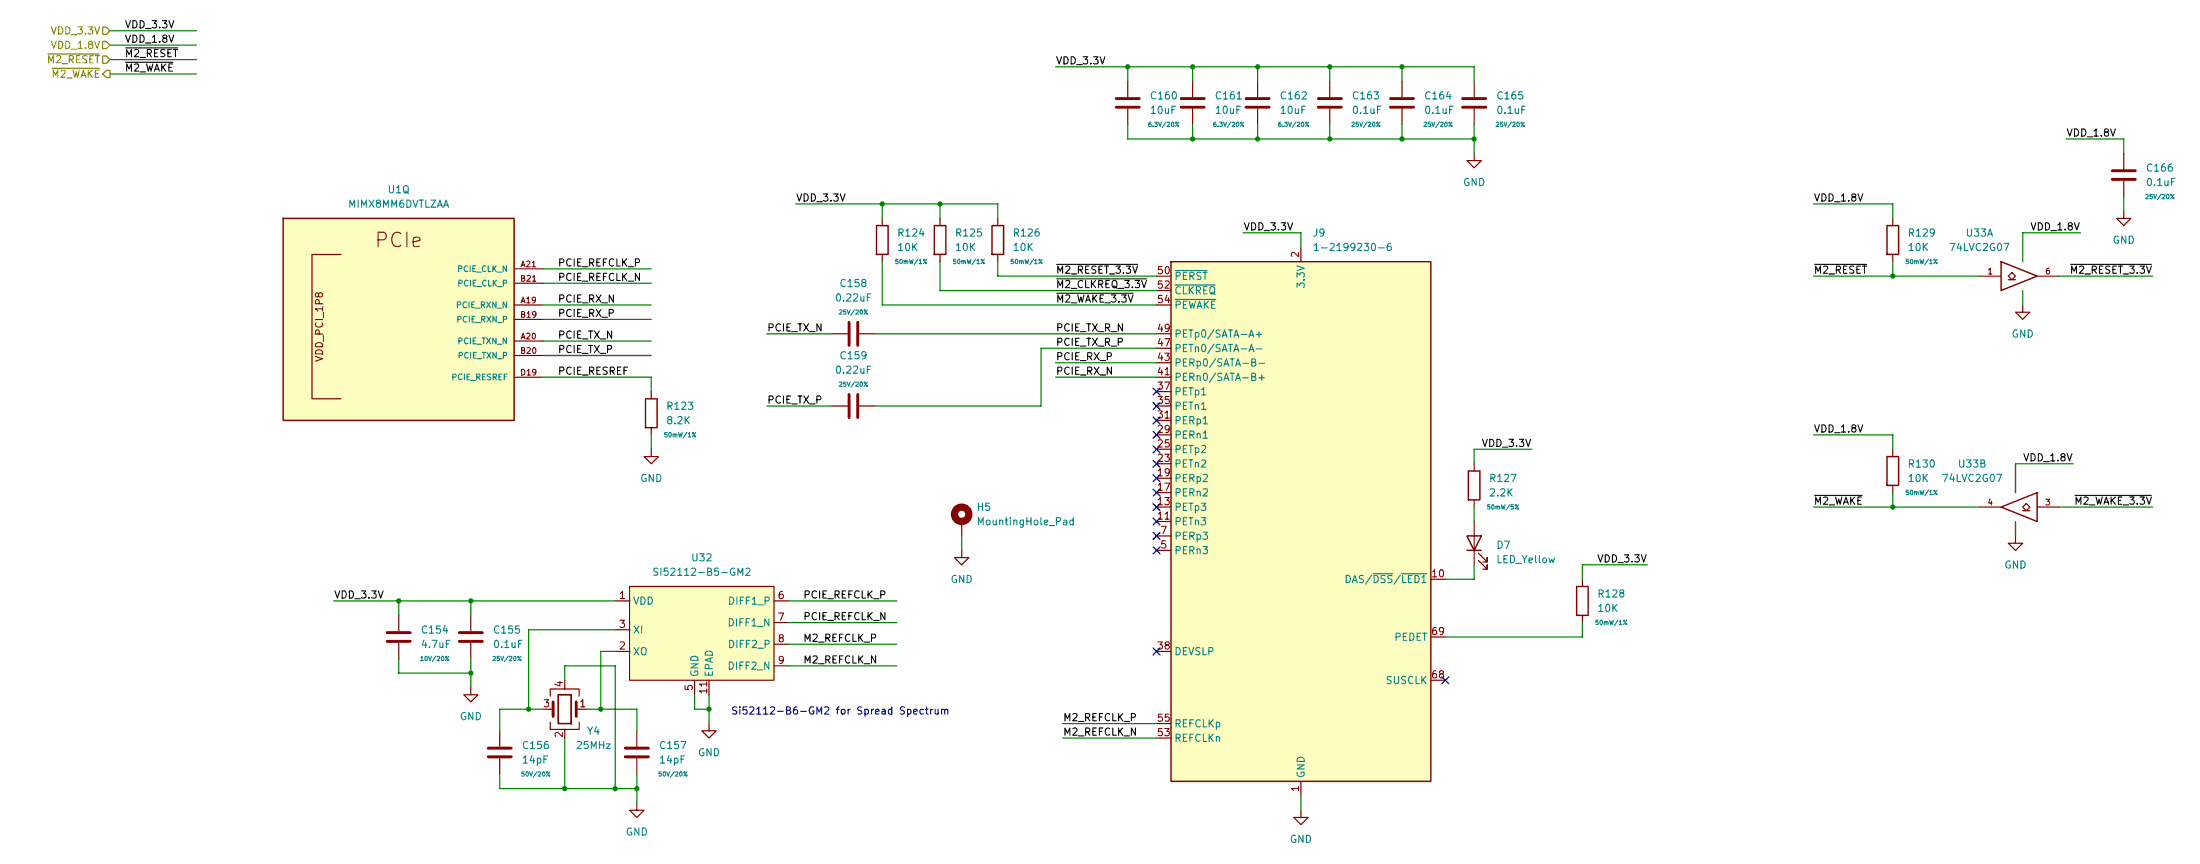
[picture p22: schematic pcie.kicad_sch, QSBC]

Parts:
C154: 4.7uF; C_0402_1005Metric; Rating 10V/20%
C155, C163, C164, C165, C166: 0.1uF; C_0402_1005Metric; Rating 25V/20%
C156, C157: 14pF; C_0402_1005Metric; Rating 50V/20%
C158, C159: 0.22uF; C_0201_0603Metric; Rating 25V/20%
C160, C161, C162: 10uF; C_0402_1005Metric; Rating 6.3V/20%
D7: LED_Yellow; LED_0603_1608Metric
H5: MountingHole_Pad; Mounting_Wuerth_WA-SMSI-M3_H2.5mm_9774025360
J9: 1-2199230-6
R123: 8.2K; R_0402_1005Metric; Rating 50mW/1%
R124, R125, R126, R128, R129, R130: 10K; R_0402_1005Metric; Rating 50mW/1%
R127: 2.2K; R_0402_1005Metric; Rating 50mW/5%
U1: MIMX8MM6DVTLZAA; SOT1967-1
U32: SI52112-B5-GM2; DFN-10-1EP_3x3mm_P0.5mm_EP1.55x2.48mm
U33: 74LVC2G07; SOT-886
Y4: 25MHz; Crystal_SMD_3225-4Pin_3.2x2.5mm; MPN ECS-250-10-33B-CWN-TR

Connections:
/PCIe/M2_REFCLK_N: J9.53 (REFCLKn), U32.9 (DIFF2_N)
/PCIe/M2_REFCLK_P: J9.55 (REFCLKp), U32.8 (DIFF2_P)
/PCIe/PCIE_REFCLK_N: U1.B21 (PCIE_CLK_P), U32.7 (DIFF1_N)
/PCIe/PCIE_REFCLK_P: U1.A21 (PCIE_CLK_N), U32.6 (DIFF1_P)
/PCIe/PCIE_RESREF: R123.1, U1.D19 (PCIE_RESREF)
/PCIe/PCIE_RX_N: J9.41 (PERn0/SATA-B+), U1.A19 (PCIE_RXN_N)
/PCIe/PCIE_RX_P: J9.43 (PERp0/SATA-B-), U1.B19 (PCIE_RXN_P)
/PCIe/PCIE_TX_N: C158.1, U1.A20 (PCIE_TXN_N)
/PCIe/PCIE_TX_P: C159.1, U1.B20 (PCIE_TXN_P)
/PCIe/PCIE_TX_R_N: C158.2, J9.49 (PETp0/SATA-A+)
/PCIe/PCIE_TX_R_P: C159.2, J9.47 (PETn0/SATA-A-)
/PCIe/~M2_CLKREQ_3.3V: J9.52 (~CLKREQ), R125.2
/PCIe/~M2_RESET_3.3V: J9.50 (~PERST), R126.2, U33.6
/PCIe/~M2_RESET: R129.2, U33.1; also elsewhere on the board
/PCIe/~M2_WAKE_3.3V: J9.54 (~PEWAKE), R124.2, U33.3
/PCIe/~M2_WAKE: R130.2, U33.4; also elsewhere on the board
GND: C154.2, C155.2, C156.2, C157.2, C160.2, C161.2, C162.2, C163.2, C164.2, C165.2, C166.2, H5.1, J9.1 (GND), J9.3 (GND), J9.9 (GND), J9.15 (GND), J9.21 (GND), J9.27 (GND), J9.33 (GND), J9.39 (GND), J9.45 (GND), J9.51 (GND), J9.57 (GND), J9.71 (GND), J9.73 (GND), J9.75 (GND), R123.2, U32.4 (GND), U32.5 (GND), U32.11 (EPAD), U33.2 (GND), Y4.2, Y4.4; also elsewhere on the board
unnamed: C156.1, U32.3 (XI), Y4.3
unnamed: C157.1, U32.2 (XO), Y4.1
unnamed: D7.1 (K), J9.10 (DAS/~DSS/~LED1)
unnamed: D7.2 (A), R127.2
unnamed: J9.69 (PEDET), R128.2
VDD_1.8V: C166.1, R129.1, R130.1, U33.5 (VCC); also elsewhere on the board
VDD_3.3V: C154.1, C155.1, C160.1, C161.1, C162.1, C163.1, C164.1, C165.1, J9.2 (3.3V), J9.4 (3.3V), J9.12 (3.3V), J9.14 (3.3V), J9.16 (3.3V), J9.18 (3.3V), J9.70 (3.3V), J9.72 (3.3V), J9.74 (3.3V), R124.1, R125.1, R126.1, R127.1, R128.1, U32.1 (VDD), U32.10 (VDD); also elsewhere on the board

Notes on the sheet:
Si52112-B6-GM2 for Spread Spectrum

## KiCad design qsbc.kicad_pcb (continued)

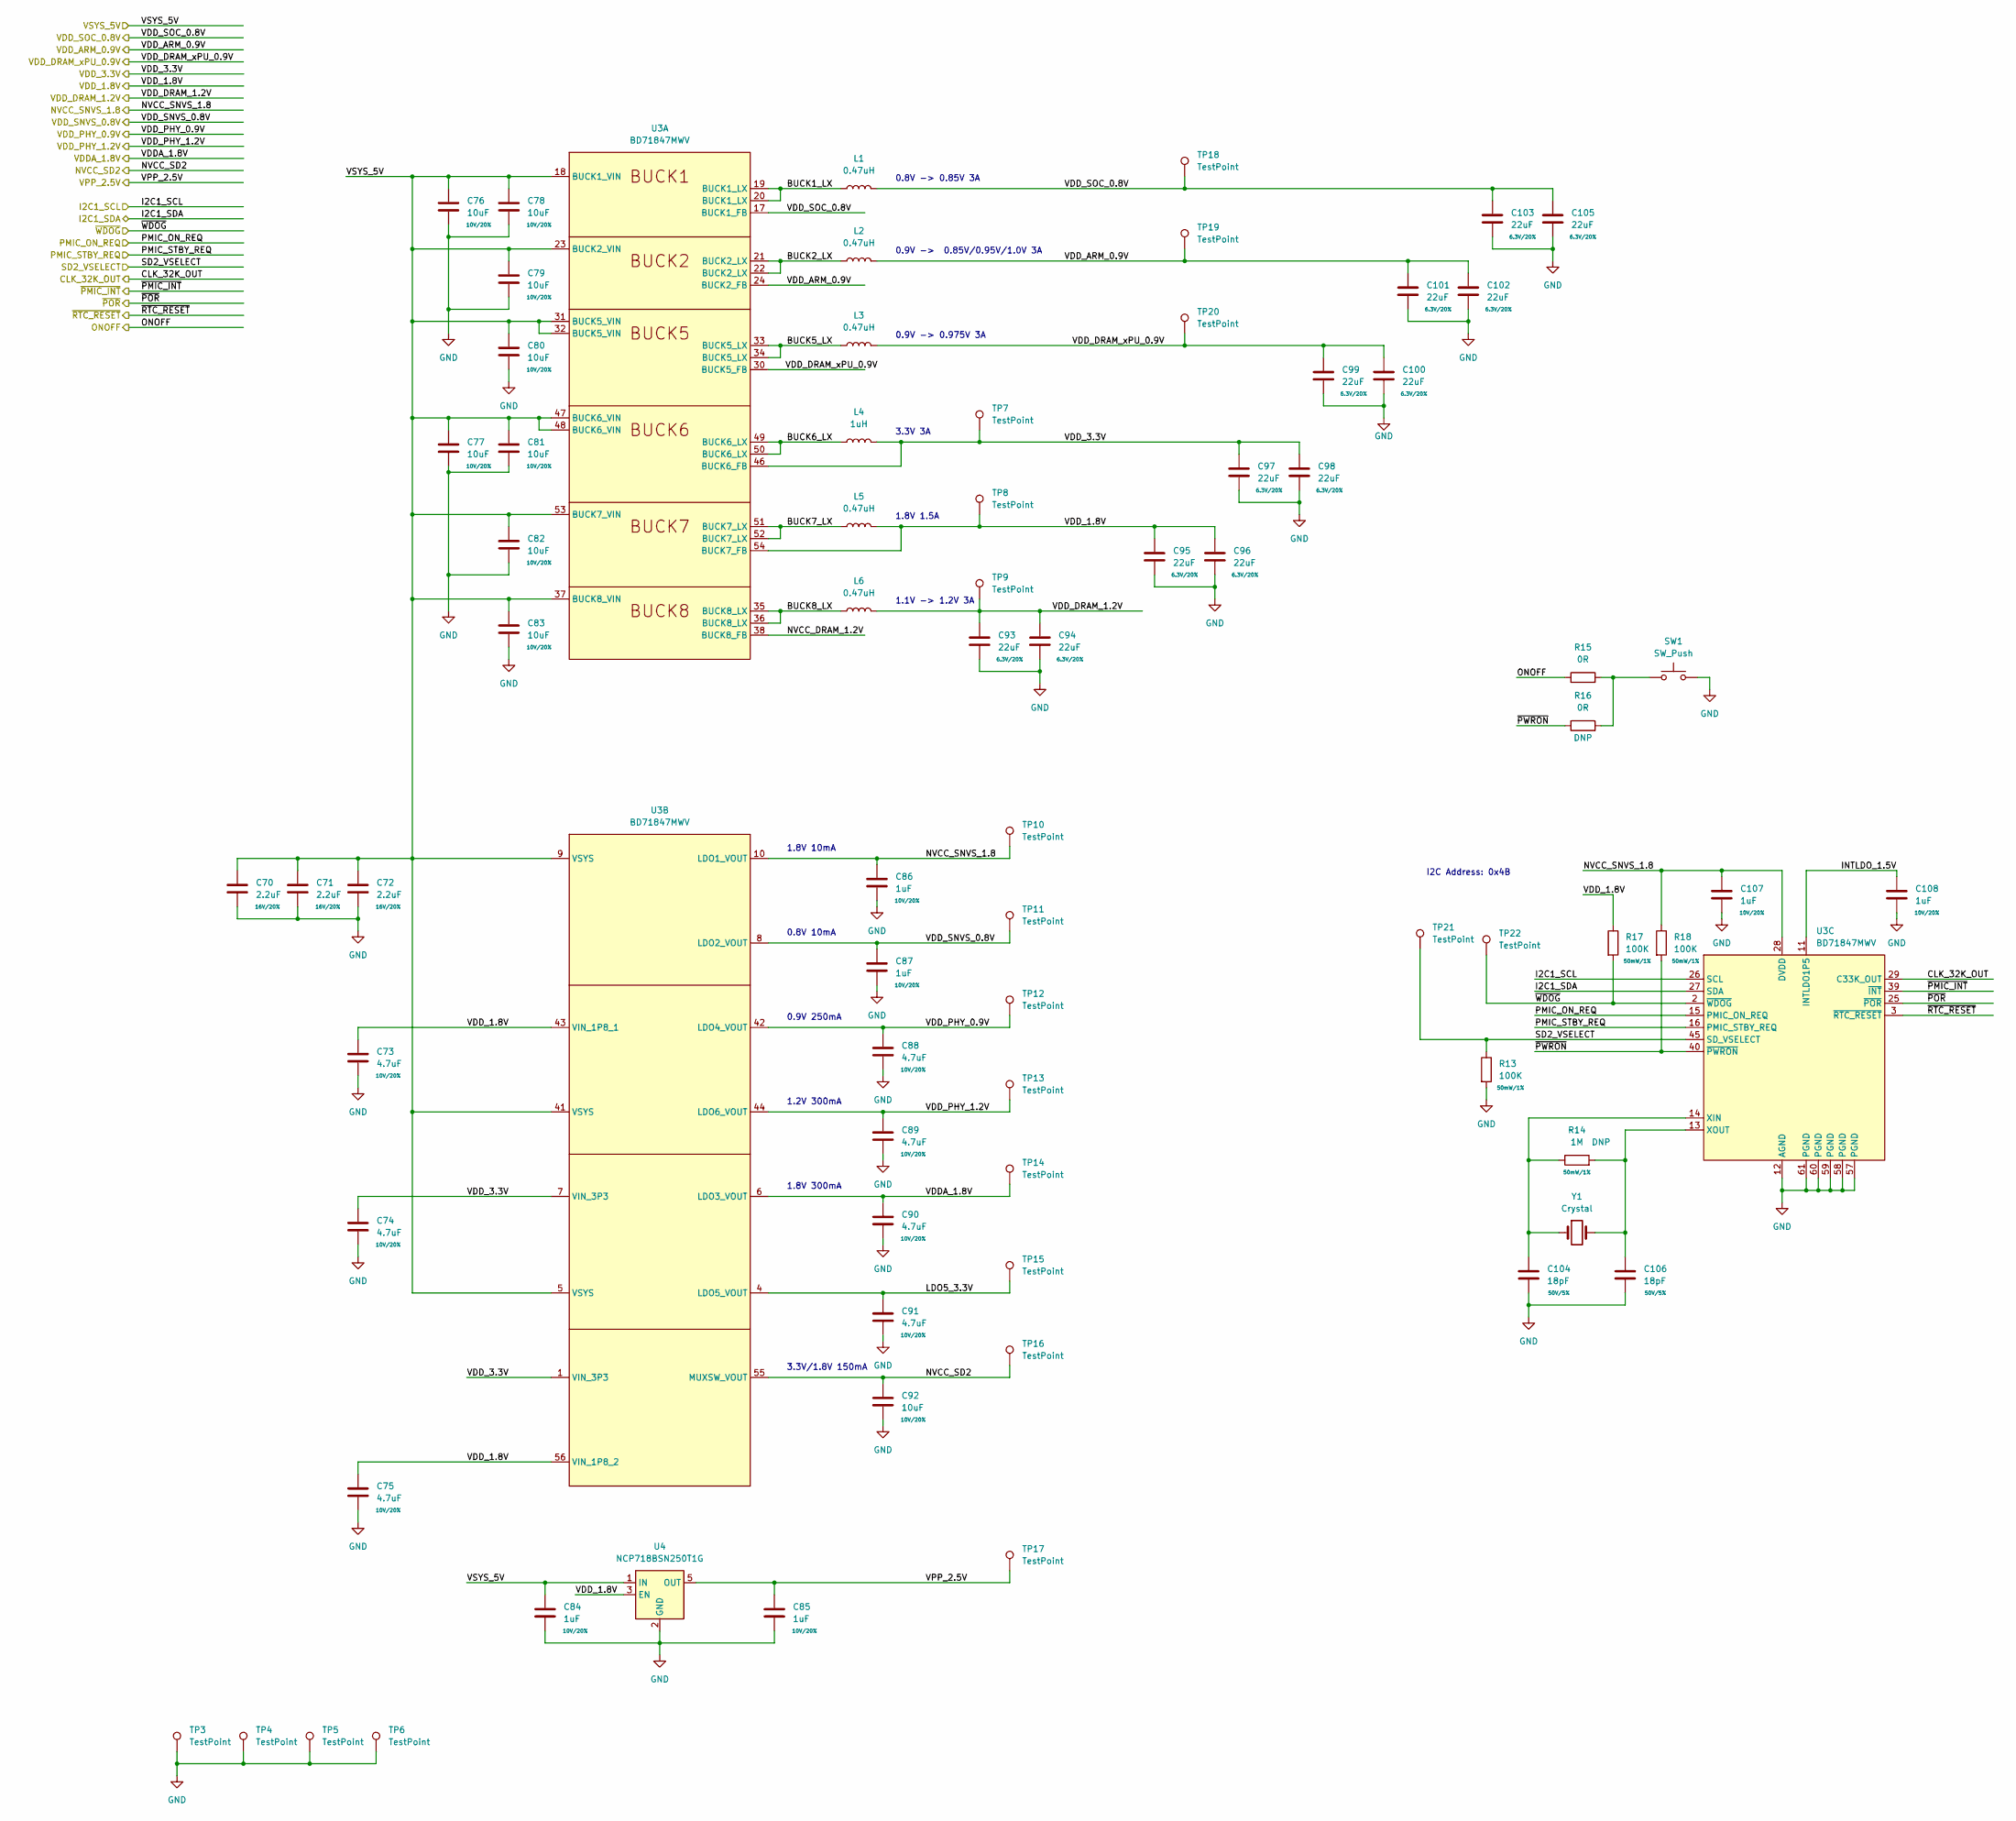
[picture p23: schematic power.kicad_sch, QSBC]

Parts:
C70, C71, C72: 2.2uF; C_0402_1005Metric; Rating 16V/20%
C73, C74, C75, C88, C89, C90, C91: 4.7uF; C_0402_1005Metric; Rating 10V/20%
C76, C77, C78, C79, C80, C81, C82, C83, C92: 10uF; C_0603_1608Metric; Rating 10V/20%
C84, C85, C86, C87, C107, C108: 1uF; C_0402_1005Metric; Rating 10V/20%
C93, C94, C95, C96, C97, C98, C99, C100, C101, C102, C103, C105: 22uF; C_0603_1608Metric; Rating 6.3V/20%
C104, C106: 18pF; C_0402_1005Metric; Rating 50V/5%
L1, L2, L3, L5, L6: 0.47uH; L_1008_2520Metric
L4: 1uH; L_1008_2520Metric
R13, R17, R18: 100K; R_0402_1005Metric; Rating 50mW/1%
R14: 1M; R_0402_1005Metric; Rating 50mW/1%
R15, R16: 0R; R_0402_1005Metric
SW1: SW_Push; SW_Tactile_SPST_Angled_PTS645Vx58-2LFS
TP3, TP4, TP5, TP6, TP7, TP8, TP9, TP10, TP11, TP12, TP13, TP14, TP15, TP16, TP17, TP18, TP19, TP20, TP21, TP22: TestPoint; TestPoint_Pad_D1.0mm
U3: BD71847MWV; UQFN56BV7070
U4: NCP718BSN250T1G; SOT-23-5
Y1: Crystal; Crystal_SMD_2012-2Pin_2.0x1.2mm

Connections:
/DDR/VDD_DRAM_1.2V: C93.1, C94.1, L6.2, TP9.1; also elsewhere on the board
/DDR/VPP_2.5V: C85.1, TP17.1, U4.5 (OUT); also elsewhere on the board
/Misc/CLK_32K_OUT: U3.29 (C33K_OUT); also elsewhere on the board
/Misc/NVCC_SNVS_1.8V: C86.1, C107.1, R18.1, TP10.1, U3.10 (LDO1_VOUT), U3.28 (DVDD); also elsewhere on the board
/Misc/ONOFF: R15.1; also elsewhere on the board
/Misc/PMIC_ON_REQ: U3.15 (PMIC_ON_REQ); also elsewhere on the board
/Misc/PMIC_STBY_REQ: U3.16 (PMIC_STBY_REQ); also elsewhere on the board
/Misc/VDD_SNVS_0.8V: C87.1, TP11.1, U3.8 (LDO2_VOUT); also elsewhere on the board
/Misc/~POR: U3.25 (~POR); also elsewhere on the board
/Misc/~RTC_RESET: U3.3 (~RTC_RESET); also elsewhere on the board
/Peripherals/I2C1_SCL: U3.26 (SCL); also elsewhere on the board
/Peripherals/I2C1_SDA: U3.27 (SDA); also elsewhere on the board
/Peripherals/SD2_VSELECT: R13.1, TP21.1, U3.45 (SD_VSELECT); also elsewhere on the board
/Peripherals/~PMIC_INT: U3.39 (~INT); also elsewhere on the board
/Power/BUCK1_LX: L1.1, U3.19 (BUCK1_LX), U3.20 (BUCK1_LX)
/Power/BUCK2_LX: L2.1, U3.21 (BUCK2_LX), U3.22 (BUCK2_LX)
/Power/BUCK5_LX: L3.1, U3.33 (BUCK5_LX), U3.34 (BUCK5_LX)
/Power/BUCK6_LX: L4.1, U3.49 (BUCK6_LX), U3.50 (BUCK6_LX)
/Power/BUCK7_LX: L5.1, U3.51 (BUCK7_LX), U3.52 (BUCK7_LX)
/Power/BUCK8_LX: L6.1, U3.35 (BUCK8_LX), U3.36 (BUCK8_LX)
/Power/INTLDO_1.5V: C108.1, U3.11 (INTLDO1P5)
/Power/LDO5_3.3V: C91.1, TP15.1, U3.4 (LDO5_VOUT)
/Power/NVCC_DRAM_1.2V: U3.38 (BUCK8_FB)
/Power/NVCC_SD2: C92.1, TP16.1, U3.55 (MUXSW_VOUT); also elsewhere on the board
/Power/VDDA_1.8V: C90.1, TP14.1, U3.6 (LDO3_VOUT); also elsewhere on the board
/Power/VDD_ARM_0.9V: C101.1, C102.1, L2.2, TP19.1, U3.24 (BUCK2_FB); also elsewhere on the board
/Power/VDD_DRAM_xPU_0.9V: C99.1, C100.1, L3.2, TP20.1, U3.30 (BUCK5_FB); also elsewhere on the board
/Power/VDD_PHY_0.9V: C88.1, TP12.1, U3.42 (LDO4_VOUT); also elsewhere on the board
/Power/VDD_PHY_1.2V: C89.1, TP13.1, U3.44 (LDO6_VOUT); also elsewhere on the board
/Power/VDD_SOC_0.8V: C103.1, C105.1, L1.2, TP18.1, U3.17 (BUCK1_FB); also elsewhere on the board
/Power/VSYS_5V: C70.1, C71.1, C72.1, C76.1, C77.1, C78.1, C79.1, C80.1, C81.1, C82.1, C83.1, C84.1, U3.5 (VSYS), U3.9 (VSYS), U3.18 (BUCK1_VIN), U3.23 (BUCK2_VIN), U3.31 (BUCK5_VIN), U3.32 (BUCK5_VIN), U3.37 (BUCK8_VIN), U3.41 (VSYS), U3.47 (BUCK6_VIN), U3.48 (BUCK6_VIN), U3.53 (BUCK7_VIN), U4.1 (IN); also elsewhere on the board
/Power/~PWRON: R16.1, R18.2, U3.40 (~PWRON)
/Power/~WDOG: R17.2, TP22.1, U3.2 (~WDOG)
GND: C70.2, C71.2, C72.2, C73.2, C74.2, C75.2, C76.2, C77.2, C78.2, C79.2, C80.2, C81.2, C82.2, C83.2, C84.2, C85.2, C86.2, C87.2, C88.2, C89.2, C90.2, C91.2, C92.2, C93.2, C94.2, C95.2, C96.2, C97.2, C98.2, C99.2, C100.2, C101.2, C102.2, C103.2, C104.2, C105.2, C106.2, C107.2, C108.2, R13.2, SW1.2, TP3.1, TP4.1, TP5.1, TP6.1, U3.12 (AGND), U3.57 (PGND), U3.58 (PGND), U3.59 (PGND), U3.60 (PGND), U3.61 (PGND), U4.2 (GND); also elsewhere on the board
unnamed: C104.1, R14.1, U3.14 (XIN), Y1.1
unnamed: C106.1, R14.2, U3.13 (XOUT), Y1.2
unnamed: R15.2, R16.2, SW1.1
VDD_1.8V: C73.1, C75.1, C95.1, C96.1, L5.2, R17.1, TP8.1, U3.43 (VIN_1P8_1), U3.54 (BUCK7_FB), U3.56 (VIN_1P8_2), U4.3 (EN); also elsewhere on the board
VDD_3.3V: C74.1, C97.1, C98.1, L4.2, TP7.1, U3.1 (VIN_3P3), U3.7 (VIN_3P3), U3.46 (BUCK6_FB); also elsewhere on the board

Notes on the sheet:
0.8V 10mA
1.2V 300mA
0.9V 250mA
I2C Address: 0x4B
0.9V -> 0.85V/0.95V/1.0V 3A
3.3V 3A
0.9V -> 0.975V 3A
1.8V 300mA
1.8V 1.5A
1.8V 10mA
3.3V/1.8V 150mA
1.1V -> 1.2V 3A
0.8V -> 0.85V 3A

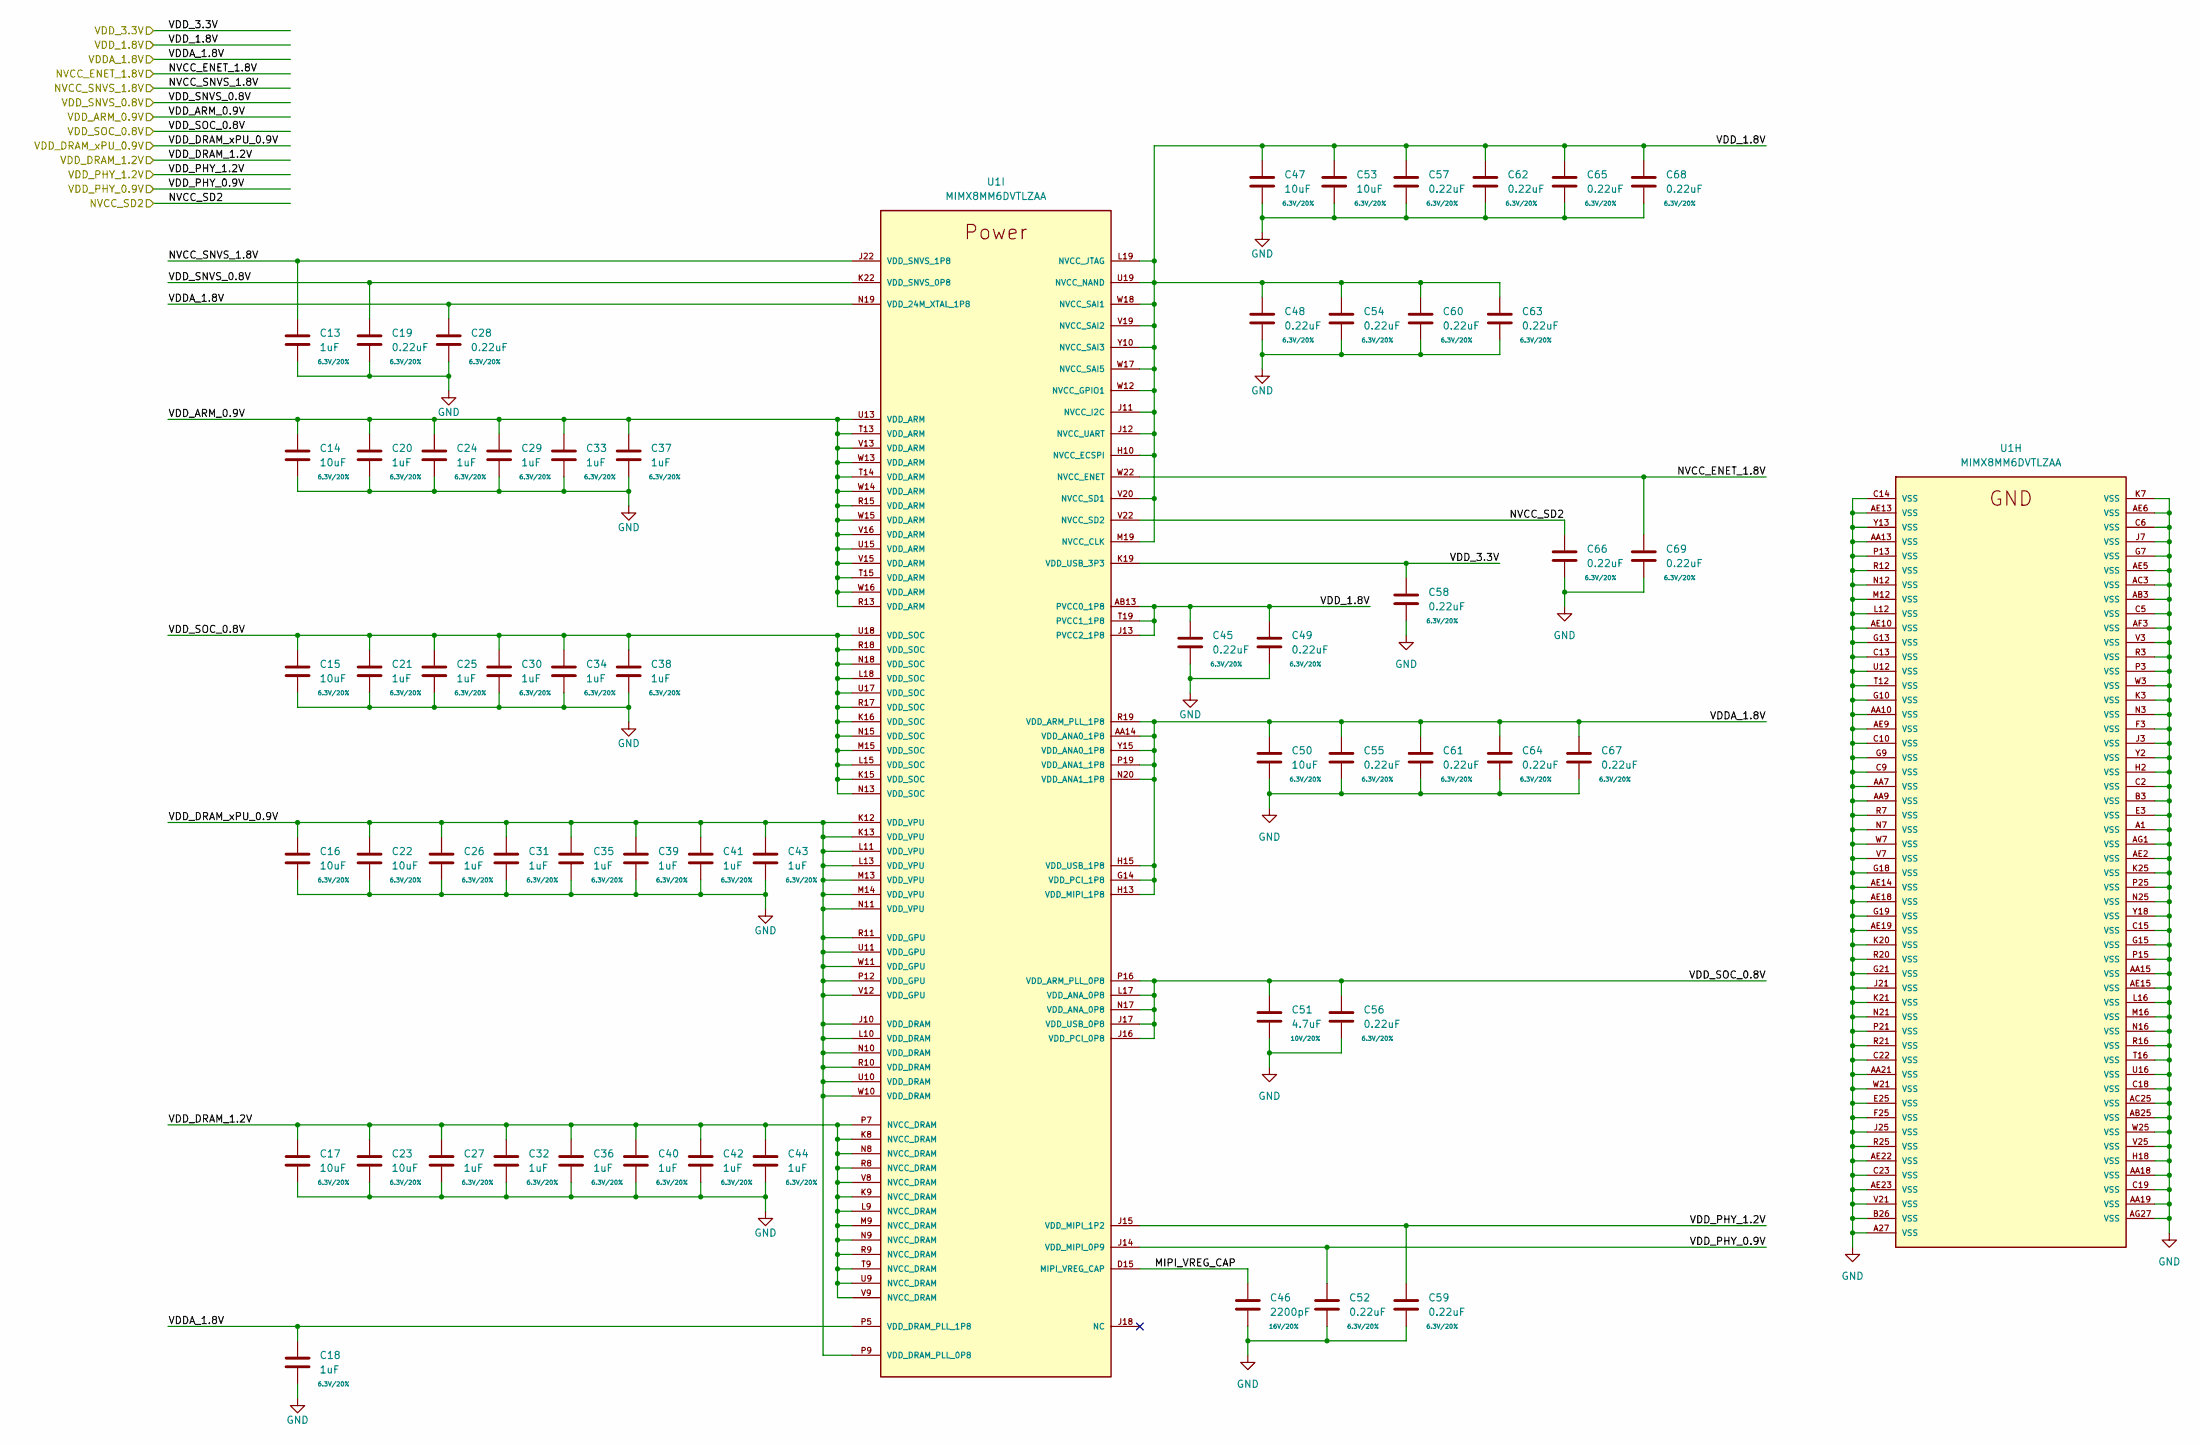
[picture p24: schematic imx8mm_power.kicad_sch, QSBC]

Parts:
C13, C18, C20, C21, C24, C25, C26, C27, C29, C30, C31, C32, C33, C34, C35, C36, C37, C38, C39, C40, C41, C42, C43, C44: 1uF; C_0201_0603Metric; Rating 6.3V/20%
C14, C15, C16, C17, C22, C23, C47, C50, C53: 10uF; C_0402_1005Metric; Rating 6.3V/20%
C19, C28, C45, C48, C49, C52, C54, C55, C56, C57, C58, C59, C60, C61, C62, C63, C64, C65, C66, C67, C68, C69: 0.22uF; C_0201_0603Metric; Rating 6.3V/20%
C46: 2200pF; C_0402_1005Metric; Rating 16V/20%
C51: 4.7uF; C_0402_1005Metric; Rating 10V/20%
U1: MIMX8MM6DVTLZAA; SOT1967-1

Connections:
/DDR/VDD_DRAM_1.2V: C17.1, C23.1, C27.1, C32.1, C36.1, C40.1, C42.1, C44.1, U1.K8 (NVCC_DRAM), U1.K9 (NVCC_DRAM), U1.L9 (NVCC_DRAM), U1.M9 (NVCC_DRAM), U1.N8 (NVCC_DRAM), U1.N9 (NVCC_DRAM), U1.P7 (NVCC_DRAM), U1.R8 (NVCC_DRAM), U1.R9 (NVCC_DRAM), U1.T9 (NVCC_DRAM), U1.U9 (NVCC_DRAM), U1.V8 (NVCC_DRAM), U1.V9 (NVCC_DRAM); also elsewhere on the board
/Ethernet/NVCC_ENET_1.8V: C69.1, U1.W22 (NVCC_ENET); also elsewhere on the board
/Misc/NVCC_SNVS_1.8V: C13.1, U1.J22 (VDD_SNVS_1P8); also elsewhere on the board
/Misc/VDD_SNVS_0.8V: C19.1, U1.K22 (VDD_SNVS_0P8); also elsewhere on the board
/Power/NVCC_SD2: C66.1, U1.V22 (NVCC_SD2); also elsewhere on the board
/Power/VDDA_1.8V: C18.1, C28.1, C50.1, C55.1, C61.1, C64.1, C67.1, U1.AA14 (VDD_ANA0_1P8), U1.G14 (VDD_PCI_1P8), U1.H13 (VDD_MIPI_1P8), U1.H15 (VDD_USB_1P8), U1.N19 (VDD_24M_XTAL_1P8), U1.N20 (VDD_ANA1_1P8), U1.P5 (VDD_DRAM_PLL_1P8), U1.P19 (VDD_ANA1_1P8), U1.R19 (VDD_ARM_PLL_1P8), U1.Y15 (VDD_ANA0_1P8); also elsewhere on the board
/Power/VDD_ARM_0.9V: C14.1, C20.1, C24.1, C29.1, C33.1, C37.1, U1.R13 (VDD_ARM), U1.R15 (VDD_ARM), U1.T13 (VDD_ARM), U1.T14 (VDD_ARM), U1.T15 (VDD_ARM), U1.U13 (VDD_ARM), U1.U15 (VDD_ARM), U1.V13 (VDD_ARM), U1.V15 (VDD_ARM), U1.V16 (VDD_ARM), U1.W13 (VDD_ARM), U1.W14 (VDD_ARM), U1.W15 (VDD_ARM), U1.W16 (VDD_ARM); also elsewhere on the board
/Power/VDD_DRAM_xPU_0.9V: C16.1, C22.1, C26.1, C31.1, C35.1, C39.1, C41.1, C43.1, U1.J10 (VDD_DRAM), U1.K12 (VDD_VPU), U1.K13 (VDD_VPU), U1.L10 (VDD_DRAM), U1.L11 (VDD_VPU), U1.L13 (VDD_VPU), U1.M13 (VDD_VPU), U1.M14 (VDD_VPU), U1.N10 (VDD_DRAM), U1.N11 (VDD_VPU), U1.P9 (VDD_DRAM_PLL_0P8), U1.P12 (VDD_GPU), U1.R10 (VDD_DRAM), U1.R11 (VDD_GPU), U1.U10 (VDD_DRAM), U1.U11 (VDD_GPU), U1.V12 (VDD_GPU), U1.W10 (VDD_DRAM), U1.W11 (VDD_GPU); also elsewhere on the board
/Power/VDD_PHY_0.9V: C52.1, U1.J14 (VDD_MIPI_0P9); also elsewhere on the board
/Power/VDD_PHY_1.2V: C59.1, U1.J15 (VDD_MIPI_1P2); also elsewhere on the board
/Power/VDD_SOC_0.8V: C15.1, C21.1, C25.1, C30.1, C34.1, C38.1, C51.1, C56.1, U1.J16 (VDD_PCI_0P8), U1.J17 (VDD_USB_0P8), U1.K15 (VDD_SOC), U1.K16 (VDD_SOC), U1.L15 (VDD_SOC), U1.L17 (VDD_ANA_0P8), U1.L18 (VDD_SOC), U1.M15 (VDD_SOC), U1.N13 (VDD_SOC), U1.N15 (VDD_SOC), U1.N17 (VDD_ANA_0P8), U1.N18 (VDD_SOC), U1.P16 (VDD_ARM_PLL_0P8), U1.R17 (VDD_SOC), U1.R18 (VDD_SOC), U1.U17 (VDD_SOC), U1.U18 (VDD_SOC); also elsewhere on the board
/i.MX8MM Power/MIPI_VREG_CAP: C46.1, U1.D15 (MIPI_VREG_CAP)
GND: C13.2, C14.2, C15.2, C16.2, C17.2, C18.2, C19.2, C20.2, C21.2, C22.2, C23.2, C24.2, C25.2, C26.2, C27.2, C28.2, C29.2, C30.2, C31.2, C32.2, C33.2, C34.2, C35.2, C36.2, C37.2, C38.2, C39.2, C40.2, C41.2, C42.2, C43.2, C44.2, C45.2, C46.2, C47.2, C48.2, C49.2, C50.2, C51.2, C52.2, C53.2, C54.2, C55.2, C56.2, C57.2, C58.2, C59.2, C60.2, C61.2, C62.2, C63.2, C64.2, C65.2, C66.2, C67.2, C68.2, C69.2, U1.A1 (VSS), U1.A27 (VSS), U1.AA7 (VSS), U1.AA9 (VSS), U1.AA10 (VSS), U1.AA13 (VSS), U1.AA15 (VSS), U1.AA18 (VSS), U1.AA19 (VSS), U1.AA21 (VSS), U1.AB3 (VSS), U1.AB25 (VSS), U1.AC3 (VSS), U1.AC25 (VSS), U1.AE2 (VSS), U1.AE5 (VSS), U1.AE6 (VSS), U1.AE9 (VSS), U1.AE10 (VSS), U1.AE13 (VSS), U1.AE14 (VSS), U1.AE15 (VSS), U1.AE18 (VSS), U1.AE19 (VSS), U1.AE22 (VSS), U1.AE23 (VSS), U1.AF3 (VSS), U1.AG1 (VSS), U1.AG27 (VSS), U1.B3 (VSS), U1.B26 (VSS), U1.C2 (VSS), U1.C5 (VSS), U1.C6 (VSS), U1.C9 (VSS), U1.C10 (VSS), U1.C13 (VSS), U1.C14 (VSS), U1.C15 (VSS), U1.C18 (VSS), U1.C19 (VSS), U1.C22 (VSS), U1.C23 (VSS), U1.E3 (VSS), U1.E25 (VSS), U1.F3 (VSS), U1.F25 (VSS), U1.G7 (VSS), U1.G9 (VSS), U1.G10 (VSS), U1.G13 (VSS), U1.G15 (VSS), U1.G18 (VSS), U1.G19 (VSS), U1.G21 (VSS), U1.H2 (VSS), U1.H18 (VSS), U1.J3 (VSS), U1.J7 (VSS), U1.J21 (VSS), U1.J25 (VSS), U1.K3 (VSS), U1.K7 (VSS), U1.K20 (VSS), U1.K21 (VSS), U1.K25 (VSS), U1.L12 (VSS), U1.L16 (VSS), U1.M12 (VSS), U1.M16 (VSS), U1.N3 (VSS), U1.N7 (VSS), U1.N12 (VSS), U1.N16 (VSS), U1.N21 (VSS), U1.N25 (VSS), U1.P3 (VSS), U1.P13 (VSS), U1.P15 (VSS), U1.P21 (VSS), U1.P25 (VSS), U1.R3 (VSS), U1.R7 (VSS), U1.R12 (VSS), U1.R16 (VSS), U1.R20 (VSS), U1.R21 (VSS), U1.R25 (VSS), U1.T12 (VSS), U1.T16 (VSS), U1.U12 (VSS), U1.U16 (VSS), U1.V3 (VSS), U1.V7 (VSS), U1.V21 (VSS), U1.V25 (VSS), U1.W3 (VSS), U1.W7 (VSS), U1.W21 (VSS), U1.W25 (VSS), U1.Y2 (VSS), U1.Y13 (VSS), U1.Y18 (VSS); also elsewhere on the board
VDD_1.8V: C45.1, C47.1, C48.1, C49.1, C53.1, C54.1, C57.1, C60.1, C62.1, C63.1, C65.1, C68.1, U1.AB13 (PVCC0_1P8), U1.H10 (NVCC_ECSPI), U1.J11 (NVCC_I2C), U1.J12 (NVCC_UART), U1.J13 (PVCC2_1P8), U1.L19 (NVCC_JTAG), U1.M19 (NVCC_CLK), U1.T19 (PVCC1_1P8), U1.U19 (NVCC_NAND), U1.V19 (NVCC_SAI2), U1.V20 (NVCC_SD1), U1.W12 (NVCC_GPIO1), U1.W17 (NVCC_SAI5), U1.W18 (NVCC_SAI1), U1.Y10 (NVCC_SAI3); also elsewhere on the board
VDD_3.3V: C58.1, U1.K19 (VDD_USB_3P3); also elsewhere on the board

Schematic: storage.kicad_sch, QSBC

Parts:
C142: 18pF; C_0201_0603Metric; Rating ??V/??%
C143: 10uF; C_0402_1005Metric; Rating 6.3V/20%
C144, C145, C147: 0.1uF; C_0402_1005Metric; Rating 25V/20%
C146: 1uF; C_0402_1005Metric; Rating 10V/20%
J6: Micro_SD_Card_Det1; GCT_MEM2051-00-195-00-A_REVC
R80, R83, R84: 10K; R_0402_1005Metric; Rating 50mW/1%; MPN RC0402JR-0710KL; DigiKey_PN 311-10KJRCT-ND
R81: 0R; R_0201_0603Metric
R82: 10K; R_0402_1005Metric; Rating 50mW/1%
U1: MIMX8MM6DVTLZAA; SOT1967-1
U25, U29: TPD4EUSB30; USON-10_2.5x1.0mm_P0.5mm
U26: D5V0H1B2LP; DFN100X60X45-2N
U27: W25Q32JWZP; WSON-8-1EP_6x5mm_P1.27mm_EP3.4x4.3mm
U28: SiP32431DR3; SOT-363_SC-70-6

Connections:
/Power/NVCC_SD2: R80.1, R83.1, R84.1; also elsewhere on the board
/Storage/QSPI_CLK: U1.N22 (NAND_ALE), U27.6 (CLK)
/Storage/QSPI_DATA0: U1.P23 (NAND_DATA00), U27.5 (DI(IO0))
/Storage/QSPI_DATA1: U1.K24 (NAND_DATA01), U27.2 (DO(IO1))
/Storage/QSPI_DATA2: U1.K23 (NAND_DATA02), U27.3 (IO2)
/Storage/QSPI_DATA3: U1.N23 (NAND_DATA03), U27.7 (IO3)
/Storage/SD2_CLK: J6.5 (CLK), R81.2, U29.1 (D1+), U29.10
/Storage/SD2_CLK_R: R81.1, U1.W23 (SD2_CLK)
/Storage/SD2_CMD: J6.3 (CMD), R84.2, U1.W24 (SD2_CMD), U29.2 (D1-), U29.9
/Storage/SD2_DATA0: J6.7 (DAT0), R83.2, U1.AB23 (SD2_DATA0), U25.4 (D2+), U25.7
/Storage/SD2_DATA1: J6.8 (DAT1), U1.AB24 (SD2_DATA1), U25.2 (D1-), U25.9
/Storage/SD2_DATA2: J6.1 (DAT2), U1.V24 (SD2_DATA2), U29.4 (D2+), U29.7
/Storage/SD2_DATA3: J6.2 (DAT3/CD), U1.V23 (SD2_DATA3), U25.5 (D2-), U25.6
/Storage/VDD_SD2: C143.1, C144.1, C147.1, J6.4 (VDD), U26.2, U28.1 (OUT)
/Storage/~QSPI_CS: R82.2, U1.N24 (NAND_CE0_B), U27.1 (~CS)
/Storage/~SD2_CD: J6.10 (DET), U1.AA26 (SD2_CD_B), U25.1 (D1+), U25.10
/Storage/~SD2_RESET: R80.2, U1.AB26 (SD2_RESET_B), U28.3 (ON)
GND: C142.2, C143.2, C144.2, C145.2, C146.2, C147.2, J6.6 (VSS), J6.9 (SHIELD), U25.3 (GND), U25.8 (GND), U26.1, U27.4 (GND), U27.9 (EP), U28.2 (GND), U28.5 (GND), U29.3 (GND), U29.8 (GND); also elsewhere on the board
unnamed: C142.1, U1.R22 (NAND_DQS)
VDD_1.8V: C145.1, R82.1, U27.8 (VCC); also elsewhere on the board
VDD_3.3V: C146.1, U28.4 (IN); also elsewhere on the board

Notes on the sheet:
TODO: Find Best Value

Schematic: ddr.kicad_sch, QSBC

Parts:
C1: 0.22uF; C_0201_0603Metric; Rating 10V/20%
C2, C3, C4, C5, C8, C9, C10, C11: 4.7uF; C_0402_1005Metric; Rating 10V/20%
C6, C7: 1uF; C_0402_1005Metric; Rating 10V/20%
C12: 0.01uF; C_0201_0603Metric; Rating 6.3V/20%
R1, R10: 240R; R_0201_0603Metric; Rating 50mW/1%
R2, R3, R4: 43R; R_0201_0603Metric; Rating 50mW/1%
R5: 10K; R_0402_1005Metric; Rating 50mW/1%
R6, R7, R8, R9: 0R; R_0201_0603Metric
R11, R12: 1K; R_0402_1005Metric; Rating 50mW/1%
TP1: TestPoint; TestPoint_Pad_D0.4mm
TP2: TestPoint; TestPoint_Pad_D1.0mm
U1: MIMX8MM6DVTLZAA; SOT1967-1
U2: MT40A1G16KD-062E; MICRON-FBGA-96

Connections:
/DDR/DRAM_A00: U1.AD5 (DRAM_AC31), U2.P3 (A0)
/DDR/DRAM_A01: U1.U1 (DRAM_AC25), U2.P7 (A1)
/DDR/DRAM_A02: U1.U2 (DRAM_AC24), U2.R3 (A2)
/DDR/DRAM_A03: U1.N6 (DRAM_AC15), U2.N7 (A3)
/DDR/DRAM_A04: U1.K5 (DRAM_AC14), U2.N3 (A4)
/DDR/DRAM_A05: U1.N5 (DRAM_AC13), U2.P8 (A5)
/DDR/DRAM_A06: U1.N4 (DRAM_AC12), U2.P2 (A6)
/DDR/DRAM_A07: U1.E4 (DRAM_AC10), U2.R8 (A7)
/DDR/DRAM_A08: U1.D5 (DRAM_AC11), U2.R2 (A8)
/DDR/DRAM_A09: U1.J5 (DRAM_AC07), U2.R7 (A9)
/DDR/DRAM_A10: U1.AC4 (DRAM_AC30), U2.M3 (A10/AP)
/DDR/DRAM_A11: U1.K6 (DRAM_AC09), U2.T2 (A11)
/DDR/DRAM_A12: U1.J6 (DRAM_AC08), U2.M7 (A12/BC_N)
/DDR/DRAM_A13: U1.W6 (DRAM_AC28), U2.T8 (A13)
/DDR/DRAM_A14: U1.T1 (DRAM_AC34), U2.L2 (WE_N/A14)
/DDR/DRAM_A15: U1.R5 (DRAM_AC33), U2.M8 (CAS_N/A15)
/DDR/DRAM_A16: U1.T2 (DRAM_AC35), U2.L8 (RAS_N/A16)
/DDR/DRAM_BA0: U1.V6 (DRAM_AC29), U2.N2 (BA0)
/DDR/DRAM_BA1: U1.N1 (DRAM_AC26), U2.N8 (BA1)
/DDR/DRAM_BG0: U1.L2 (DRAM_AC04), U2.M2 (BG0)
/DDR/DRAM_BG1: R6.1, U1.L1 (DRAM_AC05)
/DDR/DRAM_CKE: U1.F4 (DRAM_AC00), U2.K2 (CKE)
/DDR/DRAM_CK_N: R2.2, U1.M2 (DRAM_AC17), U2.K8 (CK_C)
/DDR/DRAM_CK_P: R3.2, U1.M1 (DRAM_AC16), U2.K7 (CK_T)
/DDR/DRAM_D00: U1.A5 (DRAM_DQ00), U2.G2 (LDQ0)
/DDR/DRAM_D01: U1.B5 (DRAM_DQ01), U2.H2 (LDQ4)
/DDR/DRAM_D02: U1.D2 (DRAM_DQ02), U2.H7 (LDQ3)
/DDR/DRAM_D03: U1.D1 (DRAM_DQ03), U2.H8 (LDQ5)
/DDR/DRAM_D04: U1.C1 (DRAM_DQ04), U2.F7 (LDQ1)
/DDR/DRAM_D05: U1.B1 (DRAM_DQ05), U2.J7 (LDQ7)
/DDR/DRAM_D06: U1.A3 (DRAM_DQ06), U2.J3 (LDQ6)
/DDR/DRAM_D07: U1.B4 (DRAM_DQ07), U2.H3 (LDQ2)
/DDR/DRAM_D08: U1.F2 (DRAM_DQ08), U2.C3 (UDQ10)
/DDR/DRAM_D09: U1.G2 (DRAM_DQ09), U2.D3 (UDQ14)
/DDR/DRAM_D10: U1.J1 (DRAM_DQ10), U2.C7 (UDQ11)
/DDR/DRAM_D11: U1.J2 (DRAM_DQ11), U2.B8 (UDQ9)
/DDR/DRAM_D12: U1.K2 (DRAM_DQ12), U2.C8 (UDQ13)
/DDR/DRAM_D13: U1.K1 (DRAM_DQ13), U2.D7 (UDQ15)
/DDR/DRAM_D14: U1.E1 (DRAM_DQ14), U2.C2 (UDQ12)
/DDR/DRAM_D15: U1.E2 (DRAM_DQ15), U2.A3 (UDQ8)
/DDR/DRAM_DMI0: U1.A4 (DRAM_DM0), U2.E7 (NF/LDBI_N/LDM_N)
/DDR/DRAM_DMI1: U1.F1 (DRAM_DM1), U2.E2 (NF/UDBI_N/UDM_N)
/DDR/DRAM_DQS0_N: U1.B2 (DRAM_DQS0_N), U2.F3 (LDQS_C)
/DDR/DRAM_DQS0_P: U1.A2 (DRAM_DQS0_P), U2.G3 (LDQS_T)
/DDR/DRAM_DQS1_N: U1.H1 (DRAM_DQS1_N), U2.A7 (UDQS_C)
/DDR/DRAM_DQS1_P: U1.G1 (DRAM_DQS1_P), U2.B7 (UDQS_T)
/DDR/DRAM_ODT: U1.V5 (DRAM_AC36), U2.K3 (ODT)
/DDR/DRAM_PARITY: U1.R6 (DRAM_AC27), U2.T3 (PAR)
/DDR/DRAM_VREF: C6.2, C7.1, C12.1, R11.1, R12.2, TP2.1, U2.M1 (VREFCA)
/DDR/DRAM_ZN: R1.2, U1.P2 (DRAM_ZN)
/DDR/PHY_VREF: TP1.1, U1.P1 (DRAM_VREF)
/DDR/VDD_DRAM_1.2V: C2.1, C3.1, C4.1, C5.1, C6.1, C8.1, C10.1, R4.2, R11.2, U2.A1 (VDDQ1), U2.A9 (VDDQ2), U2.B3 (VDD1), U2.B9 (VDD2), U2.C1 (VDDQ3), U2.D1 (VDD3), U2.D9 (VDDQ4), U2.F2 (VDDQ5), U2.F8 (VDDQ6), U2.G1 (VDDQ7), U2.G7 (VDD4), U2.G9 (VDDQ8), U2.J1 (VDD5), U2.J2 (VDDQ9), U2.J8 (VDDQ10), U2.J9 (VDD6), U2.L1 (VDD7), U2.L9 (VDD8), U2.R1 (VDD9), U2.T9 (VDD10); also elsewhere on the board
/DDR/VPP_2.5V: C9.1, C11.1, U2.B1 (VPP1), U2.R9 (VPP2); also elsewhere on the board
/DDR/~DRAM_ACT: U1.F6 (DRAM_AC06), U2.L3 (ACT_N)
/DDR/~DRAM_ALERT: R4.1, U1.R2 (DRAM_ALERT_N), U2.P9 (ALERT_N)
/DDR/~DRAM_CS0: U1.K4 (DRAM_AC02), U2.L7 (CS_N)
/DDR/~DRAM_RESET: R5.2, U1.R1 (DRAM_RESET_N), U2.P1 (RESET_N)
GND: C1.2, C2.2, C3.2, C4.2, C5.2, C7.2, C8.2, C9.2, C10.2, C11.2, C12.2, R1.1, R5.1, R7.2, R8.2, R9.2, R10.1, R12.1, U2.A2 (VSSQ1), U2.A8 (VSSQ2), U2.B2 (VSS1), U2.C9 (VSSQ3), U2.D2 (VSSQ4), U2.D8 (VSSQ5), U2.E1 (VSS2), U2.E3 (VSSQ6), U2.E8 (VSSQ7), U2.F1 (VSSQ8), U2.G8 (VSS3), U2.H1 (VSSQ9), U2.H9 (VSSQ10), U2.K1 (VSS4), U2.K9 (VSS5), U2.N1 (VSS6), U2.N9 (TEN), U2.T1 (VSS7); also elsewhere on the board
unnamed: C1.1, R2.1, R3.1
unnamed: R6.2, R7.1, U2.M9 (VSS8)
unnamed: R8.1, U2.E9 (VSS9)
unnamed: R9.1, U2.T7 (NF/NC)
unnamed: R10.2, U2.F9 (ZQ)

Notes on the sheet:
240R
Single Die
Type
DNP
Dual Die



Board: 8 copper layers, 80.0 x 80.0 mm, 388 parts (28 on the bottom side), 281 nets.

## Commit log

2022-05-07 inital commit
    [ddr.kicad_sch, ethernet.kicad_sch, imx8mn_power.kicad_sch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]
2022-05-08 move to i.MX8M Mini
    [ethernet.kicad_sch, imx8mm_power.kicad_sch, imx8mn_power.kicad_sch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]
2022-05-08 ddr sch done
    [ddr.kicad_sch, ethernet.kicad_sch, imx8mm_power.kicad_sch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]
2022-06-04 misc work, usb sch done
    [ddr.kicad_sch, ethernet.kicad_sch, imx8mm_power.kicad_sch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]
2022-06-26 enet sch done, other misc sch work
    [ethernet.kicad_sch, imx8mm_power.kicad_sch, pcie.kicad_sch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]
2022-06-26 enet: add hierarchial labels
    [ethernet.kicad_sch, qsbc.kicad_sch]
2022-07-01 pcie done, misc fixes for usb, enet
    [ethernet.kicad_sch, imx8mm_power.kicad_sch, pcie.kicad_sch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]
2022-07-02 storage done, peri work, misc fixes
    [ddr.kicad_sch, imx8mm_power.kicad_sch, pcie.kicad_sch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]
2022-07-09 ddr: add dual die support, misc work
    [ddr.kicad_sch, ethernet.kicad_sch, imx8mm_power.kicad_sch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]
2022-07-09 fix ref desgigators, add table for dram config
    [ddr.kicad_sch, ethernet.kicad_sch, imx8mm_power.kicad_sch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]
2022-07-09 add ddr vpp ldo, fix ddr net names
    [ddr.kicad_sch, power.kicad_sch, qsbc.kicad_sch]
2022-07-26 add inital ddr tool version, lots of routing work
    [DDR_flytimes.xlsx, ddr.kicad_sch, ethernet.kicad_sch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]
2022-08-01 v2 of ddr flytimes tool, lots of routing work, sch fixes
    [DDR_flytimes.xlsx, ddr.kicad_sch, ethernet.kicad_sch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]
2022-08-06 more routing work, prepare to change to x32 lpddr4
    [DDR_flytimes.xlsx, ethernet.kicad_sch, pcie.kicad_sch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]
2022-08-07 inital routing of ddr data bus, sch work
    [ddr.kicad_sch, ddr_power.kicad_sch, ethernet.kicad_sch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]
2022-08-26 README.md: specs: add m.2 slot
2022-09-09 add SN65DSI86 DSI2DP ic, SCH, PCB work, flytime work
    [DDR_flytimes.xlsx, ddr.kicad_sch, ddr_power.kicad_sch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]
2022-09-10 add UART4 connector
    [ddr_power.kicad_sch, displayport.kicad_sch, misc.kicad_sch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]
2022-09-18 change USB-UART conn, add new 0402 fp, more pcb work
    [ddr_power.kicad_sch, displayport.kicad_sch, ethernet.kicad_sch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]
2022-09-18 place imx8mm/lpddr4 decoupling caps, lib cleanup
    [qsbc.kicad_sch, usb.kicad_sch]
2022-09-25 place / route SOC/DDR decoupling caps
    [qsbc.kicad_sch, usb.kicad_sch]
2022-09-25 swap usb ctrl signals for layout
    [misc.kicad_sch, peripherals.kicad_sch, power.kicad_sch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]
2022-10-08 pmic routing almost done
    [ethernet.kicad_sch, peripherals.kicad_sch, power.kicad_sch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]
2022-10-08 most of routing done
    [imx8mm_power.kicad_sch, qsbc.kicad_sch]
2022-10-09 v2 of flytime tool
    [DDR_flytimes.xlsx]
2022-10-16 misc length matching, cleanup files
    [DDR_flytimes.xlsx, flytimes.xlsx]
2022-10-17 DDR_A length matching done
    [flytimes.xlsx]
2022-10-24 more delay matching, update drc rules for better clearance
    [flytimes.xlsx]
2022-11-02 length matched DDR_A addr, cmd, ctrl, and byte 0
    [flytimes.xlsx]
2022-11-02 length matched DDR_A byte 1
    [flytimes.xlsx]
2022-11-03 length matched DDR_B byte 1
    [flytimes.xlsx]
2022-11-03 length matched DDR_B byte 0
    [flytimes.xlsx]
2022-11-03 fix some drc errors in ddr area
    [flytimes.xlsx]
2022-11-03 small sch fixes / cleanup
    [displayport.kicad_sch, ethernet.kicad_sch, imx8mm_power.kicad_sch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]
2022-11-05 bom work, change uart level shifter and m.2 socket
    [ddr.kicad_sch, ddr_power.kicad_sch, displayport.kicad_sch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]
2022-11-05 fix missing power connection
2022-11-05 add gnd zones to outter layers, DP conn fix
2022-11-06 ddr length matching work, misc cleanup
    [ddr_power.kicad_sch, displayport.kicad_sch, ethernet.kicad_sch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]
2022-11-19 misc cleanup, change from usb mux to dual uart
    [ddr.kicad_sch, ddr_power.kicad_sch, displayport.kicad_sch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]
2022-11-20 more pcb cleanup, zone work
2022-11-20 add imx8mm 3d model, add FIDs
    [ddr.kicad_sch, ddr_power.kicad_sch, qsbc.kicad_sch]
2022-11-23 change power traces to 0.2mm, misc fixes
    [ddr.kicad_sch, flytimes.xlsx, usb.kicad_sch]
2022-11-23 power track thickness fixes, move TPs to back of board
2022-12-18 Rev 1
    [ddr.kicad_sch, ddr_power.kicad_sch, displayport.kicad_sch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]
2023-01-18 misc changes for rev1
    [ddr.kicad_sch, displayport.kicad_sch, ethernet.kicad_sch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]
2023-01-18 update README with board pics and info
2023-01-18 add pdf of rev 1.0 schematics, remove bom.ini
2023-01-20 dsi86: en is active high
    [displayport.kicad_sch, peripherals.kicad_sch, power.kicad_sch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]
2023-02-19 fixup qwiic con p/n, fixup dnp and values based on testing
    [peripherals.kicad_sch, qsbc.kicad_sch, storage.kicad_sch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]
2023-02-20 update project to kicad 7.0.0
    [ddr.kicad_sch, ddr_power.kicad_sch, displayport.kicad_sch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]
2023-02-20 update sch datestamp, update schematic pdf
    [ddr.kicad_sch, ddr_power.kicad_sch, displayport.kicad_sch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]
2023-02-26 misc bom cleanup
    [imx8mm_power.kicad_sch, power.kicad_sch, qsbc.kicad_sch]
2023-02-26 reduce board image sizes
2023-05-30 misc bom updates / fixes based on testing
    [ddr_power.kicad_sch, peripherals.kicad_sch, power.kicad_sch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]
